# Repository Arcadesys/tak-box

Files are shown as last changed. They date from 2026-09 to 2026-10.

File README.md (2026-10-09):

# Tak box

A 3D-printed travel case for a 5 × 5 game of Tak, with interchangeable themed piece sets for custom gifts. The original pieces are Team Cat / Team Witch. Printed in PLA on an Elegoo Centauri Carbon 2.

## V26 — captive main hinges and tab-free boards

The corrected main hinges have a printed axle fixed between two supports on one half, trapping the other half’s central moving barrel. [Review the hinge section](v26/previews/17-main-hinge-section.png) and [print guide](v26/START-HERE.md).

[Review V26](v26/START-HERE.md) or inspect [the corrected kit](v26/V26-PRINT-KIT.zip). Three full plates contain the PIP case bodies with fixed guides and a captive hook, the full-size four-colour board pair, and optional matching flat capstones. Open the hook, then pull the boards freely; rigid seating shoulders replace the flexible release tabs. Modest 4 mm case and 2 mm board corner rounds retain the full field and original pieces. The user chose full plates before physical trials; strength, comfort and loaded transport still need observation. Earlier V25 kits and the V26 clip-trial archive are preserved.

## Preserved V25 PIP with fixed piece guides

The latest [fixed-guide prototype](v25/PIP-FIXED-GUIDES/START-HERE.md) has permanent positions for 21 flat stones and a capstone in each case half, joined to 3.4 mm integral floors. No removable trays. The two halves print together with captive 4 mm PIP pivots and full-height 8 mm roots. Original piece capacity, playing field, accent colours and outside size are retained. Digital checks do not establish physical fit, dumping or strength; cover-catch, lip and rounded-cover complete integration remain open. The earlier empty-well PIP plate, filament kits and V24 stay preserved.

## Preserved V25 square pockets and captive three-knuckle hinges

[The preserved prototype](v25/PIP-SQUARE-POCKETS/START-HERE.md) restores 21 square stone holders and a capstone holder per half, integrated into the 3.4 mm floor. Each hinge has two stationary outer knuckles joined by a 4 mm integral post, with the moving knuckle captured between them. Both halves print together as one assembly. The full field, pieces and outside size stay the same. Physical release, strength and transport remain unverified; cover-catch, broad lip and rounded-cover integration remain open. Earlier V25 kits and V24 are preserved.

## Current print kit: V24

[Download V24](v24/V24-PRINT-KIT.zip) and read [START-HERE](v24/START-HERE.md). Following the reported V23 hinge-support break, this revision uses broader full-height supports and two removable loaded player trays. The full 180 mm field remains; closed size is **102.5×200×35 mm**, adding 1.5 mm at the larger hinge barrels and 2.4 mm thickness for independent tray floors. Open **v24/FULL-PRINT** for the four sliced projects; **02-FULL-SIZE-FOUR-COLOUR-inlaid-boards-CC2-PLA.3mf** is the full board pair. Small tests are together in **v24/SMALL-TRIALS**. Four CC2 PLA plates include the **four-colour inlaid boards** (black, white and two silk accents), about **17 h 1 min / 327 g** with placeholder silk profiles; select actual silk profiles and reslice before printing. Separate hinge, tray-access and colour trials are included; physical durability and fit remain pending.

Replace both bases, both boards and the hook; add both trays. Existing original flats, supplied flat capstones and hook collar retain their geometry. The accepted celestial artwork is now adapted to V24 corner geometry and included in its default board project and assembled previews. See [the V24 checkpoint](docs/V24_CHECKPOINT.md).

V24 retains the previously delivered V23 R2 mechanics; this surface integration changes its board material geometry and slicing. The [V23 R2 kit](v23-r2/release/tak-v23-r2-print-kit.zip) remains preserved.

## Preserved V23 baseline

[Download the V23 print kit](v23/release/tak-v23-print-kit.zip), then open **v23/START-HERE.md**. Three CC2 PLA projects are together in **v23/PRINT**, with eight parts estimated at **11 h 38 min / 272 g**.

V23 is the accepted seamless-exterior design: centered recessed hook/catch/pivot, recessed board finger wells and rounded integrated hinge ends. It is a version-identity correction of the already checked design; geometry, printer settings and print behavior are unchanged. Closed envelope: **101×200×32.6 mm**, with the full 180 mm field, original 42 flats and solid 8 mm Cat/Witch capstones beneath sliding boards. Main hinges print captive; only the hook uses a filament pivot.

Replace both bases, both boards, hook and collar relative to original V22; flat capstones are unchanged. Prior CAD/motion/slice results are reused with equivalence evidence and a fresh package audit. Physical comfort, snag resistance, release, fit and loaded transport remain untested. The kit includes separate 26-minute hinge and 53-minute closure trials. See the [guide](v23/START-HERE.md) and [checkpoint](docs/V23_CHECKPOINT.md).

[Original V22](v22/START-HERE.md) is restored to the 111.8×220.2×32.6 mm corner-hook design; its [ZIP](v22/release/tak-v22-print-kit.zip) is unchanged. The previously V22-labelled seamless delivery is [archived](v22/release/archive/README.md). [V21](v21/START-HERE.md), [V20](v20/START-HERE.md), [V19](v19/START-HERE.md) and [V18](v18-case/README.md) remain historical and intact.

## Historical v17 architecture study: [four leaves on one common hinge](v17-four-leaf)

Two drawer housings and two board leaves share one hinge axis. Covered
sliding drawers keep flats enclosed while the leaves rotate. Board leaves
snap implementation was completed in v18; the [two-piece squeeze buckle](v17-squeeze-latch)
is historical. The 180 mm field and 36 mm pitch remain.

This is a CAD motion study, **not a full-print release**. Paired folding,
independent board rotation, original-flat envelopes, solids and exported
meshes pass the recorded sampled checks. Board snaps, drawer releases,
rear capstone hatch and case-closure integration remain unfinished. The
previous four-part draw-latch trial was rejected as confusing.
The main body is provisionally 101×236×32.6 mm, excluding closure hardware;
it is thinner but longer than v16. No final size saving is claimed yet.

The [screw-clamped draft](v17-compact-folio) was rejected and is history only.
The later pin/sleeve idea was also rejected; it is not the selected closure.

## Previous travel prototype: [v16 field book](v16-field-book)

The separate [full-size pagoda foundation](full-size-pagoda-v1/README.md) uses
25 × 25 × 10 mm weighted flats, scaled existing Fox/Cat capstones and a lift-out
5×5 board above two stacked trays. It is the new premium printed exploration;
v16 remains the travel prototype. Digital geometry and local slicing pass;
physical fit and transport retention remain untested.

The additive [compact home-board variant](home-board-compact-v1/README.md)
reduces both footprint and height to 240 × 232 × 43 mm by placing two narrower
cassettes side by side. The same 42 mm cells and full-size pieces are retained.
Digital geometry and local slicing pass; printed handling remains untested.

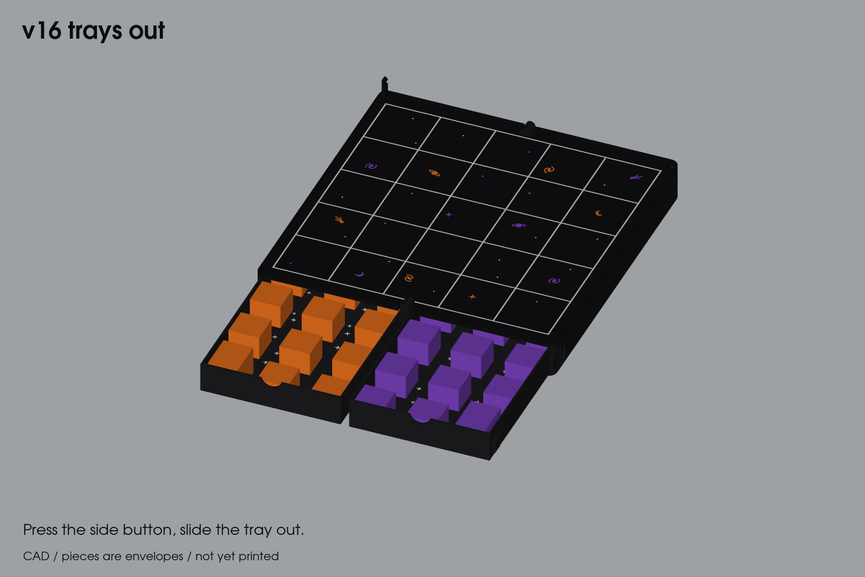
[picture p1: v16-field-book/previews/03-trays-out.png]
v16 open with trays out


The board folds in half with its face inside, and there's a snap-in piece tray under each half.
- **Closing:** a buckle at the far edge. Squeeze the side of the case to open it.
- **Board:** 5 × 5 at 36 mm cells, black with an inlaid white grid and subtle star, galaxy, planet, moon and comet inlays. A raised lip protects paint.
- **Assembly:** the board plates drop onto locating pegs and glue into shallow wells, so they line up without a jig.
- **Size:** 101 × 202 × 51 mm closed.

It has four multi-colour print plates. The user reports physical piece-retention
and closure failures; the exact printed component revisions are unknown.
See the [v16 README](v16-field-book/README.md) for retained plates and source;
its blanket unprinted statement is historical and superseded by those reports.

## Pieces: [pieces](pieces)

Piece designs live in separate packages so custom sets can share the box. Check each package's dimensions and tray compatibility before printing; the packages currently use different stone sizes.

The Cat and Witch flats and capstones, with CAD source, STLs and one CC2 print plate per team in [pieces/plates](pieces/plates).

The [weighted stone prototype](pieces/weighted-v1/README.md) adds 20 × 20 × 6 mm two-part stones for post-print ballast and epoxied floors, with a three-clearance fit coupon and one complete geometry plate per team. Physical fit and feel remain untested.

The [piece generator v1](pieces/piece-generator-v1/README.md) systematizes custom weighted teams from TOML presets: recessed engraving, side texture, solved ballast volume, a low-profile capstone, and a positive snap floor backed by adhesive. It generates a complete team plate plus a three-variant snap-fit coupon. CAD and mesh checks are automated; physical snap retention and tactile acceptance remain untested.

The [fox knurled flats](pieces/fox-knurled-v1/README.md) add 21 fox-themed 19.5 × 19.5 × 8 mm stones with recessed face emblems and diamond-textured sides. Sample and full-set CC2 plates are included. Geometry fits the current tray insert; physical fit and grip await a sample print.

The [reference-based Fox and Cat capstones](pieces/fox-cat-capstones-v4/README.md) follow a continuous carved nose-to-tail curl. This package contains the fuller Fox tail and the Cat's corrected neck/shoulder, printable STLs, a labeled two-object 3MF, retained reconstruction sources and large labeled previews. Digital v16 compatibility and dry slicing pass; physical fit and tactile acceptance remain untested.

## Archive

- [archive/v15-field-book](archive/v15-field-book): 28 mm cells. Too small to play on: you couldn't grab a stack once the board filled up.
- [archive/v14-field-book](archive/v14-field-book): the first field book, with 24 mm cells. A paper play test showed it was too cramped.
- [archive/v13-book](archive/v13-book): the first two-leaf book, with the M3 clasp.
- [archive/v5-v7](archive/v5-v7): the earlier open-wells, pin-board, hinge-coupon and center-closure designs, with their scripts, coupons and plates. Its [README](archive/v5-v7/README.md) describes v5.

Versions v11 (smooth case) and v12 (chest) live on their own branches: `feat/tak-v11-smooth-case` and `feat/tak-v12-chest`.

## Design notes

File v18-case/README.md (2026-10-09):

# V18 full build — side hook and filament hinges

**Print these five CC2-PLA projects for the complete case.** The user selected the simple side hook and pin on October 5. All four main leaves retain their common hinge axis and the full 180 mm playing field. [Download the complete kit](release/tak-v18-hook-and-pin-CC2-PLA.zip).

This is the first full print of this revision. The earlier clasp trial was printed; the new side hook and complete case have not been physically accepted. No printer job was started.

## Five print plates

| Plate | Contents | Orientation |
|---|---|---|
| [01 — Left housing](plates/01-left-housing-hook-pivot-and-cap-compartment-CC2-PLA.3mf) | Housing, hook pivot, capstone compartment and fixed hatch hinge | Rear end down |
| [02 — Right housing](plates/02-right-housing-and-hook-pin-CC2-PLA.3mf) | Housing and headed hook pin | Rear end down |
| [03 — Boards](plates/03-board-leaves-CC2-PLA.3mf) | Both board leaves and external release clips | Playing faces up |
| [04 — Drawers](plates/04-piece-drawers-CC2-PLA.3mf) | Both 21-flat drawers, catches, stops and grips | On their sides |
| [05 — Hatch and small parts](plates/05-hatch-hook-and-five-axle-caps-CC2-PLA.3mf) | Hatch, separate side hook and five axle collars | Hatch axis upright; hook flat; collar bores upright |

**13 printed parts, five plates.** Use this kit together: the previous clasp slider is not used. Existing v16 interfaces stay unchanged. The previous 3 mm axle kit remains archived.

## Printer settings

- **Elegoo Centauri Carbon 2, 0.4 mm nozzle**, 256 mm build volume.
- Retained starting material: **Generic PLA, 210 °C nozzle / 60 °C textured PEI**. Select the actual tested spool preset and reslice if it differs.
- **0.20 mm layers, four requested walls, 20% gyroid, 6 mm brim**, automatic normal supports, 30° support threshold, three upper interface layers and 0.20 mm contact gaps. Housing objects use 0.8 mm side clearance from supports; other parts use 0.35 mm. Preserve these object settings when reslicing. Thin spring sections resolve as solid narrow walls.
- Keep the supplied orientations. Housings print rear end down to keep supports out of the drawer tunnels. The hook prints flat. Do not scale the parts to adjust fit.
- The slicer retains a warning: Generic PLA has a 45 °C softening entry against a 60 °C bed. These are starting settings, not a qualified spool profile.

The retained profile estimates **32 h 18 min / 499 g** total, including support and brims. See [slicing.json](reports/slicing.json) for individual plates.

Fill the recessed grid with a high contrast finish, such as opaque white on a dark board. Keep paint within the 0.6 mm grooves so the playing surface stays flat.

## Cut four filament pins

Use straight, undamaged **1.75 mm PLA filament**. Cut square and remove burrs:

| Location | Length | Printed collars |
|---|---:|---:|
| Front main hinge | 24.9 mm | 1 |
| Rear main hinge | 24.9 mm | 1 |
| Capstone hatch | 92.0 mm | 2 |
| Side-hook pivot | 9.6 mm | 1 |

Main, hatch and hook bores are nominally **2.0 mm**; collar bores are **1.9 mm through holes**. These are design clearances, not measured printed fits. Check each bore with a short filament segment before assembly; it must pass without force.

## Assembly

1. Remove supports and brims. Check the drawer tunnels, board clips, pin bores, headed catch and hook throat. Deburr gently; do not round off retaining shoulders.
2. Arrange **left housing, left board, right board, right housing** flat, with their individual hinge knuckles interleaved along the common axis. Capstones go at the rear and drawer grips at the front.
3. Insert the two 24.9 mm main pins from the outside ends. Each outer collar receives approximately 2 mm of filament and sits about 0.5 mm clear of the barrel. The pins end short of the playing field. Dry-fit every leaf first. To stop withdrawal, bond each pin only at its exposed outer housing barrel: **left housing at the front, right housing at the rear**. Keep adhesive out of the other three moving leaves. Bond the collars to the pins. The passages have no hidden internal stops.
4. Fit the hatch between its rear ears, insert the 92 mm pin and bond that pin at one fixed housing ear only. Bond both collars to the pin with approximately 2 mm insertion and 0.5 mm clearance from the ears. The hatch must rotate freely.
5. Fit the side hook on the left housing pivot, with its mouth facing the rear when upright. Insert its 9.6 mm filament pin from outside and bond the inner end in the fixed mount. Fit the outer collar with approximately 2 mm insertion. Unlike the main hinges, this collar **lightly contacts the hook**: set it for smooth thumb movement with enough friction to hold its position, then bond it to the pin. Keep adhesive off the hook and bearing faces. There is no spring detent; check this friction after repeated use.
6. Insert each drawer from the front. Press its rear stop arm inward to pass the housing stop, then release it. Press the broad outer catch while seating the drawer fully; it must latch before folding.
7. Pull both external board clips outward while lowering each board onto its housing; release them into their pockets. Both playing faces must sit flat.
8. Test the empty case, then load the exact original Cat/Witch set. Use [ACCEPTANCE.md](ACCEPTANCE.md) to record fit, comfortable release and loaded retention. Do not force a sticking joint.

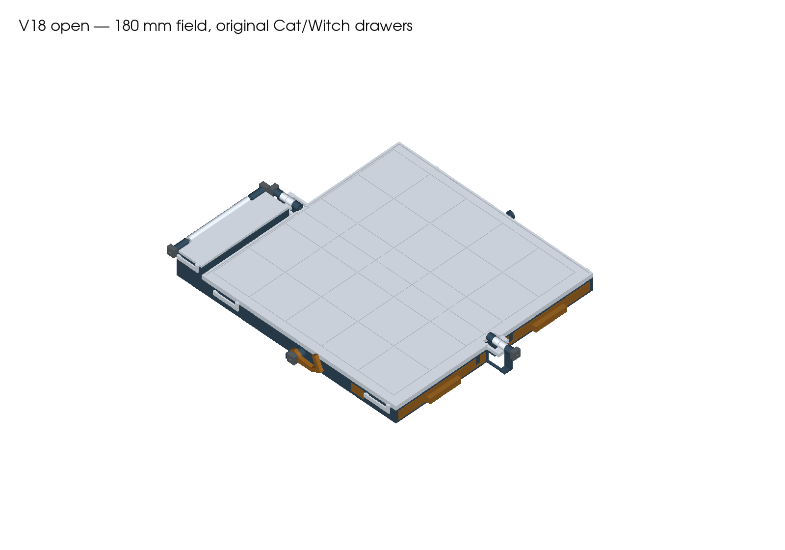
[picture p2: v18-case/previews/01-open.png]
Full case open, rendered from exported geometry


## Close and open

Seat both drawers, close the hatch and engage both boards. Swing the side hook toward the drawer end, fold the right housing and board closed together, then swing the hook upright over the headed pin. The pin's head keeps the hook from slipping off sideways; the hook shoulder blocks separation.

To open, gently squeeze the case halves together to unload the hook, then swing it **65° toward the drawer end** using the broad tab. Unfold the right pair. The hook has a reverse stop and an adjustable friction pivot. Physical testing must establish whether that friction reliably prevents accidental rotation during carrying; the digital opening check establishes geometric engagement only.

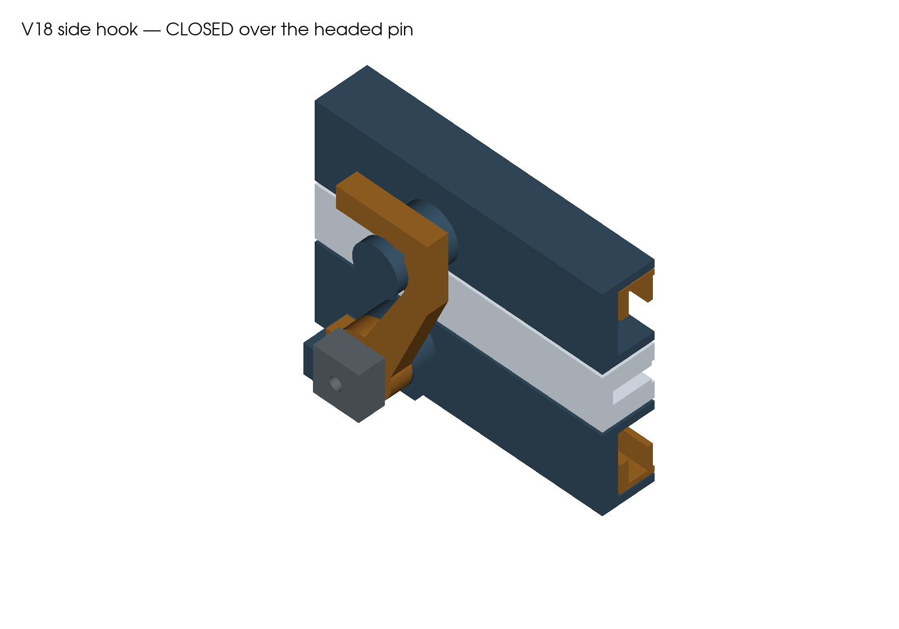
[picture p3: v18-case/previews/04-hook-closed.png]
Side hook closed

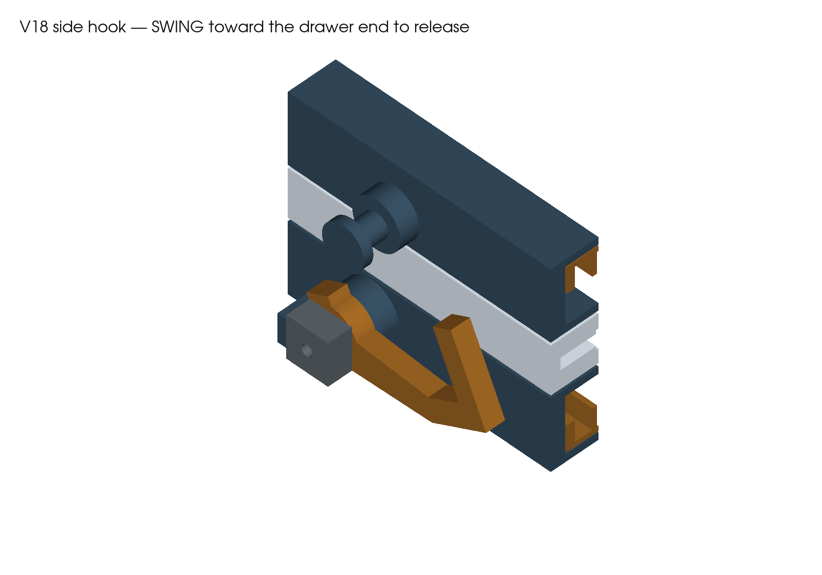
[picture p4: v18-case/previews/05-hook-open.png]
Side hook released


- **Drawers:** press the broad side button and pull the front grip. The stop at 168 mm exposes all 21 flats. Support the drawer on the table. To remove it deliberately, press the rear stop arm inward as it reaches the opening.
- **Board maintenance:** release both clips before rotating a board independently; leave them engaged during normal play and folding.
- **Capstones:** pull the external hatch clip outward and lift the hatch. Two 12 mm floor ports allow an upward finger push to aid retrieval.

## Pieces and compatibility

The field remains **5×5, 180 mm across, 36 mm pitch**. This build checks detailed original Cat/Witch CAD from `pieces/tak_pieces.py`: 42 flats at **20×20×8 mm**, 20.7 mm seats and 0.4 mm roof clearance. The original capstones lie in the rear compartment. The original Cat capstone STL has an open mesh, so its valid detailed CAD is used for fit checks. No piece exports changed.

Weighted flats and curled Fox/Cat capstones remain unverified here; the existing weighted-stone/current-insert mismatch stays explicit. V16 parts and the premium pagoda are separate. The earlier trial clasp is retained as history. New housings and filament-bore parts replace the previous integrated clasp/3 mm axle geometry; the drawers retain their dimensions.

Closed envelope including all hardware: approximately **112.3 × 245.8 × 32.6 mm**. The playing field has not been reduced.

## Evidence and reproduction

The reports check valid single solids, STEP/STL and named-object 3MF readback, original-piece fit, sampled loaded folding and releases, hook engagement, filament hardware clearances and actual sliced pin passages. Sampled motion is not a continuous sweep proof. Spring deflection poses do not establish force or fatigue. First-print fit, support removal, strength and transport retention remain physical tests.

Use Python 3.12 with [requirements.txt](requirements.txt), plus installed macOS ElegooSlicer:

```sh
python v18-case/source/build_case.py
python v18-case/source/verify_field.py
python v18-case/source/verify_hardware.py
python v18-case/source/package_case.py
python v18-case/source/slice_case.py
python v18-case/source/render_case.py
python v18-case/source/inspect_case_layers.py
python v18-case/source/verify_pin_toolpaths.py
python v18-case/source/record_provenance.py
python v18-case/source/package_release.py
python scripts/verify_v18_freeze.py
```

After rendering new toolpaths, review them and record observations in `reports/layer-inspection.json` before running the provenance check. Current commands, environment, limitations and repaired failures are in [BUILD-PROVENANCE.md](BUILD-PROVENANCE.md). Source and final payload hashes are pinned in the manifest. The original recessed-clasp package remains byte-for-byte frozen.

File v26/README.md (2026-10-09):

# V26 print plates — captive main hinges and tab-free boards

The main hinges now use the user-confirmed arrangement: each **4 mm printed axle permanently joins two supports on the fixed half**, trapping a **3.2 mm central moving barrel** on the opposite half. Each fixed support is **2.5 mm wide**, with **9 mm outer barrels**, full-height **8 mm roots** and nominal **0.4 mm radial and face gaps**. The case prints as one captive assembly.

[Start printing V26](START-HERE.md) or [download the complete kit](V26-PRINT-KIT.zip). **FULL-PRINT** contains the joined case/hook assembly, the full four-colour board pair and the matching flat capstones. Current total estimate: **17h 46m / 288.66 g PLA**, including the optional capstones.

V26 adds modest outside corner rounds: **4 mm on the case** and **2 mm on the sliding boards**. The inlays, full field and hinge supports stay intact. Review the [corner detail](previews/18-rounded-corner.png).

V26 removes the flexible sliding-board catches. Opening the captive case hook lets the boards slide outward without pressing a release tab. Each board has a rigid **4 × 6.1 × 4.7 mm seating shoulder** outside the playing field; it meets the front rail to stop inward travel and moves away from the rail during withdrawal. The original bevelled board margin replaces the old clip window.

The hook uses a **4 mm fixed axle**, two fixed cheeks, a **2 mm outer cheek** and a **3.4 mm frame bridge**, with nominal **0.4 mm radial and face gaps**. Its broader bearing and integral printing foot print parked at 90° with the case. PIP main hinges, **3.4 mm floors**, **21 flat guides plus one capstone guide per side**, the full **180 mm / 36 mm-cell field**, original four-colour inlays and **102.5 × 200 × 35 mm** closed size remain. No loose hook pin/collar or removable tray.

Clearance checks use **42 original Cat/Witch 20 × 20 × 8 mm flats and the two supplied 8 mm V23 flat capstones**. Weighted and sculpted pieces are not qualified. Replace the V24/V25 bodies and covers for this integrated kit; the original flats and supplied flat capstones retain their geometry. The new covers retain the V26 mechanism-review case/hook interface in CAD.

The user explicitly chose full plates before small physical trials. The revised main hinge passes **947 integrated solid, loaded slide/fold, capture, seating-stop and export checks**, **51 exported geometry audits**, **15 named mesh/3MF readbacks**, and **37 sliced main-hinge/hook gap and support checks**. Sliced support-face gaps are at least **0.32 mm** under a conservative 0.50 mm bead-width assumption. The rounded board and capstone plates are rebuilt from exported CAD with **62 plate checks**; all four inlay roles retain their original geometry. Reports identify current source, project and profile hashes. Physical strength, wear, comfort and loaded transport remain unobserved. No printer job is dispatched. The earlier rounded-cover underside request remains pending.

Build with the bundled dependency versions in `reports/full-provenance.json`: CadQuery 2.7 / Python 3.12 and ElegooSlicer 2.4.2 on the recorded host. Run `source/build.py`, `source/plates_full.py`, `source/verify_review.py`, `source/slice_full.py`, `source/verify_colour.py`, `source/render.py`, `source/package_full.py`. `source/slice_full.py --verify-only` reads back existing full projects without reslicing. Full source, reference STEP parts, profiles, named meshes, raw plates and checks are retained with the kit.

[Game](previews/01-game-open.png) · [Tab removed](previews/02-board-clip.png) · [Hook cutaway](previews/04-hook-section.png) · [Closed](previews/05-closed.png) · [Fixed guides](previews/06-fixed-guides.png).

The earlier [mechanism review archive](V26-MECHANISM-REVIEW.zip), individual trials and combined clip/hook trial are preserved unchanged as history. Their flexible clip is superseded by the current tab-free covers. Rebuild those historical trials from the source inside that archive, rather than the current `source/build.py`. All V25 packages and the user extraction remain intact.

The superseded opposed-pivot full kit and case project are preserved under `archive/previous-main-hinge`. Current geometry evidence is `reports/geometry.json` and `build-double-supported-rounded.log`; `build-double-supported.log` records the pre-rounding captive hinge and `build-full.log` records the earlier tab-free build. The isolated ZIP check audits all payloads and rebuilds board/capstone raw plates from bundled STEP references; it does not independently rerun the full case CAD or slicer.

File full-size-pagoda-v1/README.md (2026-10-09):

# Full-size Tak — pagoda foundation

An additive board-and-storage foundation for the exceptionally ornate printed
direction: **a clear 5×5 board above two removable, stacked piece cassettes**.
Existing v16 parts and all older piece packages are unchanged. This is the shape
to constrain future witch-and-cat, energy-vine and galactic ornament.

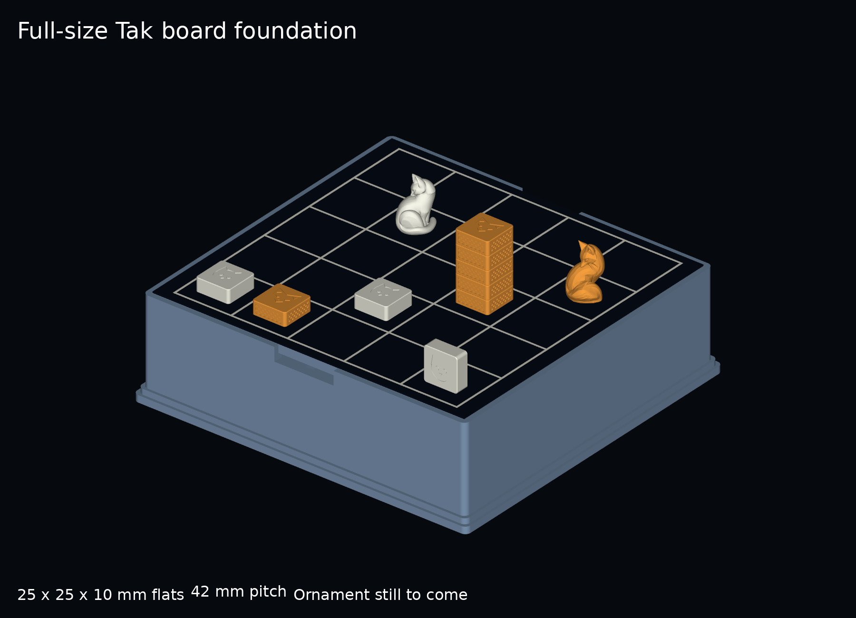
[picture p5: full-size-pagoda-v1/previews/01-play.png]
Actual geometry with full-size pieces


## Dimensions

| Component | Dimensions in mm | Status |
| --- | --- | --- |
| Cat, Fox and optional Witch flats | 25 × 25 × 10 finished envelope | Exact CAD envelope; body, closure and felt allowance included |
| Playing field | 210 × 210; 5×5 at 42 mm pitch | 17 mm between adjacent centered 25 mm flats |
| Lift-out board backing | 232 × 224 × 6 | 0.3 mm seat clearance per side; broad front/back grips |
| Each player cassette | 120 × 174 × 30 body; 31 including locating pins | 21 flats and one sideways capstone; print twice |
| Printed platform | 248 × 240 × 72 | Three low stepped terraces; removable board above storage |
| Felt playing surface | 1 mm allowance; top at 73 mm | Measure actual felt plus adhesive before assembly |
| Cat capstone | 21.785 × 25 × 33.809 | Uniformly scaled final Cat v4 sculpture |
| Fox capstone | 22.694 × 24.782 × 35 | Uniformly scaled final Fox v3 sculpture |

The capstones retain their carved looking-back curl and remain taller than
the square flat stones. Their proportions are preserved by uniform scaling;
their existing solid construction remains. Capstone ballast cavities are a
separate unresolved design step.

## Pieces and closure

The Cat/Witch emblems come from `pieces/tak_pieces.py`. The Fox emblem and side
knurl come from `pieces/fox-knurled-v1/source/flats.py`, scaled to the new size.
All three regular stones use the weighted package's two-part closure approach,
adapted to 25 mm width and 10 mm finished height. The Fox knurl remains recessed,
so it adds no width. The cavities accept post-print ballast. Select fill and
adhesive using handling samples; kinetic sand is the requested material.

The nominal stone has a 1 mm closure floor starting 0.7 mm above the base,
a 0.6 mm felt patch, and 0.1 mm adhesive allowance. The body rim and felt finish
at z=0; the top finishes at z=10. Minimum roof below the 0.5 mm emblem recess
is 1 mm. The floor locates with **0.2 mm clearance per side** and a 0.1 mm
shoulder adhesive gap. These are CAD allowances, not measured printed fits.

Print bodies broad top down and cavity up using `*-body-print.stl`; the
`*-body-assembly.stl` files are upright assembly references. Floors print flat,
locating tongue up. Do not print the felt or assembled STEP references as a
single fused object.

## Files and first sample

- [Closure coupon](plates/closure-coupon.3mf): three Cat bodies and three floors
  with 0.15, 0.20 and 0.25 mm side clearance, labeled in the 3MF object names.
  Keep each printed floor associated with its object label.
- [21 Cat bodies](plates/cat-flats-21.3mf) and [21 Fox bodies](plates/fox-flats-21.3mf).
- [21 floors](plates/floors-21.3mf): print two copies for the full Cat/Fox set.
- [Fox/Cat capstones](plates/fox-cat-capstones.3mf): two scaled existing sculptures.
- [Piece cassette](plates/tray.3mf): print two copies; the existing `tray` filename is retained.
- [Platform](plates/platform.3mf).
- [Felt backing](plates/board-felt-backing.3mf): flat support for the felt surface.
- [Grooved board option](plates/board-grooved-option.3mf): separate alternative,
  with 1.4 mm wide, 0.6 mm deep grid grooves; finish them in a contrasting colour.
- [Full-scale grid](models/felt-grid-100-percent.svg): 232 × 224 mm, for a
  print/stencil/transfer onto the felt. Print at 100% and measure the 42 mm pitch.

These tracked 3MFs contain **named millimetre geometry**, without embedded print
settings or G-code. Local sliced proof projects are in ignored `.slicer-work/`.
Individual STL and editable STEP files are in `models/`; sculptural capstones
remain mesh source, as in their original package.

Start with the closure coupon, two Fox bodies, one capstone pair and one tray.
Check the finished felt thickness, fill retention, grip, stacking, standing-wall
stability, capstone pocket fit and support cleanup. Check full five-stone carries
on the 42 mm printed paper grid before committing to the platform.

## Setup and reserved space

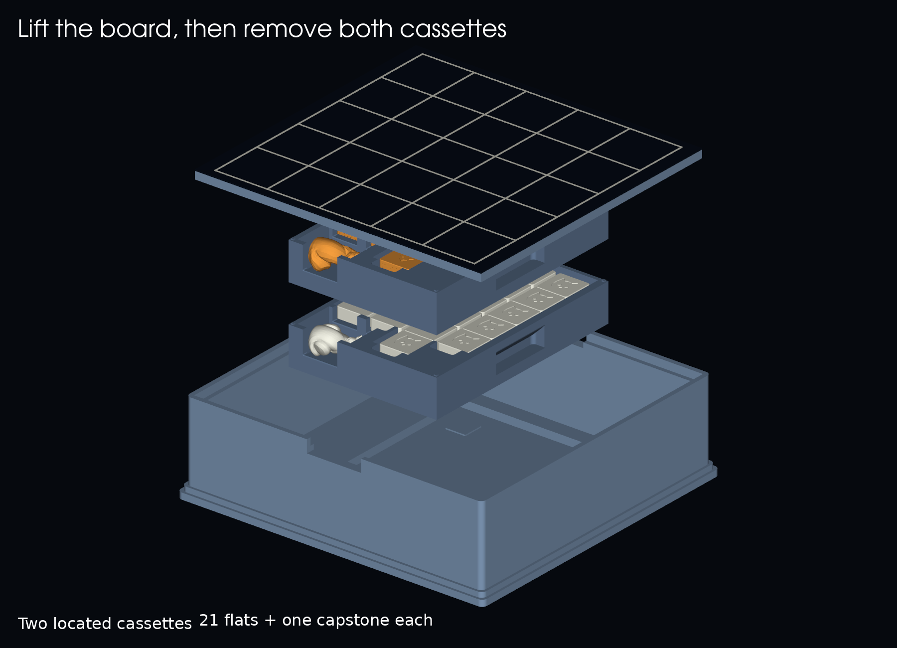
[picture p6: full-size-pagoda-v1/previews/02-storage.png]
Board and loaded trays separated vertically


Lift the board using the two 44 mm front/back grip openings, remove the upper
then lower cassette, set them beside the platform and reseat the board for play.
Each cassette carries one player's 21 flats and capstone. **These are open
carriers in this revision**, covered by the upper cassette and board when
packed; they do not have separate lids.

The flat rows hold **5 + 5 + 6 + 5 stones**. The third row extends forward
beside the capstone; there is no separate 21st-flat pocket. Its slot is 151 mm
long, while the five-flat slots are 126 mm long, each leaving 1 mm total end
clearance. The capstone compartment footprint and cassette outside dimensions stay the same.

**Raised flat seats:** the lane floors are at z=18 mm rather than z=2 mm.
Finished flats reach z=28 mm, just **2 mm below the 30 mm perimeter rim**.
They project 8 mm above the dividers. A 20 mm wide finger notch at the front
of each row exposes 8 mm of the first stone's edge, so it can be lifted without
digging into a deep well. Test actual
finger access, especially after some stones have been removed, before a batch.

**Capstone access:** the capstone floor is raised from z=2 to z=5 mm. A **28 mm
wide opening** through the cassette's front wall exposes the curled body from
the side. Its lower edge is at z=12 mm, leaving approximately 15 mm of the
capstone above that edge. The Cat and Fox tops are respectively 3.2 and 2.3 mm
below the rim. Grasp the body through this opening, rather than hooking an ear
or tail tip. Shape, plan position and the 43 × 32 mm pocket footprint are retained.

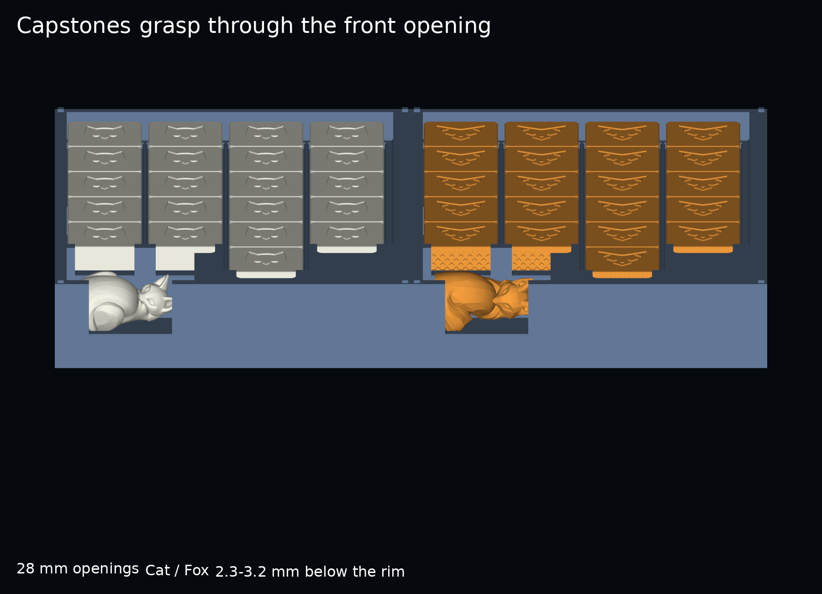
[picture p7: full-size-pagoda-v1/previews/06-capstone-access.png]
Cat on left and Fox on right, accessible through the front openings


The lower cassette rests on four 16 mm square supports within a low locating
frame. The frame leaves 0.4 mm clearance per side. The upper cassette rests
on the lower perimeter rim, with four 2 mm square, 1 mm high pins entering
2.8 mm square, 1.2 mm deep sockets in its underside. These locate the stack
without a latch; both cassettes lift straight up. There is no cushioning yet.

**Cassette comfort revision:** dividers finish at z=20 mm, leaving 8 mm of
flat edge exposed as rows empty. The divider tops, row-front openings and
capstone finger ledge have 0.5 mm chamfers. Two side recesses replace the
previous shallow dishes: each is nominally 50 mm wide and 10 mm deep, with its
mouth from z=8 to z=24 mm. The 45-degree roof slopes down inward, leaving a
4 mm seat thickness at its deepest point and a nominal 6 mm rim above the
mouth before the 0.5 mm edge chamfer.
The long upper mouth edges also have 0.5 mm chamfers. These are recessed grips
for a two-handed lift; they add no outside width.

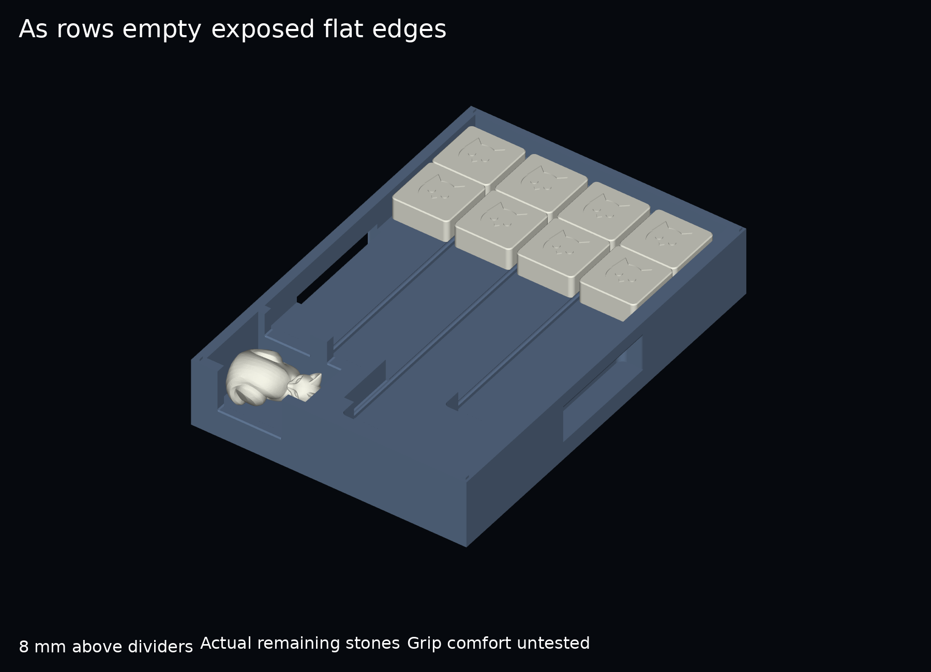
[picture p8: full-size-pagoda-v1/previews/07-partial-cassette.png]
Partly emptied cassette with exposed flat edges


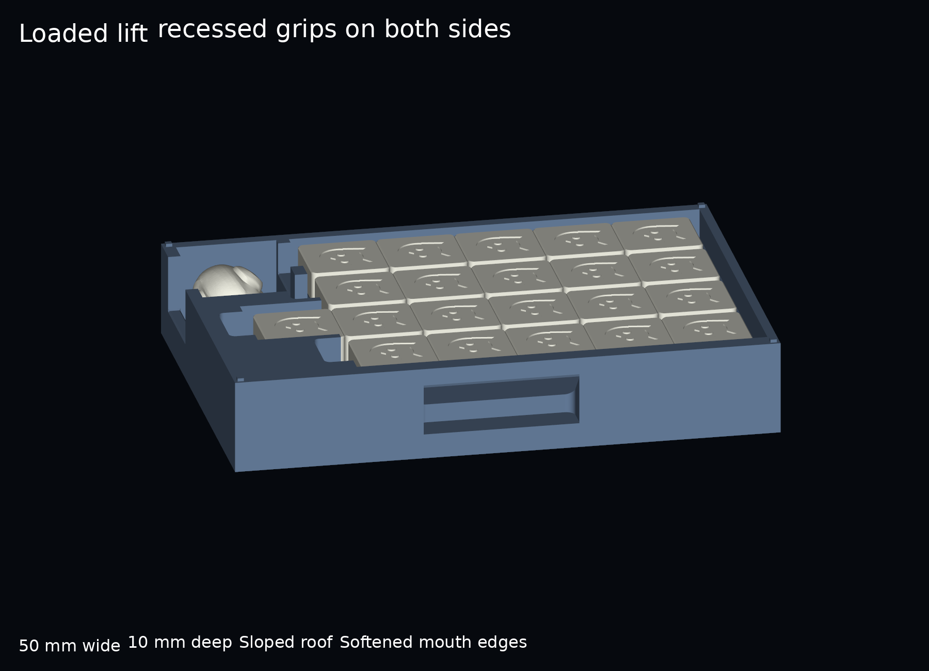
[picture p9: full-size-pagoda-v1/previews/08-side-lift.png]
Loaded cassette and broad side grip


The new cassette retains the previous outside size, capstone seats and stack
pins/sockets. It digitally registers with the previous cassette and platform;
printed compatibility remains untested. First print **one revised cassette**,
load all 21 finished flats and a capstone, then test a two-handed lift, removing
the first/middle/last stones, capstone body grasp and stacking/release against
an existing cassette if available. Check for flex at the grip rail before a
second print; stop if there is cracking, discomfort or unstable retention.

Both capstones lie below the next cassette floor, leaving at least 2.3 mm
modeled headroom. The upper rim is 2 mm below the board backing, and its
locating pins remain 1 mm below it. All flats remain 25 × 25 × 10 mm and have
2 mm modeled clearance beneath the next cassette's underside.

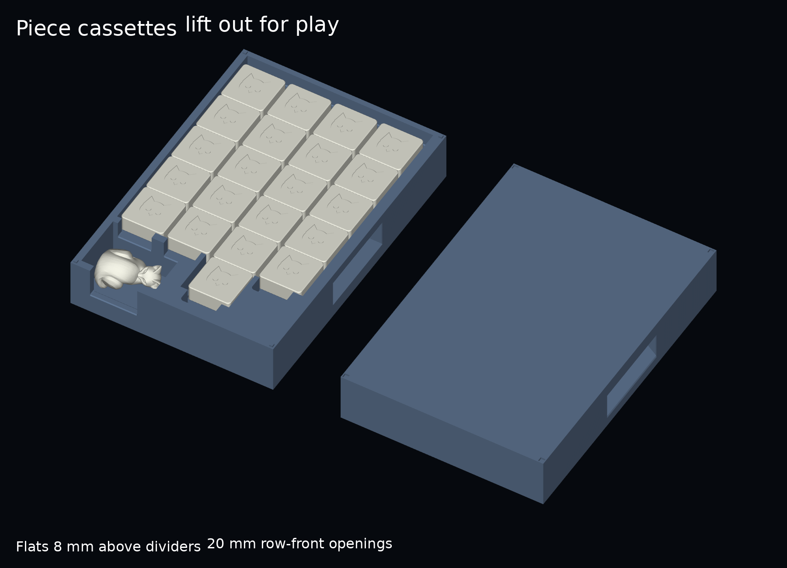
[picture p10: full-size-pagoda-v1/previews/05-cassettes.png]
Loaded cassette and its matching underside


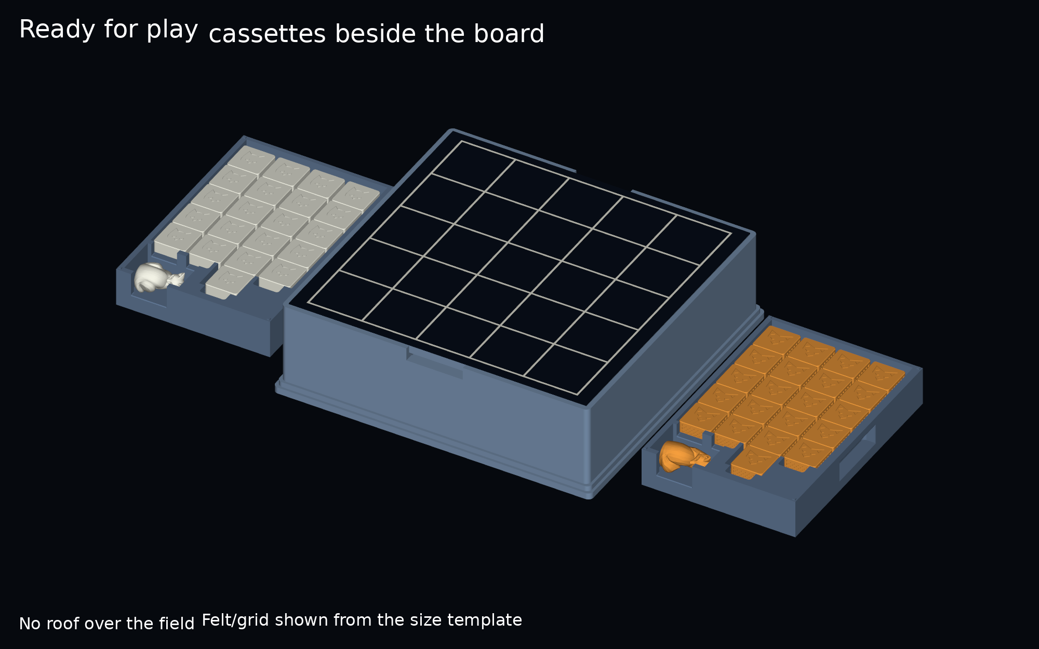
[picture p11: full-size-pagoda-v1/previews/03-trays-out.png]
Loaded trays beside the board


Future ornament must stay outside the board seat, lift openings, loaded-tray
volume and removal paths. Keep all artwork below the playing surface, with no
roof above the field. Prefer broad cat/witch reliefs, thick energy vines and
large galactic forms. The stepped shell is intentionally plain in this pass.

**Transport retention remains unresolved:** there is no latch, transport lid,
cassette lock or spill-free carrying claim. Treat this as a stationary prototype
until those details and physical handling are tested.

## Verification and cost

[Geometry/mesh/3MF report](reports/verification.json): 13 valid watertight,
consistently wound, single-component mesh parts; 9 named millimetre 3MFs with
matching dimensions, object names and volumes. All 21 exact Cat and Fox body,
floor and felt solids have zero tray overlap. Actual capstone mesh bounds are
fully contained by their carved pockets. Stacked trays and seated board have
zero CAD overlap. Nine vertical offsets check board-first, then tray removal.
Capstone source hashes and uniform scale factors are recorded. Additional
checks establish lower-support and stacked-rim contact, pin/socket clearance,
and zero collision at four sideways offsets of ±0.39 mm within the 0.4 mm
allowance. Physical registration and release still need a cassette pair test.
All 21 raised stone seats also pass a contact probe: each piece rests on its
seat rather than floating above it. No loaded flat extends into the next
cassette floor. Both new grip volumes are clear, solid seat-ledge witnesses
pass, and old/new cassette pairs pass support/contact, lateral and vertical
removal checks in both stacking orders.

[Slicer report](reports/slicing.json): the revised raised-seat cassette was
freshly sliced; eight unchanged plates reuse prior successful evidence with
matching committed input hashes. All 9 local checks pass using the
repository Centauri Carbon 2 / 0.4 mm nozzle profiles. Flat bodies/floors use
PETG, 0.2 mm layers and 100% infill; structural parts use PLA, 0.2 mm layers,
four walls and 20% infill; the scaled capstones use PLA, 0.12 mm layers and tree
supports. Every object is on the bed with no outside-bed condition. Only the
capstone plate uses supports. Do not reuse profiles blindly for another printer.

The unornamented platform alone is estimated at **491 g PLA and 9 h 30 min**.
Each revised cassette is estimated at **182 g and 3 h 25 min**; the felt
backing at 185 g and 3 h. Raising the seats adds about 36 g per cassette compared
with the previous deep-row design. No supports are used in the cassette slice.
These are slicer estimates, not measured prints. The shell is a stiffness-first
foundation; material reduction should be considered during ornament design.

All eight previews were rendered from the exported meshes. Felt and its grid
are dimensioned visual references to the SVG template. Rendered labels are
large and high contrast. Digital verification does not establish physical
fit, rigidity, tactile readability, release, retention, wear or comfort.

## Rebuild

From the repository root, with Python 3.12 and
`full-size-pagoda-v1/source/requirements.txt` installed:

```sh
python full-size-pagoda-v1/source/build.py
python full-size-pagoda-v1/source/render.py
python full-size-pagoda-v1/source/slice_check.py
```

The slice command requires installed macOS ElegooSlicer and never sends a job
to a printer. Build/render reuse tracked source files from `pieces/` and
`v16-field-book/source/mesh_export.py`; retain those paths when copying this
package. Source revision, dependency environment and commands are recorded in
[provenance](reports/provenance.json).

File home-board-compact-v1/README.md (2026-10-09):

# Compact Tak home board

A separate **240 × 232 × 43 mm** home-board variant, with two removable
cassettes side by side beneath the same lift-out playing board. Compared with
the stacked version, its packed footprint is 6.5% smaller and its height is
41.1% lower. The 210 × 210 mm playing field, 42 mm cells and existing full-size
25 × 25 × 10 mm pieces stay unchanged.

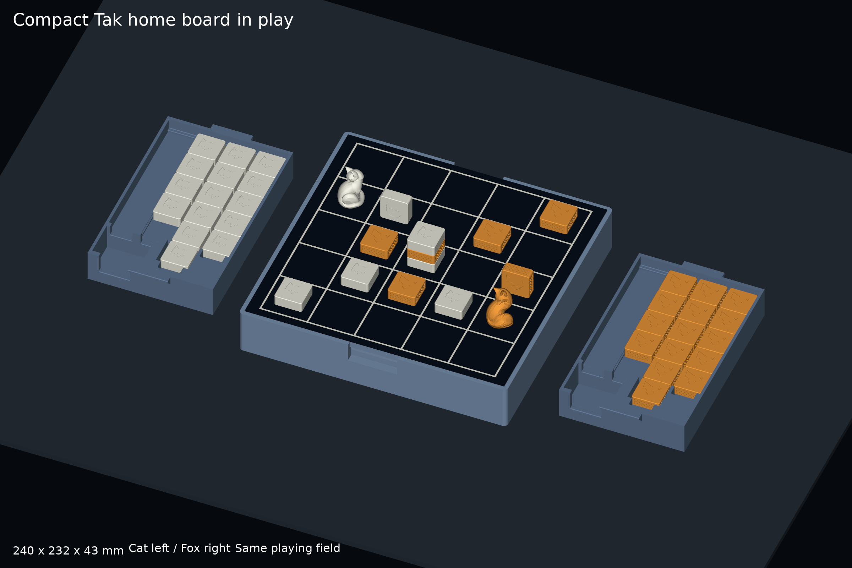
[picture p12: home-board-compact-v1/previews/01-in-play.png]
Compact box in play


## Dimensions and compatibility

| Component | Dimensions in mm | Evidence |
| --- | --- | --- |
| Platform | 240 × 232 × 42 | Valid CAD, watertight mesh and local slice |
| Packed height with felt allowance | 43 | Existing 1 mm surface allowance; measure actual felt/adhesive |
| Playing field | 210 × 210; 42 mm pitch | Exact existing backing and grid dimensions |
| Shared board backing | 232 × 224 × 6 | Byte-identical STEP/STL/3MF to the full-size package |
| Each cassette body | 112.2 × 174 × 30 | Two cassettes on one level; 0.8 mm middle gap |
| Cassette including lift tabs | 112.2 × 186 × 30 | Tabs add 6 mm at front and rear |
| Each lift tab | 36 wide, 6 projection | Sloped underside; 2 mm tip before 0.5 mm chamfer |
| Capstone pocket | 43 × 32; seat at z=5 | Existing chamber dimensions and sideways sculptures retained |
| Capstone front opening | 28 wide; bottom at z=12 | Existing body-grasp opening with 0.5 mm edge chamfer |

Use the [existing full-size piece package](../full-size-pagoda-v1/README.md),
including its weighted Cat/Fox flats, closure coupon and scaled capstones.
The shapes, ballast construction and proportions are unchanged. These pieces
do not fit v16's older travel-tray lanes.

The existing full-size board fits this new platform digitally. The new
platform and narrower cassettes are a separate geometry set; they do not
replace the stacked-cassette interfaces. Older packages remain intact.

## Packing and access

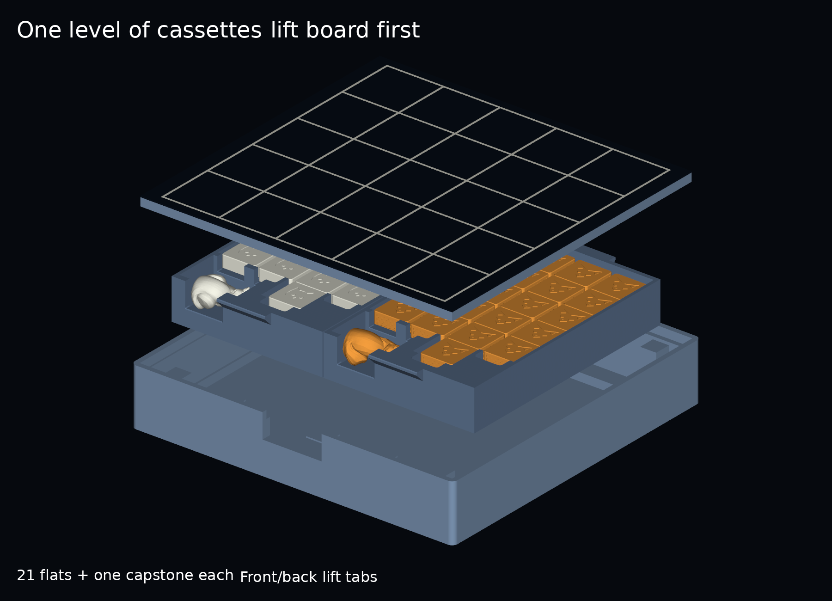
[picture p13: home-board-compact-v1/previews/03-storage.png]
One level of loaded cassettes


Lift the board using the 44 mm front/back openings, which now reach **12 mm
below its underside**. Grasp a cassette's front and rear tabs, lift it straight
out, then remove the other cassette. Set both beside the box and reseat the
board for play. Repack by lowering either cassette into the low locating frame,
then the other, then replacing the board. No component rotates while loaded.

Each cassette holds 21 flats in rows of **5 + 5 + 6 + 5**, plus one capstone.
Rows retain 0.3 mm side clearance per stone and 1 mm total end allowance.
Flat seats remain at z=18, with 8 mm of each flat above the lowered dividers.
Row-front openings remain 20 mm wide. Divider/front-notch edges use a 0.4 mm
chamfer; the narrower geometry failed the previous 0.5 mm chamfer, so the
smaller bevel was independently checked. The approved capstone opening and
its 0.5 mm bevel retain their dimensions.

The side grips are replaced by front/back tabs because side finger space is
unavailable in the compact packing arrangement. Each tab has a 45-degree
underside for printing without a horizontal bridge and a softened outer lip.
It leaves a nominal 16 mm end corridor inside the shell. There are no stack
pins in this single-level variant.

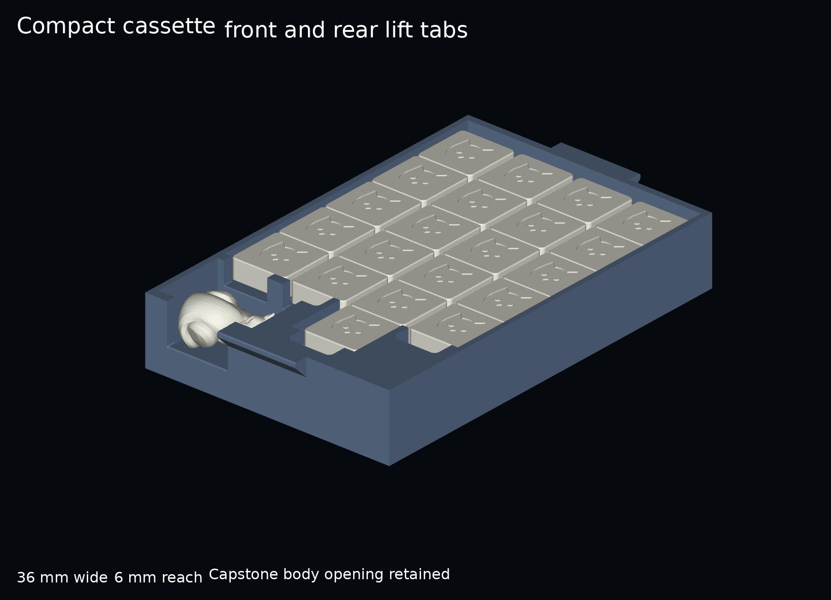
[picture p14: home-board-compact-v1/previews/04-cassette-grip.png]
Cassette front/rear tabs


Four **12 × 12 mm support pads**, together with the perimeter ledge, contact
the board. They stand outside the cassette footprints and finger corridors.
The board is 4 mm above the loaded flats; Cat/Fox capstones have respectively
5.2/4.3 mm modeled clearance below it. Nominal fit allowances are not measured
printed fits.

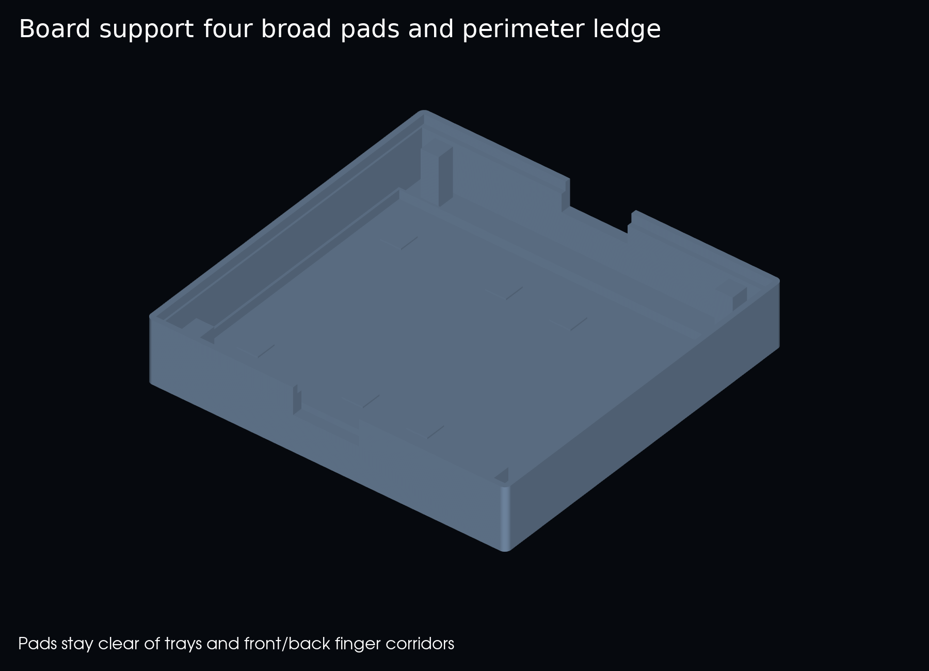
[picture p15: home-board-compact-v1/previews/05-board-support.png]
Empty platform with support pads


**Transport retention remains unresolved.** The board and cassettes are open,
lift-out parts with no latch, enclosing lid or cushioning. Vertical repacking
checks do not establish spill-free carrying.

## Files and small first trial

- [Grip coupons](plates/grip-coupons.3mf): actual sections of the new front and
  rear tab geometry, with distinct object names. Print these first to assess
  contact edges, under-lip access and print quality. Estimated together at
  **19 g PLA / 31 minutes**. Coupon success does not establish full loaded strength.
- [Cassette](plates/tray.3mf): print one for a loaded-lift trial before its mate.
- [Platform](plates/platform.3mf).
- [Shared felt backing](plates/board-felt-backing.3mf).
- [Shared grooved option](plates/board-grooved-option.3mf).
- [Existing full-size flat/capstone plates and closure trial](../full-size-pagoda-v1/README.md#files-and-first-sample).
- [Exact-size felt grid](../full-size-pagoda-v1/models/felt-grid-100-percent.svg).

These are named, millimetre geometry 3MFs, without embedded settings or G-code.
STL and editable STEP files are in `models/`. The sideways `*-storage-reference`
meshes illustrate packing; print the existing upright capstone files instead.
Sliced proof projects and logs stay in ignored `.slicer-work/`.

## Verification

[Verification report](reports/verification.json): 8 valid, watertight,
consistently wound, single-component meshes and 5 named geometry 3MF readbacks.
All 21 exact Cat and Fox body/floor/felt solids fit their new seats with zero
overlap; contact probes confirm support. Conservative actual-mesh capstone
bounds fit the chambers. All 21 flat envelopes clear three vertical positions.

The board and both cassettes have zero seated overlap with the shell or one
another. Support contact, four lateral samples and nine vertical positions
pass, including removal of either cassette while its neighbour remains packed.
Two simultaneous inward shifts leave the centre gap clear. Solid tab-join
witnesses pass; this is a CAD connectivity check, not a strength result.

The board openings and cassette end corridors clear **28 × 14 × 12 mm geometric
finger proxies**. Cassette proxies approach the tab lips, enter 2 mm underneath,
and move with the cassette through the sampled lift path. These proxies do not
establish actual hand fit, comfort or a secure grasp.

[Slicing report](reports/slicing.json): all three changed plates pass fresh
local ElegooSlicer checks with the repository CC2 0.4 mm PLA profile, 0.2 mm
layers, four walls and 20% infill. No supports were used; all objects are on the
bed. The two unchanged board plates reuse exact input-hash-matched evidence.
The shell estimate is **343 g / 6 h 47 min**, each cassette **168 g / 3 h 8 min**.
These are estimates, not print results.

Six actual-mesh previews were inspected for complete framing, readable labels
and visible geometry. Cat/Fox names identify the teams beyond colour. The play
view conserves 21 flats and one capstone per player: six flats and the capstone
on the field, fifteen flats in each cassette. It is an illustrative arrangement.

Physical fit, comfort, rail/tab strength, board deflection, quiet storage and
transport retention remain unchecked in [ACCEPTANCE.md](ACCEPTANCE.md).

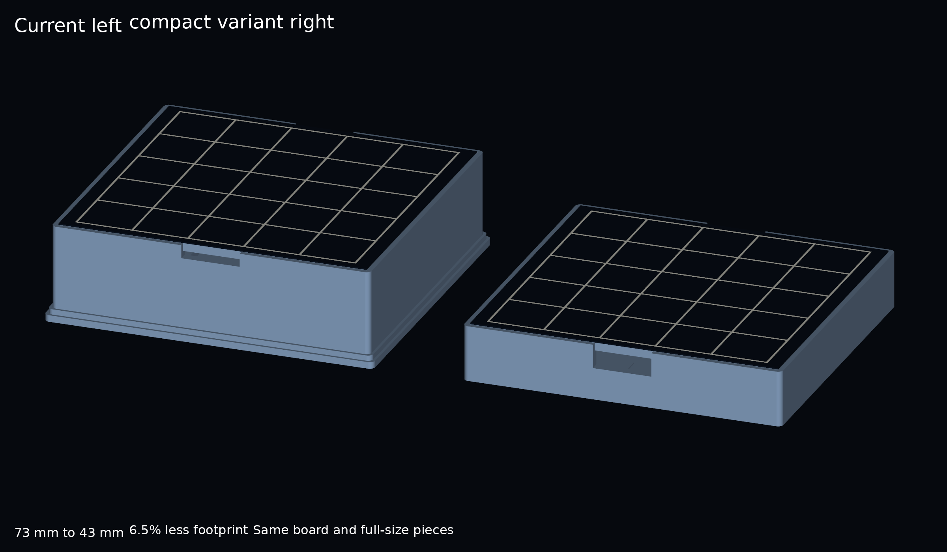
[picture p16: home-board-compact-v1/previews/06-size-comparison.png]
Current and compact size comparison


## Reproduction

Retain this package, `full-size-pagoda-v1`, its `pieces/` sources and the v16
mesh exporter. Use Python 3.12 and `source/requirements.txt` in the existing
project environment. No new runtime or local printer connection is needed.

```sh
python home-board-compact-v1/source/build.py
python home-board-compact-v1/source/render.py
python home-board-compact-v1/source/slice_check.py
```

The slice command requires installed macOS ElegooSlicer and never starts a
printer job. Source revision, dependencies, commands and source/input hashes
are retained in [provenance](reports/provenance.json). See the compact
[checkpoint](CHECKPOINT.md) for the next bounded trial.

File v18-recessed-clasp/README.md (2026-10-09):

# V18 — recessed press-and-slide clasp

**Unprinted mechanical test coupon. Not a finished case or proven purse-safe clasp. V17 is unchanged.**

The blue receiver stays on the case base. The teal keeper represents the lifting case half. The gold rigid bolt slides over the keeper's lower shelf. The thin gold spring only controls the bolt's motion; the keeper's opening load goes through rigid bolt/rail/receiver shoulders.

## Operation
1. To assemble the separate printed parts, leave the keeper out, depress the gold button, and insert the bolt from the open right-hand end of the receiver. The cage has an assembly tunnel between its end tabs. Move to the left/open position and release the button.
2. Lower the keeper into the right-hand registration cage. Press the button, slide right into the locked bay, and release. Gently pull the keeper upward to check engagement. **Closing also requires pressing**; this deliberately avoids an easy-camming front face that could let the bolt escape.
3. To open, first let the keeper rest down to unload the bolt; press the recessed button approximately 2 mm and maintain pressure while sliding left 10 mm. Release, then lift the keeper.
4. Pressing alone leaves the keeper blocked. Pulling/dragging the bolt alone encounters square shoulders. A narrow object that simultaneously presses and drags can still operate it; the guard reduces exposure but is not a lock.

The button is 1.7 mm below the guard in the nominal locked position. The retracted bolt is within the receiver outline, rather than sticking out during play. These statements describe this coupon; integrating the mechanism into a flat 5×5 case for the actual 44 pieces remains later work.

## What is included
- `plate/tak-v18-recessed-clasp.3mf`: three separate parts arranged on one plate, millimetres, no printer profile or G-code
- `parts/*.stl` and `*.step`: separate side-oriented parts; `*-assembled.*` preserve mating coordinates
- `parts/assembly.step`: complete locked nominal CAD assembly
- `states/`: four explicit assembled CAD states, including the assumed flexed leaf geometry
- `renders/`: full and sectioned views made directly from those CAD solids
- `build.py`, `package_plate.py`, `render.py`: reproducible sources
- `checks.json`, `review/`: calculated path checks and independent review

## Dimensions and assumptions
- Assembled coupon envelope: 78 × 40 × 10.1 mm
- Bolt-to-keeper overlap: 4 mm nominal; alignment play reduces this, so it is not a guaranteed minimum
- Intentional slide: 10 mm
- Leaf: 22 mm long × 12 mm wide × 1.6 mm thick
- Prescribed leaf-tip deflection: 1.8 mm; centre-button movement about 2.05 mm because of tip rotation
- Keeper-to-bolt gap: 0.4 mm; additional bolt-to-roof gap 0.4 mm gives approximately 0.8 mm vertical take-up before firm bearing
- Rail top and bottom gaps: 0.4 mm each
- The ideal small-deflection beam estimate at an assumed 2 GPa modulus is about 4.15 N and 0.89% root strain. These are **assumptions, not measured force, FEA, fatigue qualification, or a material allowables check**. Printed PLA is orientation-, brand-, temperature-, and process-dependent.

## Digital verification
- All three exported parts are single CAD solids; STL boundary/non-manifold edge check passes.
- PrusaSlicer 2.9.2 imports the three 3MF objects as manifold, one connected part each (`plate/slicer-import.txt`).
- Sampled press path (0–1.8 mm), held-down slide (0–10 mm), assembly insertion, and open keeper lift show zero unintended Boolean overlap.
- Locked bolt retraction and keeper lift encounter positive solid overlap after designed clearance is taken up. Press-only keeper lift remains blocked.
- The CAD deformation uses an assumed cubic cantilever curve. Boolean checks establish nominal geometric compatibility, not that real printed plastic follows that curve.
- Independent review tested additional bypasses and identified revisions, with residual issues in `review/`.
- The support-enabled dry slice completed without warnings. Selected actual toolpath layers were visually inspected (`slicing/layer-inspection.png`); model and support are distinct, and the deposition envelope fits a 200 × 200 mm bed. Support interfaces exist at the floating tabs/leaf. Removal access is available from the open receiver slot/ends and around the separate slider, but removal without surface damage is not physically verified. The complete assembly is not printed in place, so mating gaps are not deliberately filled with support. The final revision includes a floor beneath the keeper to stop downward escape before withdrawal.

## Printing: support-required trial, not a validated print profile
The 3MF uses a side orientation (90° about X) to keep the cantilever length in the layer plane. **Supports are required.** Receiver tabs begin as islands; the slider tooth wing and long leaf also need support in this orientation. Support-removal scars on bearing/leaf surfaces can ruin the intended clearance or initiate cracks. Do not assume this plate is support-free or ready to start printing.

Choose your actual printer and PLA profile, inspect every layer around the tooth and tabs, and arrange removable supports before printing. A 0.4 mm nozzle and 0.2 mm layers with at least four walls are a starting assumption, not calibration. Confirm the leaf is resolved as a continuous wall section, the support interface is accessible, and no island is unsupported. Do not scale the model to tune fit. A local analysis-only dry slice was performed, and its temporary machine code is excluded from the deliverables. No printer was started; no strength or physical fit test was performed. The generic estimate is 23.92 g total PLA (18.04 g model, 5.45 g supports, 0.44 g brim) and 2h 21m 17s. Actual printer results will differ.

## Small first-print experiment
Print only this coupon first. Remove supports carefully; inspect the leaf root and square shoulder corners for cracks/whitening. Do not force a jammed part. Verify assembly with the button pressed, then ten gentle close/open cycles. Check that a straight upward keeper pull stays held with the button untouched and with the button pressed but not slid. Verify a plain drag cannot slide the bolt past its detent. Check that a broad flat object over the guard does not press the button. Measure actual press effort, drag force, vertical play, and any support scars. Stop if it takes a tool, leaves whitening, cracks, sticks down, sheds the bolt, or releases without the two-part motion. A later cycle/loaded-bag test is still needed before relying on it for travel.

## Why this is different from the failed A buckle
A required two side beams to remain squeezed while travelling roughly 31 mm through tight guides, with only about 0.3 mm nominal vertical and final axial clearances and no generous entry funnel. Independent CAD probes found an ideal insertion path, so the actual print's failure cause is not proved. V18 instead separates rigid load-bearing rails from one visible, recessed press leaf and checks the complete commanded assembly/release path. That removes the specific long dual-side squeeze action; it does not guarantee the new print will fit.

No screws, purchases, or printer commands. No changes to earlier versions.

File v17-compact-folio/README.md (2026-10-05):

# Tak v17 — compact retained folio

**REJECTED DRAFT.** The user rejected having to unscrew storage to play.
Use [v17 tool-free](../v17-tool-free/README.md). This package is retained only
as design history; its print plates are not the current recommendation.

**Digital prototype. Not physically printed or accepted. Generic 3MFs are unsliced.**

The printed v16 did not retain its pieces, did not stay closed, and was too
large. v17 puts both teams in one shallow storage shell, closes that shell
with an independent roof, and clamps the roof and folded board with four M3
screws. There are no flexible transport latches. The 5×5 playing field stays
180 mm square at 36 mm pitch; the board is 3 mm thick instead of 2 mm.

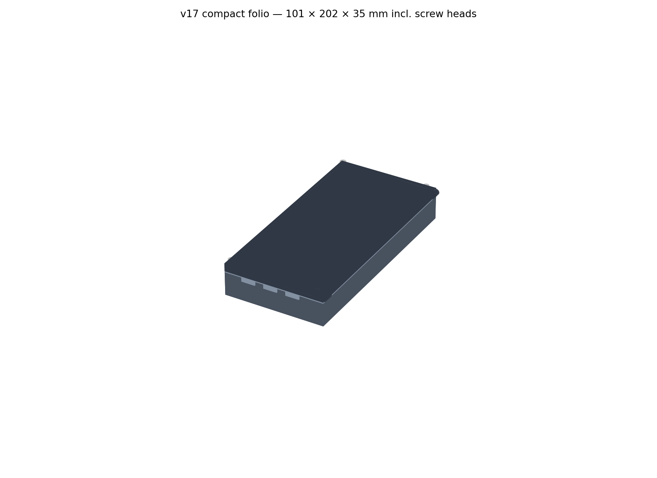
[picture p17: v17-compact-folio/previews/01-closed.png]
Closed exported geometry

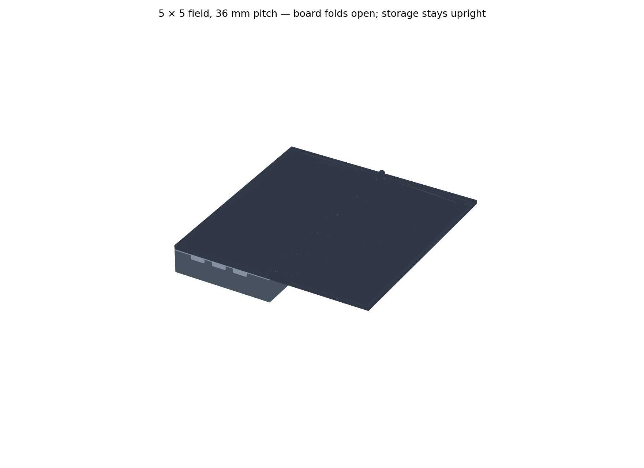
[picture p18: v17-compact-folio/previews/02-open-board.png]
Open exported geometry

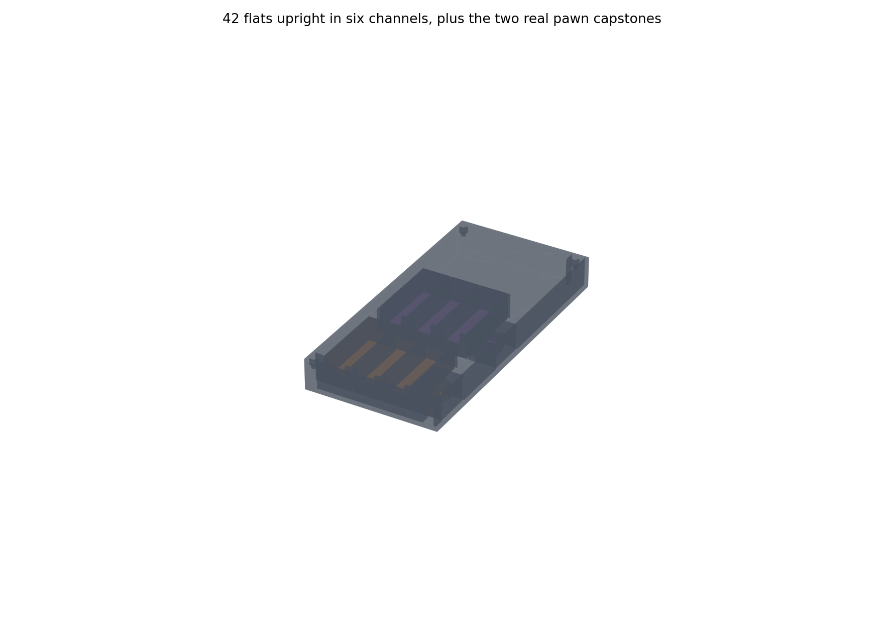
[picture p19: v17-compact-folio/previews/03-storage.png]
Loaded shell

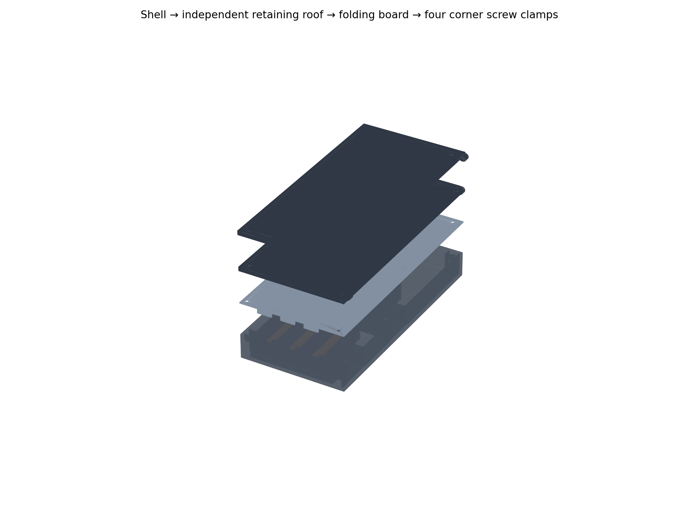
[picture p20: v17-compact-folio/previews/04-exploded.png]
Assembly


| Envelope | v16 | v17 |
|---|---|---|
| Closed, including screw heads | 101 × 202 × 51 mm | 101 × 202 × 35 mm |
| Closed volume | 1.041 litres | 0.714 litres (31.4% less) |
| Open playing field | 180 × 180 mm | 180 × 180 mm |
| Board plate thickness | 2 mm | 3 mm |

The footprint follows the usable board. Most of the size reduction comes
from replacing two tall storage cavities with one storage layer. This is a
new assembly; **v16 bases, trays, inserts and board plates are incompatible**.
They remain untouched in the original package. This revision uses the plain
black/white flush grid; the astronomical inlays remain in v16.

## Pieces and retention

- Two banks of three channels; seven upright flats per channel, 21 per team.
- Primary fit: the existing **19.5 × 19.5 × 8 mm printed flats**. Each channel
  is 20.2 mm wide and 56.7 mm long: 0.35 mm each side, 0.7 mm total along
  seven pieces. Conservative **20 × 20 × 8 mm** flat envelopes also pass;
  their 0.1 mm side clearance needs a physical trial.
- Two separate 20.2 × 26.2 mm capstone cells fit the real original
  `pieces/cat-capstone.step` and `pieces/witch-capstone.step`, on their sides.
  This revision does not establish fit for the curled Fox/Cat or pagoda set.
- The roof sits 1.5 mm above the existing flats and 1.6 mm above the pawns.
  Dividers leave only 2.5 mm beneath the roof, below a flat's 8 mm minimum
  dimension. Flats cannot pass over the dividers while the roof stays seated.
- A 14.2 mm finger scallop exposes the leading flat in each channel. Roof
  tongues fill those scallops during transport, with 0.4 mm side/end clearance.
  Remove the roof to expose them; slide the remaining flats forward as used.
- Four corner screws clamp all three layers (folded board, roof, shell).
  Opening requires deliberate screw removal. Unlike the failed buckle,
  release does not depend on printed spring force or a small catch overlap.

The new arrangement constrains loose movement but does not promise silence.
Rattle, grip, roof stiffness and closure durability remain physical tests.
The 20 × 20 × 6 mm weighted prototype **is not the accepted piece package**:
its shorter channel loading leaves 14.7 mm slack and needs matching spacers.
The existing v16 insert's 98 mm lanes still do not fit five weighted flats.
The 25 mm pagoda pieces do not fit v17.

## Hardware and opening

Buy **four M3×16 socket-head screws and four M3 DIN934 hex nuts**; use a
2.5 mm hex key. The envelope assumes screw heads no larger than Ø6 × 3 mm.
The top-loaded nut traps are 5.7 mm across flats, with a ledge at z=18 mm.
Nuts have axial room to rise against the retaining roof during tightening.
Thread engagement, nut rotation resistance and safe tightening force need
the coupon. Screws are loose parts: they are not captive or printed thumbscrews.

1. Keep the case flat, shell underneath. Remove all four screws and place
   them somewhere safe. Do not tilt the unlocked case.
2. Lift the still-folded board off and unfold it on the table. The independent
   roof remains on the shell, so unfolding never rotates a loaded piece bank.
3. Lift the retaining roof straight up. Take stones from the scalloped ends.
4. Repack seven flats upright per channel and one original pawn in each cell.
5. Seat the roof without pressure, then stack the folded board, align the four
   holes and install the screws. Tighten only until seated; do not bow the lid.

## Small prints first

`plates/00-fit-trials.3mf` holds a nut block and two 3 mm plates. Stack both
plates on the 8 mm block and use an M3×10 screw: the block's roof-to-nut-seat
distance matches the full shell. Test free screw passage and a nut that
cannot spin. This coupon does not reproduce the full shell's bending loads.

`plates/00b-lane-retention.3mf` contains a two-stone section and its roof
tongue. Load two existing flats, seat the roof and temporarily clamp it.
Check pinching the front stone, sliding the second, roof fit and whether
stones can escape through the scallop when inverted. This partial lane has
an open cut end; block it during the inversion check.

The reused print-in-place hinge dimensions are still an untested physical
interface in this thinner board. The original v16 hinge coupon is a useful
starting point, but the new board root and underside need a slicer preview.
Print a board end section if that preview suggests a bridge/support problem.
Complete [ACCEPTANCE.md](ACCEPTANCE.md) before a loaded transport test.

## Deliverables and reproduction

- `models/`: assembled-coordinate STEP, including the two storage coupons.
- `stl/`: single-part print poses. Roof prints flat top down, tongues upward.
- `plates/01-shell-and-roof.3mf`: separate shell and roof on one 256 mm bed.
- `plates/02-folding-board.3mf`: hinged pair and both white grids in their
  shared frame. Import as one multicolour assembly; assign board objects
  black and grids white. The body/grid STLs are normalized separately:
  **do not assemble their individual STL origins without re-registering**.
- `previews/`: generated from the exported STEP readback.
- `reports/verification.json`: checks, environment, source and output hashes.
- `logs/build.log`: successful final build output.

```sh
python -m venv .venv-v17
. .venv-v17/bin/activate
pip install -r v17-compact-folio/requirements.txt
python -u v17-compact-folio/source/build.py
```

Run from a complete repository checkout: both original capstone STEP files
are required. The isolated work environment already had these dependency
versions installed; no dependency downloads were needed for this build.

Suggested initial slicing: CC2, 0.4 mm nozzle, PLA, 0.2 mm layers, four walls,
20% infill. Shell and upside-down roof have flat print surfaces; inspect the
hinge/pin overhangs on the board plate and add local supports only if needed,
avoiding the print-in-place clearances. **No ElegooSlicer is installed here;
these are generic, unsliced 3MFs, with no machine profile or G-code.** No print
time, mass, support-free claim or printer job is supplied.

Digital checks cover solid validity, sampled 0–180° folding, assembled part
clearance, 42 flat envelopes and both real pawns, representative escape
translations, screw envelopes, manifold/oriented STL readback, bed fit and
3MF geometry/name/unit readback. The geometric barriers do not establish
roof strength, clamping force, drop survival or physical spill resistance.

## Build notes

Baseline: `88bc668a1752b2dbc1a2edfc967dcbb525b6f4d0` (main, October 3).
Issue #18's thin board/rattle observations and this session's spill, closure
and excessive-size observations supersede v16's blanket “not printed” text.
Exact printed revisions, individual component history and material are still
unknown. No physical acceptance box has been marked complete.

The initial rim intersected a hinge barrel; adding the missing hinge-end
relief corrected the fold sweep. An initial coupon plate used indices from
the full part list and put a coupon off-bed; filtered enumeration corrected
the plate. The final build regenerates all affected outputs and passes.

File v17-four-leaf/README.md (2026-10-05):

# Closure trial superseded

The four-part draw latch below was rejected as confusing. Use the new
[two-piece squeeze-latch trial](../v17-squeeze-latch), with one labeled plate
and an assembly diagram. It is not yet integrated into this case study.
The combined plate builder now uses the new two-part trial.

# v17 four-leaf common-hinge study

Selected architecture: two drawer housings and two board leaves rotate independently about one common hinge axis. Four interleaved knuckle families share the same steel axle at each end of the spine. The axle does not fasten the case closed. The board leaves snap onto their respective housings for play; covered sliding drawers allow access without disturbing the assembled board.

The 180 mm, 5×5 field and 36 mm pitch remain. Each drawer holds 21 original 19.5×19.5×8 mm flats in one layer. The taller original Cat/Witch capstones occupy a separate rear compartment, outside the field. This is a mechanism study, not a full-print release. The compartment hatch, drawer stops/releases, board snap fatigue and direct over-center closure still require fit-trial development.

Opening sequence: release the case draw latch; rotate the right housing and its snapped board leaf together until the board is flat; slide the team drawers forward while the case rests flat; the housing roofs uncover them as they emerge. For repacking, fully insert and latch both drawers before folding. A roof fixed to each housing encloses the stored flats throughout rotation. The independent board hinges allow maintenance and assembly without screws through the storage cavities.

The nominal main body is 101×236×32.6 mm closed, before closure hardware, with two short coaxial end axles. Keeping axle material out of the 180 mm field avoids a ridge through the middle playing column. Dimensions are preliminary; compare the final hardware envelope, not this body-only volume, with v16's 101×202×51 mm.

Original flat envelopes are the compatibility target. The rear compartment uses the original Cat/Witch pawn envelopes; curled Fox/Cat and weighted flats are not verified. This redesign does not reuse v16 printed interfaces. The rejected screw-clamped draft and pin/sleeve draft are not selected.

Run `python v17-four-leaf/source/build_study.py` from the repository root. STEP, STL, exported-geometry previews and a sampled paired-leaf fold check are generated. Read reports for actual results and limitations. No slicing, successful physical retention, snap force or latch durability is claimed.

## Direct mechanical closure trial

`python v17-four-leaf/source/build_closure_trial.py` builds a separate,
real hook/lever/keeper coupon. The hook captures a rectangular keeper;
a folding lever draws it down beyond dead center against a stop. There is
no removable closure pin. The 0.25 mm keeper-lift blocking check, released
hook clearance, solids, STL and named-object generic 3MF readback pass.
This proves nominal geometry only. The coupon is not yet integrated into
the case, and preload, actuation force and strength are untested.

Permanent pivots use M2.5 hardware through nominal Ø2.89 mm bores; confirm
printed clearance with a coupon. Nominal fasteners are M2.5×20 and M2.5×16
with washers/nyloc nuts, subject to measured stack-up. Once assembled,
normal opening requires only fingers. The steel hinge axles likewise remain
installed. The trial exports use generic geometry placements, not qualified
print orientations or sliced printer profiles. Do not print the full case.

## Combined plate files

Run `python v17-four-leaf/source/build_combined_plates.py`. The full study
parts need three 256×256 mm beds in flat layouts: plate 01 contains both
board leaves, the rear compartment and the two current squeeze-latch parts; plate 02
contains both drawer housings; plate 03 contains both drawers. Plate 04 is
an optional single-plate latch trial and duplicates plate 01's latch parts.
Steel axle reference solids are excluded because the hinges require steel
hardware. All objects are named; bed bounds, ≥4 mm separation and 3MF
geometry readback are checked. These are generic unsliced files, with no
supports/profile assigned. Packaging does not make the incomplete case a
print release. The six large part rectangles occupy 120,450 mm² compared
with a 65,536 mm² bed, before gaps; they cannot share one flat plate.

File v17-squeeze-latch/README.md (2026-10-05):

# Simple v17 squeeze latch — two-part hand trial

The prior four-part draw latch was rejected as confusing. This replacement
works like a backpack buckle: **push A into B until both side buttons click;
squeeze both buttons and pull apart to open.** There are two printed parts,
no separate hook, no pivot screws and no removable closure pin.

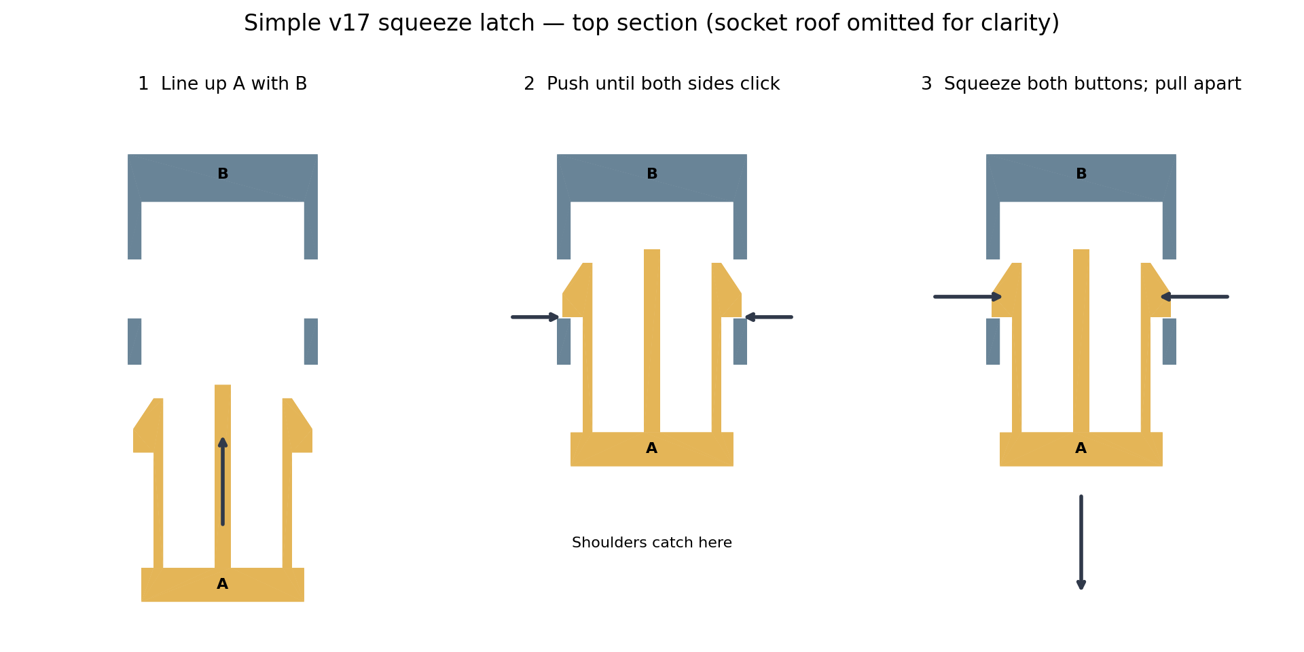
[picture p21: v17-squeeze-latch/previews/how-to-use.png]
Assembly and operation


Print `plates/v17-simple-squeeze-latch.3mf`, which contains both labeled parts
on one small plate. A is the flexible clip; B is its socket. The proposed
trial material is PETG, especially for A; PLA spring life is not established.
The file is generic and unsliced. Check the socket's 24 mm roof bridge in
your slicer before printing; supports inside the socket must be removable.
Do not change XY scale independently because it changes the fit.

Hold the small root labeled A and the larger closed end labeled B. Insert
the two tapered arms and middle guide into B's open mouth. Push until both
buttons appear in its side windows. Pull gently without squeezing to check
that the shoulders lock. Squeeze both window buttons toward the middle,
then withdraw A. Stop if insertion requires force; record which surfaces bind.

The broad square shoulders carry withdrawal load; the spring arms position
the shoulders. This is a small hand-held fit trial, **not an integrated case
closure**. The four-leaf common-hinge case architecture remains selected.
Case attachments and loaded-case tests follow only after the clip works
comfortably. This does not fit existing v16 latch interfaces.

Checks pass for single valid solids, STEP readback, closed/oriented STL,
locked clearance, blocking 0.5 mm withdrawal, compressed-arm clearance in
1 mm steps, central-guide clearance, plate spacing and named-object 3MF
readback. Moving arm envelopes inward does not simulate elastic bending:
insertion force, strain, fatigue and retention remain physical tests.
No slicing or successful print is claimed.

Reproduce from repository root:

```
python v17-squeeze-latch/source/build.py
python v17-squeeze-latch/source/diagram.py
```

Dependencies are pinned in `requirements.txt`. Run provenance and source
hashes are in `reports/checks.json`; physical acceptance is unchecked.

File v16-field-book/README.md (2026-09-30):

# Tak v16 — field book

**Prototype. Verified in CAD and sliced; nothing has been printed or physically tested.**

A tough little brick for a bag. The board folds in half with its face inside, and there's a snap-in piece tray under each half. It uses no screws, magnets or other hardware. Closed, it's two dark slabs meeting at a seam.

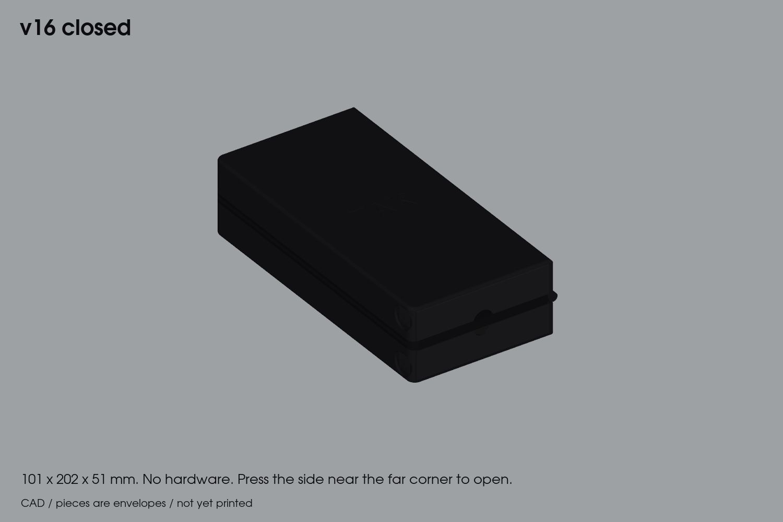
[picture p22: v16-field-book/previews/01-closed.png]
Closed

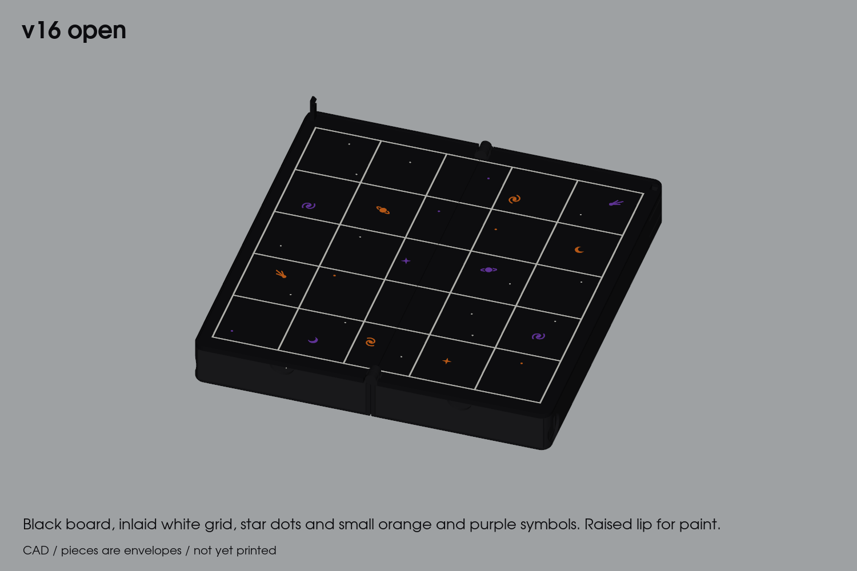
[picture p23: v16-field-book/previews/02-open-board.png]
Open

Trays out
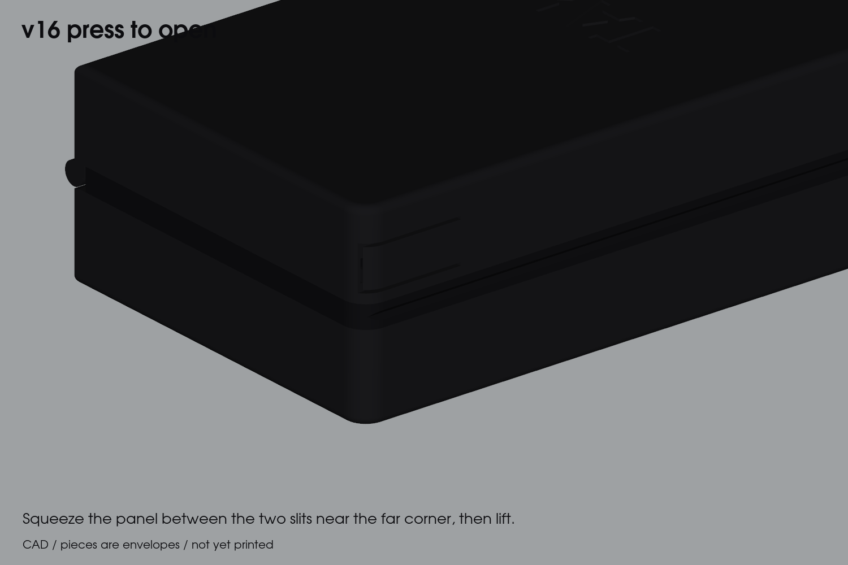
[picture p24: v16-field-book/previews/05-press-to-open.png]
Press to open


## Size

| | mm |
|---|---|
| Closed | 101 × 202 × 51 |
| Open | 196 × 202 × 38 (includes the closure tab) |
| Board | 5 × 5 at 36 mm pitch (180 mm field), for 20 mm flats: 16.0 mm between neighbouring stones |

## What changed from v15

v15 was too small to play on: with 8.5 mm between stones you couldn't get fingers around a stack once the board filled up.
- **Flush white grid.** The grid is now inlaid flush with the face, not raised 0.4 mm.
- **Bigger board.** The cells grew from 28 mm to **36 mm**, so neighbouring stones are **16.0 mm** apart (was 8.5 mm), enough for a fingertip on each side of a stack. `verify_book.py` now fails if that gap drops below 15 mm.
  - The book is 20 mm wider and 40 mm longer. The board art keeps its place in each cell; the symbols are the same size, so they look smaller on the bigger cells.
- **Capstone cradle.** The real pawn capstones (Ø19.4 mm, which can't get lower than 19.4 mm in any pose) did not fit v15's trays; the model used a stale envelope. Each tray floor now has a 0.4 mm cradle groove that holds the pawn on its side, and the trays are 1.4 mm taller. The closed book is 51 mm thick. `verify_book.py` now fits the real STEP pieces, not envelopes: the pawn sits 0.4 mm under the plate. The flats are the real 20 mm, not 19.5 mm.
- **Roomier trays.** The stacks stand at least 12 mm apart, so you can pinch one out. The trays are 132 mm long instead of full length, which leaves the back of each cavity empty and saves plastic.
- **Cross ribs:** two 1.2 mm ribs (y = 152 and 170 mm) span each chamber behind the tray, from the floor up to the plate seat. The plate rests on them, and they break the 92 mm floor and plate spans into bays about 20 mm long. They stay clear of the tray and of leaf B's buckle panel. The board plates did not change, so plates already printed still fit; only plate 01 (the bases) needs reprinting.
- **Glue wells:** one more along each wall to cover the longer walls. The pegs are unchanged.
- **Plates:** re-positioned for the bigger parts and the prime tower; all four still fit the 256 mm bed. Plate 01 is now about 4 h 58 min and 171 g, with the ribs.

## Carried over from v15

- **Closure:** a **buckle at the far edge**, opposite the hinge. No hardware.
  - **Closing:** a tab on leaf A's back corner pushes into a slot in leaf B and clicks under a catch.
  - **Opening:** the catch hangs on a spring panel cut into B's outer side wall, near the far corner. Squeeze that panel (about 4.5 N, 1.4 mm of travel) and lift.
  - **On the case:** the panel shows only as two fine slits on the side.
  - **Purse-proof:** pressing alone doesn't open it; the halves also have to be pulled apart.
  - **Print strength:** every flexing part bends within the print layers, not across them.
- **Shell:** a 2 mm floor skin, two cross ribs behind each tray, 6 mm plan corners, 2 mm bottom fillets, and a 10 mm back wall that houses the buckle.
- **Cover:** plain. The debossed TAK was cut: its 0.7 mm text caused print problems.
- **Board:** the grid is a 0.6 mm inlay flush with the face, in a second colour.
- **Fold:** the lips meet exactly at the hinge axis when closed.
- **Trays:** a push-button latch in each tray's outer wall. Push the tray in to snap it. To release, press the button 1.45 mm into a 16 mm finger dish in the book's side. The button sits 1.6 mm below the surface.
- **Pieces:** each tray holds 21 flats as 11 two-high stacks plus the pawn capstone.
- **Hinge:** print-in-place knuckles at both ends of the spine.

## Colours and art

Orange and purple are used sparingly, about 1 g of each per print plus purge.

- **Board:** black, with a **white grid inlaid flush** (0.6 mm deep).
- **Cells:** kept subtle. A sparse field of star dots (a few in orange and purple) and one small symbol per cell at most: two-arm galaxies, ringed planets, crescent moons, four-point sparkles and comets, split evenly between orange and purple.

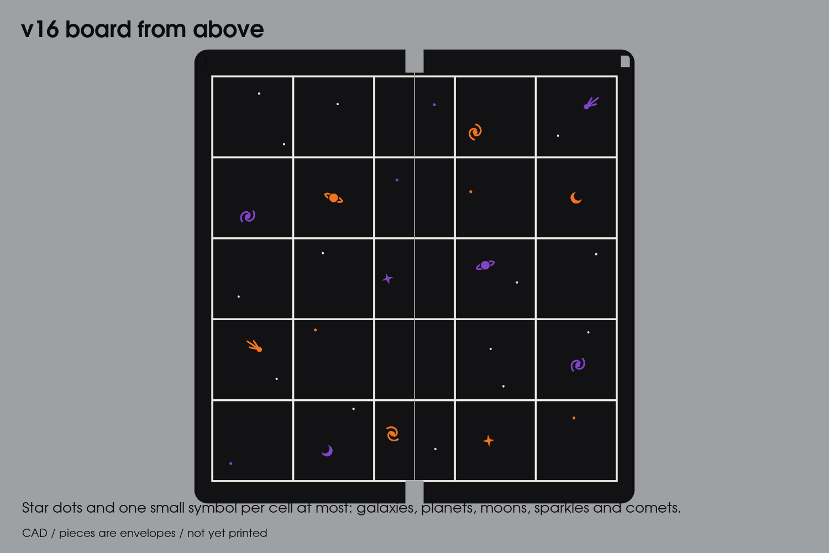
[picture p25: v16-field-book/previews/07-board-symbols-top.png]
Board symbols

- **Tray floors:** a crescent moon in the player colour (orange for the cat tray A, purple for the witch tray B) and a scatter of white four-point sparkles.
- **Tray fronts and case:** plain black.

All art is flush 0.6 mm inlay with strokes of at least 0.8 mm, so stones slide over it. It stays clear of the grid, fold seam, hinge notches, buckle, lip, thumb groove and tray latch. `verify_book.py` checks this.

Tray floors

## Protective lip (for paint)

Each board half has a **1.0 mm raised lip** on its three outer edges, 1.6 mm wide and not across the fold. The hinge axis sits at the top of the lip, so when the book closes the lips meet and nothing else does:
- **Painted faces:** 2.0 mm apart.
- **Grids:** 2.0 mm apart, flush with the faces.

Keep acrylic paint (and any varnish) below the lip top. The thumb groove is cut into the lip edge.

## Tray insert (add-on, printed after the trays)

The trays are already printed, so the insert is a separate part: a **pan** that drops onto each tray floor and lifts out with its flats. Nothing about the tray, bases or plates changed. It is built for how the flats are actually loaded: **lying flat in one layer, 4 across and 5 deep**, with the pawn and the 21st flat in the front strip.

- **One floor:** a 0.8 mm floor runs under the four lanes and the whole front strip beside the pawn, and every wall is fused to it or to a thick neighbour, so no feature hangs off by a thin wall.
- **Four lanes:** each is 20.0 mm wide and 98 mm long (5 flats plus 0.5 mm). The printed flats are 19.5 mm (0.5 mm under the real 20 mm for fit), so a flat has 0.25 mm each side. Drop a flat in anywhere along its lane and slide it up to the last one. The walls are 3.5 mm tall (under half a flat, so you can pinch one out) with a lead-in chamfer: 1.2 mm outside, 1.6 mm dividers, and the right wall runs the full length of the pan.
- **Pawn saddle:** the capstone stays in the tray's own cradle groove. A 1.6 mm, 9 mm tall stop wall sits behind it, with a 1.6 mm wall on the right and a 1.2 mm wall on the left, both 6 mm tall and 0.35 mm clear of its widest point. The left wall starts 17 mm back: the pressed latch arm swings out to 6.5 mm from the wall at the front and would hit it.
- **21st flat:** its own pocket beside the pawn, on the same floor, sharing the saddle's right wall.
- **Lifts out for play:** the back wall is 16 mm tall and full width, with a 28 mm finger slot (45 degree sides, so it prints without support). Slide the tray out, hook two fingers in the slot and lift: the insert comes out with all 21 flats and can sit beside the board as a play tray. The pawn stays in the tray's own groove (it has only about 0.1 mm of headroom under the plate, so it can't ride on a floor); take it out separately. To put away, drop the pan back in and the flats are already loaded.
- **Fit:** 0.15 mm off each tray wall, drops in with no force. The back wall tops out 3.4 mm under the board plate.
- **Two inserts:** A and B are mirror images (the pawn cradle is off-centre), so print one of each.
- **Print:** [plate 04](plates/plate04-tray-inserts-black.3mf), one slot-1 filament (any colour works; a light one shows the flats well), about 17 g each, no supports.

`verify_book.py` checks 21 flats of 19.5 x 19.5 x 8 mm (packed to the front and to the back of every lane) and the real pawn against the insert (`tray-insert-fits`). `FLAT` in `tak_book.py` stays 20.0 on purpose: the printed tray's cradle position is derived from it. The earlier tray notes above describe 11 two-high standing stacks; that is a capacity figure, not how it is loaded.

The [weighted stone prototype](../pieces/weighted-v1/README.md) uses 20 mm flats. Five need 100 mm before clearance, so they do not fit this insert's 98 mm lanes. This pan remains for the existing 19.5 mm printed flats; the weighted set needs a matching insert revision.

## Stiffer base (for the case print; trays and plates unchanged)

The board plates that were printed came out warped. Only the bases had not been printed yet, so the stiffening is all in the base and nothing about the trays, plates, pegs, glue wells or plate seat height changed. `stl/full` for every printed part is byte-identical to before.

- **Tray end bulkhead:** a 1.2 mm wall 1.6 mm behind the tray's end, from the fore wall to the seam wall and from the floor up to the plate seat. With the walls and floor it closes the box section behind the tray, so the two long walls can't spread or twist.
- **Spine rib:** a 1.2 mm rib down the middle of the chamber behind the tray, tying the bulkhead to the two cross ribs. The plate's bays behind the tray drop from about 92 mm wide to about 46 mm.
- **Clear of everything:** the tray still slides fully home with 1.6 mm to spare, leaf B's buckle panel keeps its 3.6 mm, and the new ribs sit clear of the plate's glue wells and peg sockets, so no glue can get under a rib. All are checked in `cross-ribs`.
- **Cost:** plate 01 grows from about 4 h 58 min and 171 g to 5 h 18 min and 178 g.
- **Not possible:** the tray channel itself (the first 132 mm). The tray sits 0.2 mm off the floor and 0.3 mm off each wall, so nothing can be added there, and the printed plates have no other seats to glue to.

## Print plates ([plates](plates))

Four ready-to-open 3MFs for the Elegoo Centauri Carbon 2 with its **4-colour filament system**, with G-code in [gcode](gcode). Every project uses the same filament slots:

| Slot | Colour |
|---|---|
| 1 | black |
| 2 | white |
| 3 | orange |
| 4 | purple |

Settings: PLA, 0.4 mm nozzle, 0.2 mm layers, 4 walls, 20% infill, **no supports**, textured PEI, 210 °C / 60 °C. The prime tower sits in the back-right corner.

| Plate | Contents | Colours | Time | PLA | Colour changes |
|---|---|---|---|---|---|
| [00](plates/plate00-fit-trials-black.3mf) | Fit trials: hinge pair, buckle (with a plate peg and socket), tray latch | black | 58 min | 21 g | 0 |
| [01](plates/plate01-hinged-bases-black.3mf) | Both bases, open flat, hinge printed in place | black | 5 h 18 min | 178 g | 0 |
| [02](plates/plate02-trays-4colour.3mf) | Trays A and B with moon and sparkle floors | black, white, orange, purple | 2 h 14 min | 62 g | 9 |
| [03](plates/plate03-board-plates-4colour.3mf) | Board plates A and B, face up, with lip, grid, stars and symbols | all four | 2 h 42 min | 97 g | 9 |

The full set (01–03) takes about 9 h 54 min and 330 g, including purge: 1.9 g orange and 1.8 g purple. Print **plate 00 first**. The times are slicer estimates.

**Assembly**
1. Free the print-in-place hinge on the bases.
2. Glue the board plates on (see **Gluing the board**

The lips meet exactly at the hinge axis, so any glue *under* a plate would hold the book open. Each plate therefore sits plastic-on-plastic on the wall tops, located by two pegs, and the glue goes in eight shallow wells in its underside.

Use **CA gel or 5-minute epoxy**. Don't use the original polyurethane Gorilla Glue: it foams and will lift the plate and glue the tray shut.

1. Lie the book open flat and take the trays out.
2. **Dry fit first.** Drop both plates onto their pegs. They should sit flat without forcing and not slide or rock. Close the book: the lips should meet flush and the tab should click.
3. Lift plate A off and put a thin bead of gel into each well, about half full. Keep glue off the pegs and out of the knuckle notches and the buckle slot.
4. Drop plate A back onto its pegs and weight it flat with a book or board across the whole plate.
5. Do plate B the same way.

Multi-colour parts are exported as one STL per colour ([stl/full](stl/full), `<part>.<colour>.stl`), all in the same frame, and `package_plates.py` reassembles them.

## Trial prints first ([stl/trials](stl/trials))

1. `trial-hinge-pair`: a spine end, printed in place.
2. `trial-buckle-tab-plate` with `trial-buckle-socket-base` + `trial-buckle-socket-plate`: check that the tab clicks in, can't be pulled out, and releases when you squeeze the panel. The socket pair also carries plate B's back peg and socket: the plate piece should drop on without forcing and not rock.
3. `trial-latch-base` + `trial-latch-tray`: the tray latch.

Then complete [ACCEPTANCE.md](ACCEPTANCE.md).

## Digital checks ([reports](reports))

`source/verify_book.py` passes all of these:
- **Fold sweep:** 0–180° is clear. Only the catch touches the tab, in the last 1° of closing.
- **Buckle:** it holds with 0.8 mm engagement when the halves are pulled apart. Squeezing the side panel frees the tab through a 12 mm lift.
- **Strain:** panel strain is 0.6%, and tray-arm strain is 0.75%.
- **Trays:** a locked tray can't be pulled out, and a released tray slides fully out.
- **Pieces:** they fit each tray and clear the pressed arm.
- **Cross ribs:** they clear the tray and the buckle panel, and they reach the plate seat.
- **Glue-up:** each plate sits clear on its pegs, and a 0.3 mm shift or a 0.3° twist is blocked. Every glue well sits over solid wall.
- **Bed:** every part fits a 256 mm bed.

`source/verify_meshes.py` confirms all 21 STLs are closed and correctly oriented.

## Known limits

- **Hinge barrels:** they still sit about 3 mm proud at the spine ends. Hiding them inside the outline would need a ridge across the middle of the board.
- **Buckle tab:** when open, the tab (2.4 × 4.4 × 10.8 mm) stands up at leaf A's far back corner.
- **Centre column:** the fold seam runs through its cells.
- **Squeeze force:** about 4.5 N, from beam theory. It's a guess until the trial is printed.

Rebuild with `python source/build_all.py` (needs ElegooSlicer for the last step). It runs `build_models.py`, `verify_book.py`, `verify_meshes.py`, `render_book.py` and `package_plates.py` in order, timestamps every line, writes a copy to `logs/build-<time>.log`, and stops at the first failure. Use `--from <step>` to resume or `--only <step>` for one step. The source is [tak_book.py](source/tak_book.py).

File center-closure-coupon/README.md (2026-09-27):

# Historical v5-only center correction

**Not compatible with the printed v7 wings. Use [the v7 replacement](../center-closure-v7/README.md), which has circular feet and the active PLA settings.**

The revised center fills the closed case above the existing wing bodies. Only the center's outer shell changes. This package targets the filament-pin board on `main` at `7bc9059`; it does not include the wing narrowing proposed in the separate PR #5.

## What changed

- The underside skin extends 3.6 mm below the original slab. The 4 mm gap above the folded wing bodies becomes 0.4 mm.
- Each end skirt grows from 2.0 to 2.1 mm thick and from 37.0 to 40.2 mm across. Its gap to the wing body becomes 0.4 mm.
- Circular relief follows the existing hinge axes at radius 2.9 mm: a 2.5 mm barrel plus 0.4 mm clearance. This is the circular interface in the repository model; the photo is not a calibrated dimension source.
- The bottom of the feet stays at Z = −20.1 mm, level with both wing floors.
- Wings, lids, playing face, hinge centers, knuckles, and 1.90 / 2.20 / 1.70 mm holes are unchanged.

## Coupon files and assembly

Print all five `coupon-*.stl` files separately, at 100% scale. They are already oriented on the bed: center and lid strips face down, wings bottom down. Use the established PETG board settings; supports should come from the build plate only and must not fill the pin bores.

The coupon is a 30 mm slice along the hinge axis at one end of the board, including both main hinges and 30 mm of each wing. Its five parts contain 36.7 cm³ of solid CAD volume in total. Actual material and time depend on slicing, infill and supports; this package is not pre-sliced.

1. Arrange the center between wing 0 (A) and wing 2 (B), with the playing faces in the same plane. Match the alternating knuckles rather than guessing from the print-bed layout.
2. Thread two pieces of 1.75 mm filament through the main hinges. Start with approximately 26 mm per pin and trim as needed; each pin must span both knuckles. No plugs are needed for this temporary fit check.
3. Seat each loose lid strip on its matching wing. The coupon ends before the outer lid hinges, so these strips are held by hand or removable tape during the check.
4. Fold both wings through 0–90°. Check for free movement and an even narrow gap above each folded wing and beside the end skirt. Use a 0.3–0.5 mm feeler gauge if available. Do not force a bind.
5. Check that the center foot and wing floors sit on the same flat surface when open. `coupon-closed.step` shows the intended folded arrangement.

The full center is `center-row-revised.stl` (or editable-solid `center-row-revised.step`). Print it only after the coupon fits. Reuse the existing full wings and lids. The old repository center STL and old plate 80 do not contain this correction.

## Verification

Verified with CadQuery 2.5.2 / OCP 7.7.2:

- Eight regression tests pass, covering the roof gap, both end skirts, circular relief, alternating knuckles, real bore sizes, filament paths, valid solids, resting plane and coupon construction.
- Both wings and lids clear the center through 0–90° in 5° samples; the added skirt stays at least 0.3 mm away. Both closed skirt-to-wing distances measure 0.4 mm.
- Existing full-board checks pass: main folds, opposing wings, lid motion and overlays, and all four filament paths.
- Before/after solid comparisons find zero changed volume in both wings, both lids, the playing slab and main hinge regions. The old center fails the new roof-fill and end-skirt tests.
- All six printable STLs have positive volume and two faces per mesh edge; each rests at Z = 0 in its print orientation.

See the measurement JSON files and test logs for receipts. The before/after image is a measured section through the CAD, not a photograph or a physical-fit claim. **The revised parts have not been printed or physically fitted.**

## Reproduce from the repository

Use a Python environment with CadQuery. The export has no slicer dependency.

```sh
python -m unittest -v test_center_leaf_fit
python export_pin_board.py --check-only
python export_center_closure_coupon.py --output-dir center-closure-coupon
```

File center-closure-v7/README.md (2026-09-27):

# Center for the printed v7 wings — PLA

Use **tak-center-v7-rounded-PLA.3mf**. It matches the v7 wing projects inspected in ElegooSlicer, including the extended end walls and their circular cutouts. The earlier v5 rectangular-skirt file catches in those wings and is superseded for this assembly.

The center has four R20.1 circular feet, 2.2 mm thick, seated in the unchanged wings' R20.5 notches. A 0.4 mm linear margin protects the inner end of each sector. The 3.6 mm underside skin is inset 2.9 mm at the ends so it clears the v7 wing walls. Hinge axes, knuckles and 1.90 / 2.20 / 1.70 mm holes remain unchanged. No replacement wings are needed.

The project copies the active ElegooSlicer configuration: Centauri Carbon 2, 0.4 mm nozzle, Elegoo PLA in slot 1, 210°C nozzle, 60°C textured PEI, 0.20 mm layers, 2 walls, 15% infill and build-plate-only tree supports enabled. The file was opened and sliced in ElegooSlicer; its estimate showed 35.87 g. No printer upload or physical fit was performed.

Four regression tests pass. They reproduce over 319 mm³ of interference per wing with the earlier rectangular skirts, then check the corrected center at every degree from 0–90° against both v7 wings and lids: zero overlap and at least 0.4 mm skirt clearance. Tests also check material near the outer circular edge, retained roof fill, unchanged hinge solids and clear filament paths. The actual wing 3MF vertex sets match the original v7 STLs; the corrected project mesh matches the checked center and is closed.

The five coupon STLs form a 30 mm end slice of this version. Their loose lid strips need holding or removable tape during the fold check. The STL center is face down, wings bottom down and lids face down. The 3MF contains only the complete replacement center.

Reproduce the CAD and coupon with CadQuery:

```sh
python -m unittest -v test_center_v7_fit
python export_center_closure_coupon.py --v7 --output-dir center-closure-v7
```

`tak_case_v7.py` brings in the current local v7 wing model that was absent from repository main, with the corrected center implementation. Wing geometry is unchanged. Regenerating STLs does not refresh the separately saved 3MF or copy current user filament settings; open the regenerated center STL in ElegooSlicer using the PLA profile above and save a new project.

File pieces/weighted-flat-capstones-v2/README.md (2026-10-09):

# Four-piece print block: midpoint capstones and Cat recess texture

The latest black-filament request has a [separate black regular PLA slice](BLACK/README.md), **36m 32s / 9.57 g**. Native UI control timed out; black regular PLA in slot 1 is user-confirmed, but live device verification and printer dispatch remain pending. The original silk delivery below is preserved.

Open [the ready-to-print 3MF plate](PRINT/Tak-FOUR-PIECE-SAMPLE-MIDPOINT-SLOT-3.3mf). It contains **one Cat capstone, one Witch capstone, one Cat regular flat and one Witch regular flat**, as **eight separate printable components**. Every component and support uses **Elegoo silk PLA in slot 3**. This is one sample plate, not complete teams and not a fused block. Unused slots 1/2 remain in the project only to preserve physical slot numbering.

The verified saved slice estimates **40m 26s / 9.57 g**, with Centauri Carbon 2, 0.4 mm nozzle, 0.2 mm layers, 220 °C nozzle, 55 °C Textured PEI bed, 40 mm/s outer walls and 6 mm³/s maximum flow. Build-plate-only support remains enabled under the upper capstones' face-down raised details. There is no prime tower or filament switching. No printer job was dispatched. The inherited bed/vitrification metadata warning remains; the confirmed material/process basis was preserved.

Four assembled sample pieces, rendered from actual exported geometry

[See the eight separate components on the print plate](previews/print-block.png).

## What changed

Both capstones now have **two nominally 4 mm deep external halves meeting at Z4 mm**. A symmetric **0.05 mm epoxy bond gap** keeps the finished height at 8 mm. The lower half's hidden aligning lip extends 1.375 mm above its external seam into the upper half's recess. Two upright flex tabs have **2.8 mm wide retaining shoulders**, **0.35 mm radial capture** and a **0.4 mm thick plateau**. Guard walls separate loose fill from the fingers' deflection spaces. The internal lip is an overlap feature, so the lower printable component is taller than its 4 mm external share.

V2 capstones require both new matching cups. Existing V1 regular floors remain geometrically reusable. External silhouettes are unchanged from the V1 sample. Capstones remain within **26 × 20 × 8 mm** and regular flats remain **20 × 20 × 8 mm** for the user's printed V26 case. Both capstones have **1.165934 mL closed void before adhesive** and **0.860346 mL usable fill**. Usable capacity reserves the internal overlap, protected snap spaces, at least 0.25 mm headroom and another 0.03 mL glue allowance. It is lower than V1's 0.988819 mL usable capacity; the two teams still match. Equal volume does not establish equal finished weight.

The regular-flat body/flat-floor snap and epoxy architecture is retained. Both regular floors are geometrically identical to V1. The Witch regular finish is unchanged. Cat regular sides have **0.3 mm deep recessed diamond pockets**, 1.4 mm wide/high, spaced 2.4 mm apart in three staggered rows on all four sides. No material is added beyond the original envelope; the closure region and broad stacking faces retain their original surfaces.

Separate capstone cups showing hidden joint geometry

Sections through the actual exported retaining tabs

## Assembly and physical evidence

The user reports that regular snaps work in their test. They printed only the **V1 Cat capstone**, which either seats without a click or clicks then separates. **Witch capstone retention is untested.** That component-specific report supersedes any implication that V1's straight-pull CAD checks established retention. This V2 joint is a replacement architecture, not another thin-floor tuning. Its physical retention remains unverified.

Before filling, check the empty parts in the actual V26 guides and check lip alignment without fully engaging the barbs. The snap is intended for one-time assembly; a fully snapped empty pair may become a consumed fit trial. Fill the lower cup, keeping grains out of the guarded mechanism. Leave the surface **at least 0.41 mm below the Cat lip rim** or **0.69 mm below the Witch lip rim**. Regular-flat fill remains 0.90 mL with a surface 1.90 mm below the open rim.

Apply epoxy to the continuous mating perimeter/lip, keep the flex slots free, and seat both hooks. Hold the halves at their intended seam while the epoxy cures. Epoxy provides bonding and sealing; the hooks back it up. Sand and varnish the outside after assembly, then check finished case fit and tactile contrast. Dry retention, steel-shot fit, leakage, stacking, handling and the finished texture remain physical gates. Shot diameter and its packing density are unknown; the user's planned arrival on October 9 does not qualify those properties.

## Evidence and reproduction

- [Geometry](reports/geometry.json): valid single solids; zero assembled overlap; all hidden joint features contained inside the unchanged silhouette; deflected-hook and guard clearance; positive straight-pull interference; equal closed/usable capstone volumes; STEP round trips; eight watertight single-body STL meshes; unchanged regular floors and stacking/closure regions.
- [V26 fit](reports/v26-fit.json): **115 checks** against unchanged exported V26 housings and covers, every storage position and sampled slide/fold motion. Exact revision/tolerances of the physical case are unknown.
- [Saved plate readback](reports/slicing.json): eight independent named components, source-surface agreement within 0.002 mm, all assigned slot 3, correct profiles/supports, bed containment and G-code **T2 only**. T2 is the zero-based feed-slot command.
- [Sliced snap checks](reports/snap-slice.json): **32 probes** of actual G-code bead paths/widths. All sampled rear/side/guard spaces remain free and both retaining plateaux carry plastic at Z4.4 and Z4.6. Minimum sampled probe-to-bead-edge distance is 0.1745 mm. The verifier includes the retained CC2 physical-nozzle XY offset of 0 × 1.5 mm. These are predicted bead envelopes, not measured physical beads or retention force.

Use Python 3.12 with [the pinned requirements](requirements.txt), from the repository root:

```sh
python pieces/weighted-flat-capstones-v2/source/build.py
python pieces/weighted-flat-capstones-v2/source/verify_case.py
python pieces/weighted-flat-capstones-v2/source/plate.py
python pieces/weighted-flat-capstones-v2/source/verify_plate.py
python pieces/weighted-flat-capstones-v2/source/verify_snap_slice.py
python pieces/weighted-flat-capstones-v2/source/render.py
python pieces/weighted-flat-capstones-v2/source/render_plate.py
```

The package depends on the preserved V1 source/vendor generator and silhouettes, V26 STEP references, `pieces/tak_pieces.py` and the V16 mesh exporter. Profiles travel with V2. The plate builder uses the installed macOS ElegooSlicer path and an isolated data directory. [Verification provenance](reports/verification.json) records source/profile/output hashes, commands, dependency versions, failures and remaining physical gates. V1 source, sample plate and printed parts remain unchanged.

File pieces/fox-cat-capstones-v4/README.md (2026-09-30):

# Cat neck correction v4, with unchanged Fox v3

The Cat's broad outlined neck/shoulder strip has been reshaped into continuous shoulder volume on both sides. This goes beyond the rejected v3 ridge smoothing. The facial jaw remains readable; a final bounded cleanup treats the small facets under the chin. The turned pose, eyes, muzzle, ears, torso curl, slender tail and planar base are retained. This is a local mesh correction, not a new generation.

Review `previews/cat-three-quarter-before-after.png` and `cat-front-before-after.png`, plus individual front/left/right/back/three-quarter renders. The original sculpture crop is `references/cat-hero.png`. All model images depict actual exported geometry with identical before/after cameras.

Fox is byte-identical to the delivered v3 Fox. Previous packages remain intact. No new Meshy credits, public release or printer job were used. Prior approved Meshy generation spend is 80 credits across v1/v2.

## Delivery

- `models/cat-capstone.stl`: revised upright Cat in millimeters.
- `models/fox-capstone.stl`: unchanged v3 Fox.
- `models/fox-cat-capstones.3mf`: two separately labeled millimeter objects.
- `models/cat-cc2-proof.3mf`: Cat slicer proof with CC2/0.4 mm PLA, 0.12 mm layers, four walls, 25% infill and tree supports. The Fox proof is copied unchanged.
- Storage-pose diagnostic STLs are generated locally by the fit verifier; they are not tracked print deliverables.

## Current evidence

| Cat check | Result |
| --- | --- |
| Dimensions X × Y × Z | 15.518934 × 17.809479 × 24.084475 mm |
| Exported surface | One watertight, consistently wound positive volume; 119,544 triangles |
| Planar base | 152.084158 mm² |
| COM inside base hull | 5.181051 mm margin |
| Current v16 tray, insert, latch, plate and base | No digital overlaps |
| Mirrored slots, closed box, sampled withdrawal and lift | Pass |
| Enclosing cylinder for all axial rolls | No overlaps; 0.800001 mm headroom |
| Local dry slicing | Pass: 200 layers, 39m 5s, estimated 2.71 g |
| Combined 3MF readback | Labels, units, dimensions and volumes match final STLs |
| Protected exported Cat regions | Within 0.000002 mm serialization tolerance |
| Fox | Byte-identical to v3; its existing verification/slicing evidence reused |

`reports/neck-revision.json` records the deformation and final under-jaw cleanup. `reports/protected-geometry.json` checks retained upper head/ears, far cheek, muzzle, base and tail against the retained original Cat. The subdivision preserves original surface planes exactly before deformation. Maximum local movement is 1.887106 mm; the final jaw-junction cleanup is bounded at 0.35 mm. Overall dimensions remain unchanged.

`reports/verification.json` contains refreshed Cat geometry, fit and motion results plus explicitly reused Fox results. V16 source hashes match. `reports/slicing.json` contains final Cat results and marked Fox reuse. Original v3 reports are retained for that provenance. `reports/package-readback.json` verifies the final combined 3MF.

Visual assessment is based on current actual renders compared with the supplied sculpture, including both sides and the underside transition. Creator acceptance remains pending. Physical fit, tactile identification, grasp, removal, support cleanup, retention and durability remain untested; digital checks do not establish those outcomes.

## Reproduction

Use Python with `source/requirements.txt`, from this repository. Run `python pieces/fox-cat-capstones-v4/source/rebuild.py` to recreate the complete final pair from retained Meshy OBJs. It writes ignored `.build-work/models`, compares both regenerated STLs to the delivery and records `reports/rebuild.json`. The recorded run reproduced both final STLs byte-for-byte with zero paid calls. No earlier untracked revision package is required.

The pipeline finishes the two Meshy v2 sources, applies Fox's v3 tail revision, reconstructs the historical Cat v3 intermediate and applies the final Cat v4 correction. `raw/cat-v3.stl` is retained only for before/after and protected-feature checks; it is not a printable final Cat. `reports/meshy-v2-*` and `v3-*` are labeled historical provenance. The original source sheets, exact image crops and generation task/settings records are retained. Rejected v1 generations and the Fox ribbon patch are excluded.

For rebuilt export readback, run `python pieces/fox-cat-capstones-v4/source/check_package.py --root pieces/fox-cat-capstones-v4/.build-work`. Generate its actual views with `python pieces/fox-cat-capstones-v4/source/render.py --root pieces/fox-cat-capstones-v4/.build-work`. Both are verified in this package's rebuild record and PR checkpoint.

For new geometry changes, run `source/verify.py --species cat`, `source/slice.py --species cat`, `source/check_protected.py` and `source/check_package.py` for affected checks. The verification/slicing CLI outputs contain only newly checked Cat evidence; the delivered reports additionally include explicitly marked Fox v3 evidence reuse. The full verifier defaults to both species when both change.

Use `source/render.py --species cat`, `source/render_revision.py` and `source/render_sheet.py` for delivery previews. Fit scripts import repository `v16-field-book/source/tak_book.py`; its exact checked source is retained in `references/v16-source`. Slicing uses repository `pieces/profiles` and installed ElegooSlicer on macOS. Preview rendering uses VTK and macOS Arial. `source/build.py` supplies source finishing and the 3MF helper; run `rebuild.py` for the complete final pipeline.

## Physical pair test, still pending

Print one upright Fox and Cat pair with the proof settings before a batch. Remove supports and inspect the ears, jaw and tail tip for damage. Check that each flat base rests without rocking and that the piece stays upright during normal board handling.

Test each capstone in both actual v16 trays with the insert installed. Close and release the latch, fold the case, then slide each tray fully out. Grasp the body/tail to remove the capstone and check for rubbing or catches. Confirm tactile distinction between the Cat's rounded tail and Fox's carved fur, and comfortable grasp/release.

Repeat insertion and removal ten times, inspect for scuffs or chips, then check retention during ordinary closed-case carrying. Record the exact print/profile and observed fit, release, retention and wear before calling the physical pair accepted.

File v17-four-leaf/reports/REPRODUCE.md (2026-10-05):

# Evidence scope

Command: `python v17-four-leaf/source/build_study.py` from repository root.
Dependencies are pinned in `requirements.txt`; Python/CadQuery versions and
source SHA256 hashes are recorded in `study.json`. See `build.log` for the
actual run, including harmless read-only home/cache warnings.

The first support layout failed independent board rotation. The revised
support columns and separate end straps pass the recorded sampled checks.
Motion samples are every 10 degrees, not a continuous swept-volume proof.
Original flats are 19.5×19.5×8 mm envelopes; capstones are conservative
25.4×19.4×19.4 mm envelopes. No curled or weighted set compatibility claim.

Previews use read-back STEP geometry. Triangle subdivision improves depth
sorting of the large board faces; these are technical geometry views.
STLs are study exports, not print-ready parts. The separate draw-latch coupon includes generic 3MF objects and readback
checks; these are not a complete case release or qualified print orientations.
No ElegooSlicer is installed. Physical acceptance remains unchecked.

Closure command: `python v17-four-leaf/source/build_closure_trial.py`.
See `closure-trial.json` and `closure-build.log`. Its static checks do not
validate the full actuation path, preload, friction or integration with leaves.

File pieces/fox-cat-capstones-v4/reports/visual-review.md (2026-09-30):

# Visual claim ledger

| Claim | Evidence | Verdict | Remaining gap |
| --- | --- | --- | --- |
| Broad collar-like shoulder strip replaced | Current front, three-quarter, left and right actual STL renders, compared with retained Cat reference and v3 before/after | Local visual review passes | Creator acceptance pending |
| Jaw junction cleaner after final refinement | Final front and three-quarter renders after bounded 0.35 mm cleanup | Small jagged transition reduced to a smoother neck plane; jaw outline retained | Creator's interpretation may differ |
| Facial detail/base/tail preserved | Render review and protected-region exported geometry distance checks | Pass within STL serialization tolerance | Tactile identity untested |
| Printable geometry and digital compatibility | Final Cat verification and dry slicing reports | Pass | Physical fit and support removal untested |
| Fox unchanged | SHA-256 equality to v3, 3MF readback matching current STL | Pass; prior Fox checks reused | Prior physical acceptance still untested |

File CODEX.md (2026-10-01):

# Working on Tak with Codex

Repository: https://github.com/Arcadesys/tak-box
Research: https://chatgpt.com/space/page_1a04af571ecc8191817d9c547cde56ff
Space hub: https://chatgpt.com/space/page_6abdc060969481918381b94ad91155e8

## Session entry

Select Arcadesys/tak-box in a Codex checkout/environment. Read AGENTS.md and docs/TAK_PROJECT_BRIEF.md. Start from the current main branch and create a focused working branch before geometry edits.

The connected GitHub app can read and write this private repo. A repository link in a Page does not mount a checkout or configure a Codex cloud environment. This setup adds durable instructions and source links; it does not attest to a configured cloud runtime.

## Runtime

This is a Python/CadQuery CAD project. Use package-specific dependency files:
- Weighted stones: pieces/weighted-v1/requirements.txt
- Fox/Cat: pieces/fox-cat-capstones-v4/source/requirements.txt

Follow their README environment commands. For v16, inspect imports in v16-field-book/source and install its requirements in an isolated environment; no v16-field-book/requirements.txt was present during this setup. Do not assume OpenSCAD is the build system. ElegooSlicer is needed for slicing/packaging; some render scripts depend on VTK and macOS fonts/paths.

Existing v16 commands:
```sh
python v16-field-book/source/build_all.py --only verify_book
python v16-field-book/source/build_all.py --only verify_meshes
python v16-field-book/source/build_all.py
```

These are existing source entry points, not newly validated execution results. Run build_models first when generated geometry is missing or changed. Read reports and distinguish source checks from stale retained artifacts.

## First useful task

Read issue #18, reconcile which v16 parts have actually been printed, and propose the smallest stiffness/retention trial that preserves the current assembly. For the luxury direction, first produce a separate spill-free motion study; confirm hinge axes, lid order and how the pieces stay supported before detailed geometry.

## Suggested Page prompt

Work in Arcadesys/tak-box. Read AGENTS.md, CODEX.md, docs/TAK_PROJECT_BRIEF.md, the v16 README and issue #18. Summarize the current printed-part status and propose the next small verification or fit trial. Keep the luxury hinged-well design separate from the v16 baseline. For any requested implementation, use a focused branch and PR and report checks actually run.

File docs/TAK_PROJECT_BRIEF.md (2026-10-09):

# Tak project brief

Updated October 8, 2026. This brief combines the current repository with Austen's recent Tak design conversations. Source files and measured print reports take precedence over concept imagery or older conversation summaries.

### Weighted sample for the printed V26 case — October 8

The user now requests the same four-piece sample in black and explicitly authorizes its printer dispatch. A [separate black regular PLA slice](../pieces/weighted-flat-capstones-v2/BLACK/README.md) passes eight-object readback and 32 snap-path probes, estimating **36m 32s / 9.57 g**. Stored generic PLA settings are 210/60 °C, slot 1. The user confirms black regular PLA in physical slot 1. Native ElegooSlicer and Finder control timed out; printer-ready state and UI load are unverified. No printer job was submitted. Silk delivery and geometry remain preserved.

**Current physical feedback and selected replacement:** the user printed only the V1 Cat capstone. Regular-flat snaps work in their test; the Cat capstone either seats without clicking or clicks then separates. Witch capstone retention remains untested. V1 digital straight-pull checks did not establish physical retention. Both capstones now use equal-depth external halves meeting at the midpoint, with a hidden aligning lip/recess, positive retaining snaps and an epoxy bond/seal. Outer silhouettes, 8 mm finished height and V26 case geometry are preserved. Cat regular sides get recessed reverse-diamond pockets; their broad stacking faces and the working regular closure stay unchanged. Witch regular finish is retained. Sanding/varnishing happens after assembly and finished tactile contrast/case fit remain physical checks.

The requested delivery is **four assembled sample pieces only**, as one print block containing **eight separate printable components**, all assigned Elegoo silk PLA **slot 3**. No team batches, fused block or printer dispatch. The [V2 midpoint sample](../pieces/weighted-flat-capstones-v2/README.md) has matched 0.860346 mL usable capstone fill after overlap/headroom/glue allowances and 1.165934 mL closed void before adhesive. Saved estimate: 40m 26s / 9.57 g. CAD/mesh/STEP checks, 115 affected V26 fit/slide/fold checks, named 3MF readback and 32 actual sliced-tab path probes pass. New dry retention, shot fit, leakage, stacking and finished texture remain unverified. The user expects steel shot on October 9. The prior sample below is retained as history.

The user reports V26 already printed. Fit in that existing case takes priority over increasing piece height, and they permit redesigning the Witch hat. The new [weighted flat/capstone sample](../pieces/weighted-flat-capstones-v1/README.md) keeps regulars at 20 × 20 × 8 mm and capstones within 26 × 20 × 8 mm. A broader Witch hat matches the Cat's 0.988819 mL usable ballast space and 1.094064 mL complete closed void, with a thicker 1.538 mm roof. Two opposing snap hooks capture each floor behind retaining lips as a mechanical backup to the epoxy seal. The eight-part plate uses the user's Elegoo silk PLA on slots 3/4 and estimates 2h 7m 34s / 26.87 g.

This exact piece package passes solid/mesh/STEP checks, 115 checks against V26's unchanged housings, cover travel and sampled folding, and named saved-3MF readback. The project was visibly loaded in ElegooSlicer; a subsequent native slice request timed out, so the saved CLI slice is the confirmed slice. The inherited vitrification metadata warning remains documented. No printer job was dispatched. The exact physical case revision, new-piece fit, snap strength and sand seal still require the sample trial. Existing V26 plates and older weighted packages are preserved.

### Current V26 captive main hinge — October 7

The user confirms a printed axle permanently fixed between two supports on one half, trapping the opposite half’s moving barrel. V26 now uses this arrangement at both main-hinge stations: 4 mm axles, 2.5 mm fixed supports, 3.2 mm moving barrels, 9 mm outer barrels, full-height 8 mm roots and nominal 0.4 mm radial/face gaps. The rounded revision passes 947 integrated CAD checks, 51 exported audits and 37 sliced hinge/hook checks; sliced main support-face gaps are at least 0.32 mm under the conservative bead-width check. The prior opposing peg/socket full kit is preserved under v26/archive/previous-main-hinge. The modest outside rounding changes the boards’ body margins; inlay geometry remains intact. The current board plates are rebuilt and sliced again. Current complete estimate is 17h 46m / 288.66 g including optional capstones; physical strength remains untested.

The user also requests modest corner rounding while this revision is underway. Use 4 mm outside case corners and 2 mm outside sliding-board corners, preserving the complete field, inlays, guides and hinge supports.

The user reports that pressing a sliding-board tab while pulling was awkward. They approve using the case hook to secure both covers during closed transport and explicitly choose to build full plates before small physical trials. [V26](../v26/START-HERE.md) now removes the flexible catches and restores solid bevelled board margins. A rigid 4 × 6.1 × 4.7 mm seating shoulder outside each playing field meets the front rail to stop inward travel; it moves away freely on outward withdrawal. Open the case hook, then pull either board without pressing a tab.

The kit retains the PIP main hinges, permanent piece guides, 3.4 mm floors, 180 mm / 36 mm-cell field, original independent accent inlays and 102.5 × 200 × 35 mm closed envelope. The captive hook has a 4 mm fixed axle, 2 mm outer cheek, 3.4 mm frame bridge, 0.4 mm radial/face gaps and parked printing foot. No filament hook pivot, loose collar or removable tray. Three full sliced projects are under V26/FULL-PRINT: joined bodies/hook, full-size four-colour boards and optional original flat capstones. Actual silk spool profiles still require matching and reslicing.
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

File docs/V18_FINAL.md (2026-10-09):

# V18 historical version

The user advanced the current build to [v19](../v19/START-HERE.md) on October 5. This page records the retained v18 history.

The user selected **v18 as FINAL** on October 4. On October 5 they explicitly chose a **simple side hook and pin** in place of the recessed press-and-slide latch, and **1.75 mm PLA filament pins**. This is the authorized v18 direction. Preserve the four-leaf common axis, full field
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

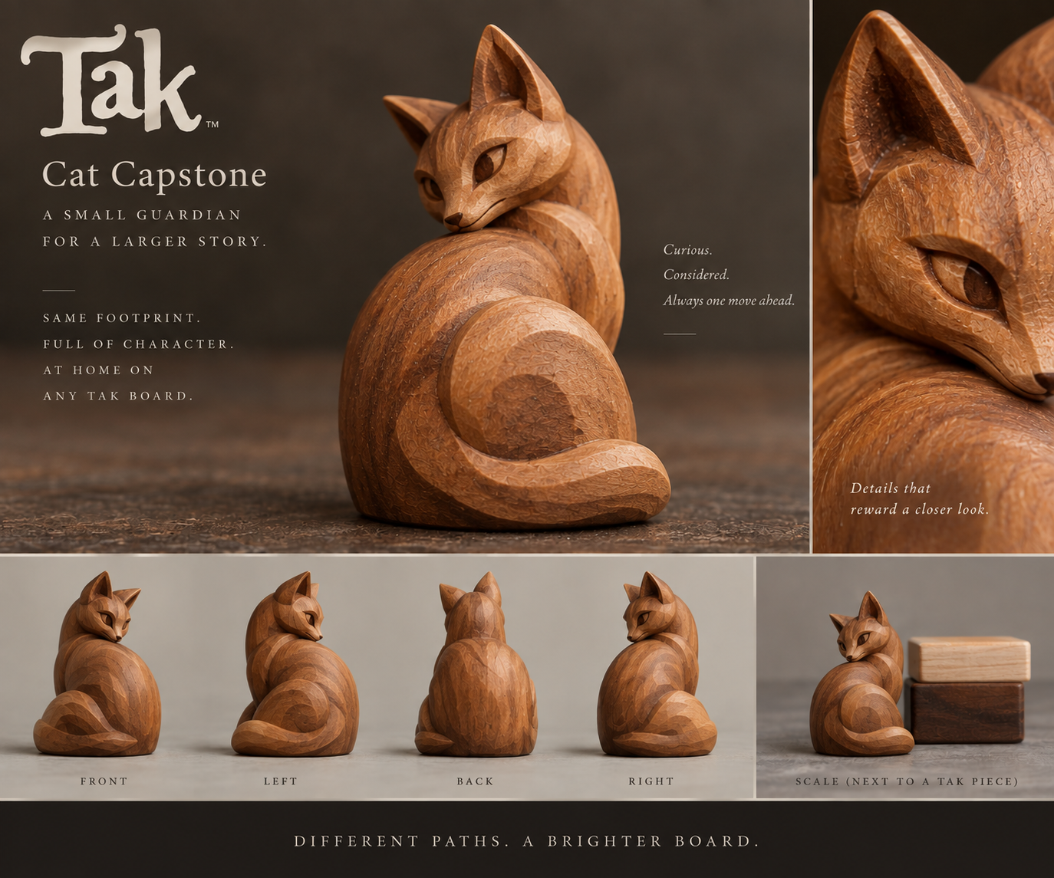
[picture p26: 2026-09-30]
pieces/fox-cat-capstones-v4/references/cat-design-sheet.png

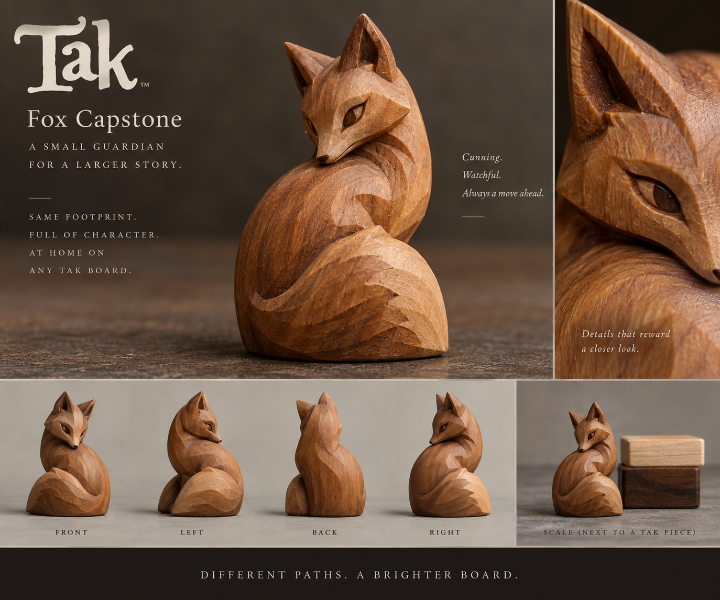
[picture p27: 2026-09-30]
pieces/fox-cat-capstones-v4/references/fox-design-sheet.png

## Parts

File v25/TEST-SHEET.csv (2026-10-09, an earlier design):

trial | filament | layer_mm | measured_pin_d_mm | cycles | binding_or_release | rock_or_permanent_set | pull_force_N | sideways_escape | filament_migration_or_bond_failure | whitening_or_cracks | notes
H1 |  | 0.20 |  | 0
H1 |  | 0.20 |  | 20
H1 |  | 0.20 |  | 100
H2 |  | 0.20 |  | 0
H2 |  | 0.20 |  | 20
H2 |  | 0.20 |  | 100
H3 |  | 0.20 |  | 0
H3 |  | 0.20 |  | 20
H3 |  | 0.20 |  | 100
L1 |  | 0.20 |  | 0
L1 |  | 0.20 |  | 20
L1 |  | 0.20 |  | 100
L2 |  | 0.20 |  | 0
L2 |  | 0.20 |  | 20
L2 |  | 0.20 |  | 100
L3 |  | 0.20 |  | 0
L3 |  | 0.20 |  | 20
L3 |  | 0.20 |  | 100

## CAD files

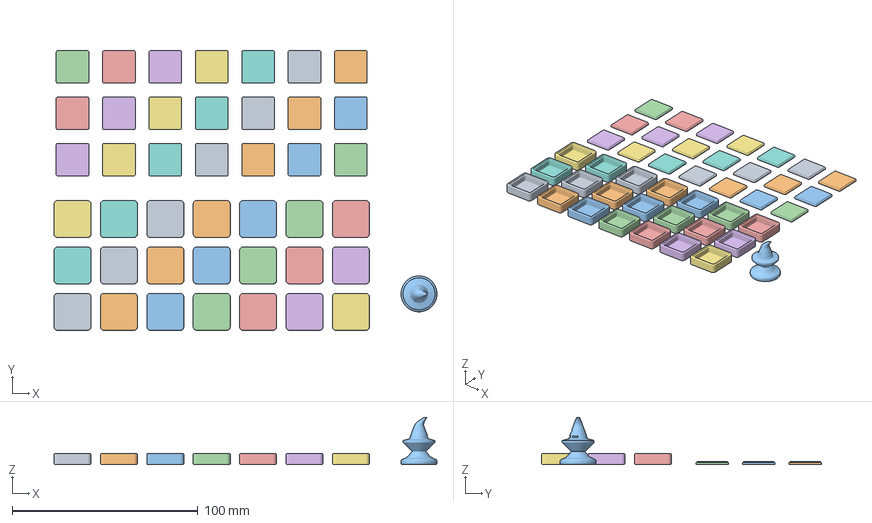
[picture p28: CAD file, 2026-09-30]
pieces/weighted-v1/plates/witch-complete-set.3mf
206.4 x 150.8 x 25.4 mm
01-witch-body
02-witch-body
03-witch-body
04-witch-body
05-witch-body
06-witch-body
07-witch-body
08-witch-body
09-witch-body
10-witch-body
11-witch-body
12-witch-body
13-witch-body
14-witch-body
15-witch-body
16-witch-body
17-witch-body
18-witch-body
19-witch-body
20-witch-body
21-witch-body
22-floor
23-floor
24-floor
25-floor
26-floor
27-floor
28-floor
29-floor
30-floor
31-floor
32-floor
33-floor
34-floor
35-floor
36-floor
37-floor
38-floor
39-floor
40-floor
41-floor
42-floor
43-witch-existing-capstone

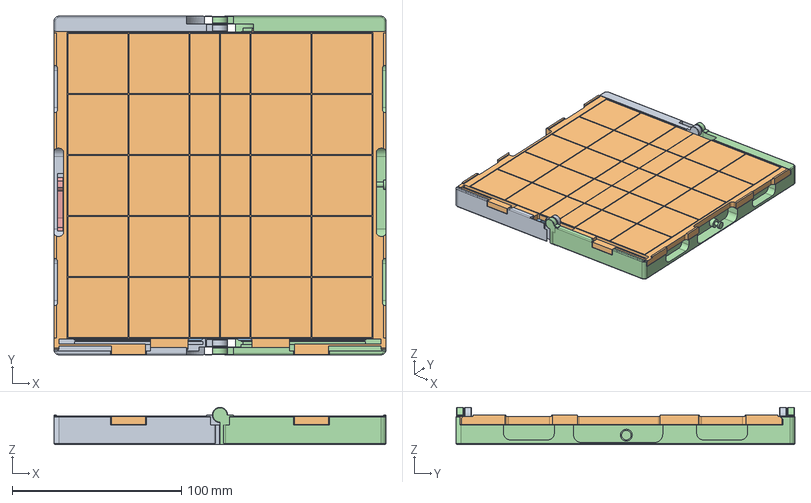
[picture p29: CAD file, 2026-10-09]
v23-r2/models/assembly-open.step
196.0 x 200.0 x 22.0 mm

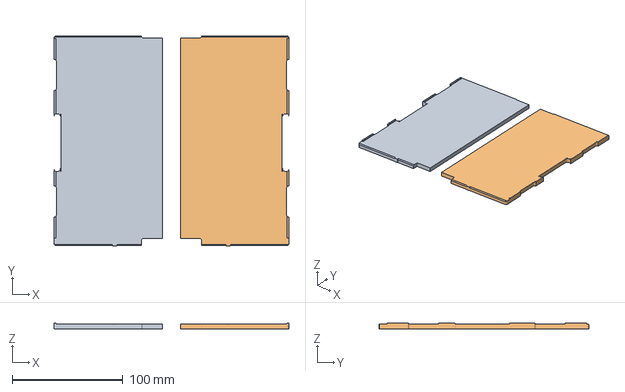
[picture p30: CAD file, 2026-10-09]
v26/FULL-PRINT/02-V26-FULL-SIZE-FOUR-COLOUR-tab-free-boards-CC2-PLA.3mf
211.8 x 189.6 x 5.70 mm
board-left
board-right

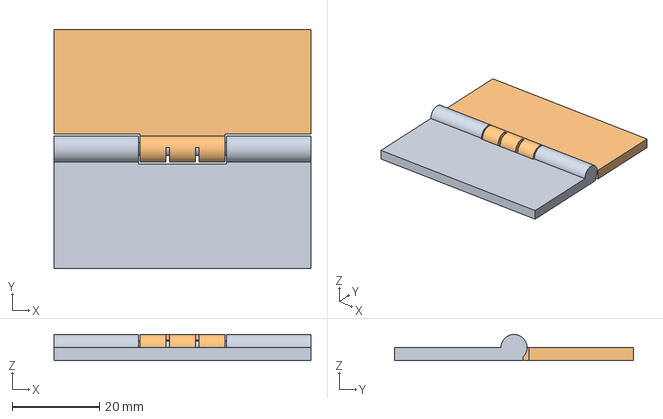
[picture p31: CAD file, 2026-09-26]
hinge-coupons/snap-hinge-assembled.step
59.0 x 54.8 x 6.00 mm

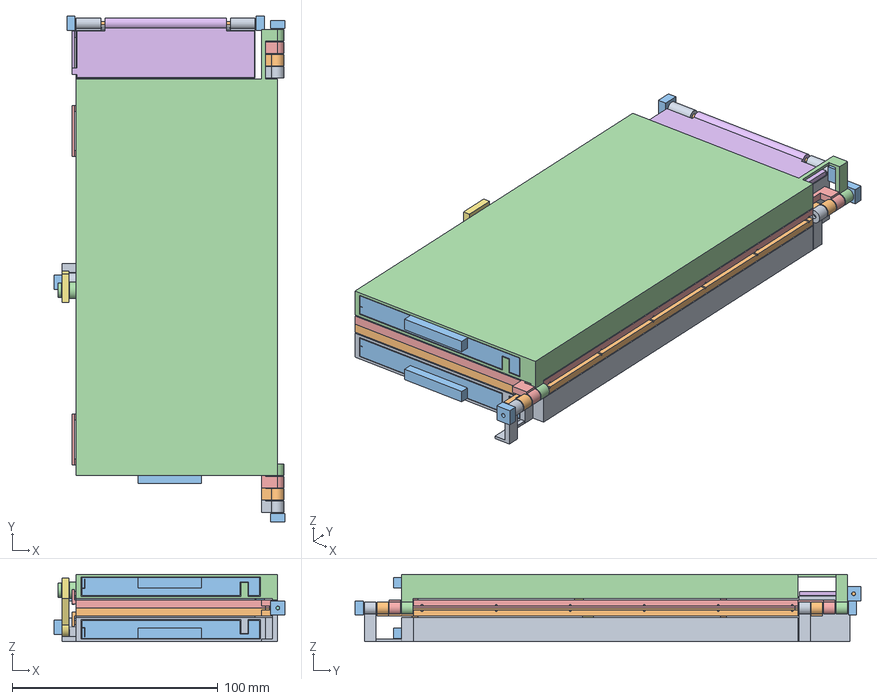
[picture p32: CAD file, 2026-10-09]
v18-case/models/assembly-closed-with-hardware.step
112.3 x 245.8 x 32.6 mm

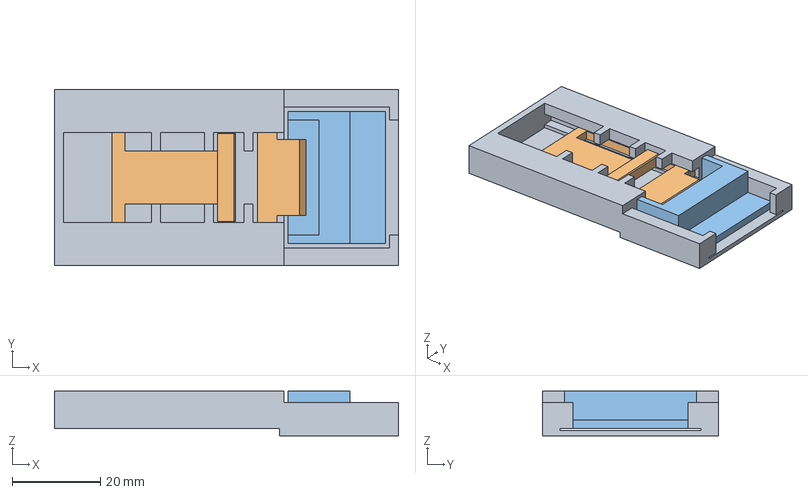
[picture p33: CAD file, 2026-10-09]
v18-recessed-clasp/states/01-locked/assembly.step
78.0 x 40.0 x 10.1 mm

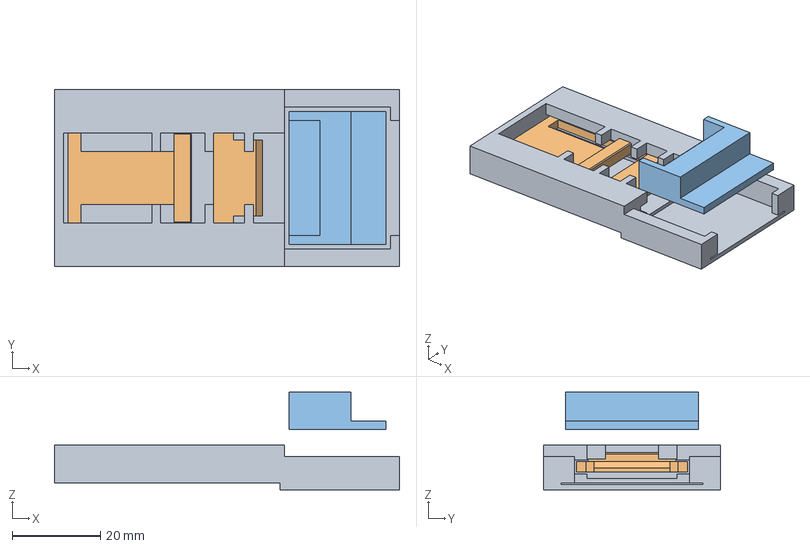
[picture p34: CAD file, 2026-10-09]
v18-recessed-clasp/states/04-open/assembly.step
78.0 x 40.0 x 22.1 mm

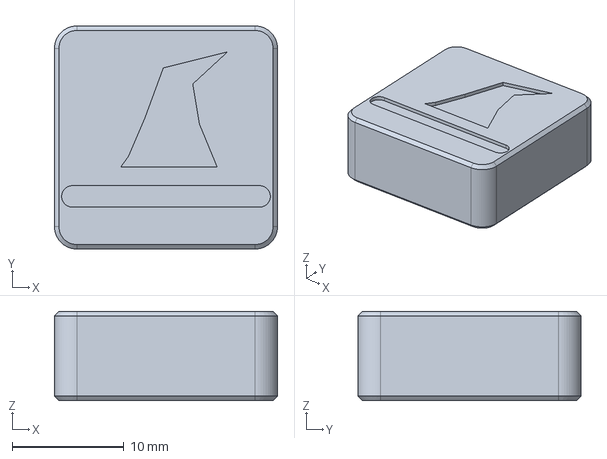
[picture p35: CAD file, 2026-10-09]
pieces/weighted-flat-capstones-v2/models/witch-regular-assembled.step
20.0 x 20.0 x 8.00 mm

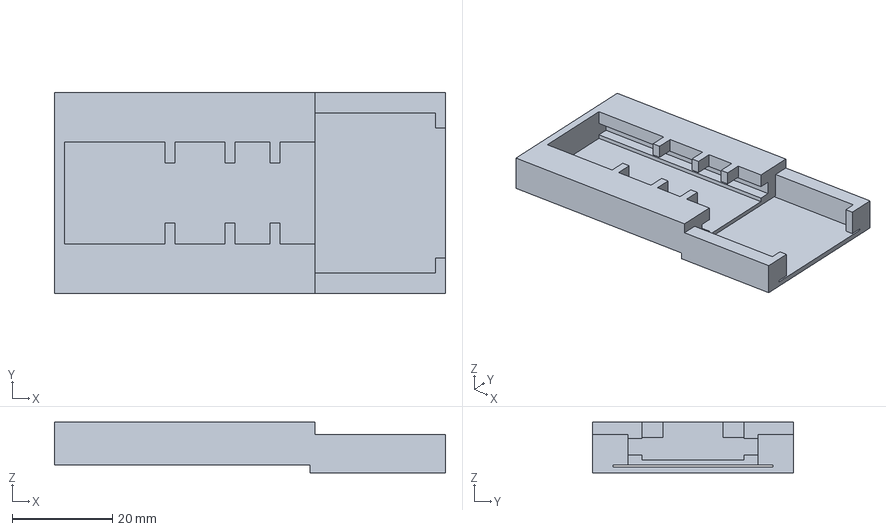
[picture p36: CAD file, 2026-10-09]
v18-recessed-clasp/parts/V18-receiver-assembled.step
78.0 x 40.0 x 10.1 mm

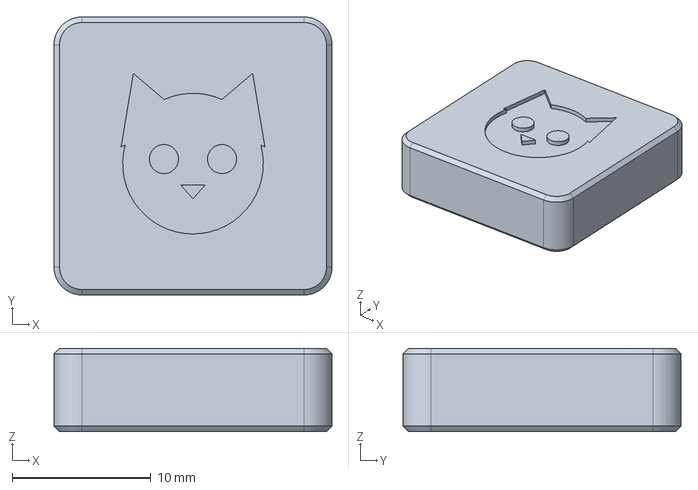
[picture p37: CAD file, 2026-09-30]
pieces/weighted-v1/models/cat-assembled-reference.step
20.0 x 20.0 x 6.00 mm

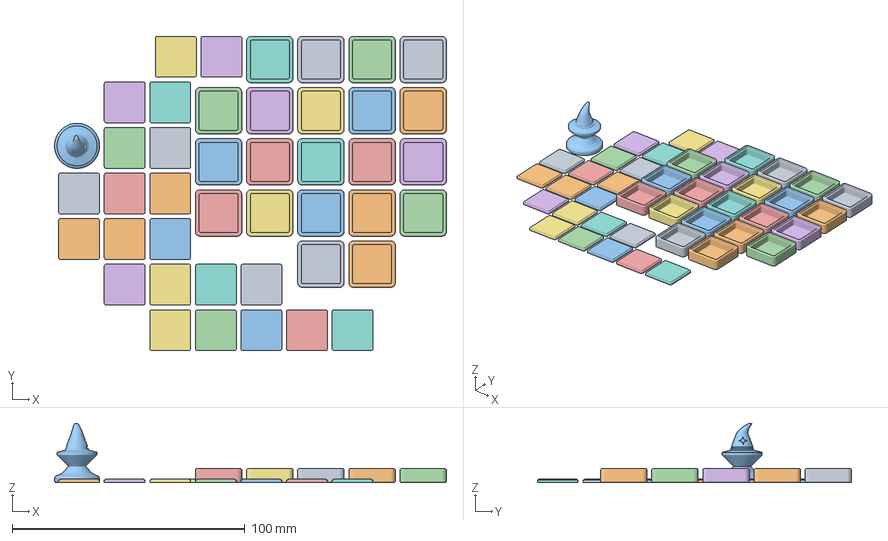
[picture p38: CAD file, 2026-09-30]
pieces/weighted-v1/plates/witch-complete-set-cc2.3mf
168.6 x 135.2 x 25.4 mm
13-witch-body
14-witch-body
06-witch-body
07-witch-body
09-witch-body
02-witch-body
08-witch-body
20-witch-body
21-witch-body
01-witch-body
10-witch-body
16-witch-body
03-witch-body
15-witch-body
11-witch-body
12-witch-body
17-witch-body
04-witch-body
05-witch-body
18-witch-body
19-witch-body
41-floor
42-floor
35-floor
34-floor
39-floor
27-floor
28-floor
40-floor
32-floor
33-floor
26-floor
25-floor
38-floor
31-floor
24-floor
36-floor
29-floor
22-floor
37-floor
30-floor
23-floor
43-witch-existing-capstone

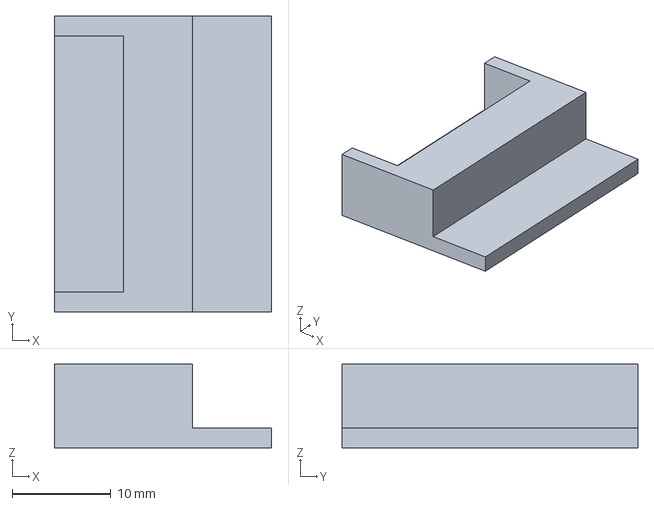
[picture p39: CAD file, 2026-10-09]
v18-recessed-clasp/parts/V18-keeper-assembled.step
22.0 x 30.0 x 8.50 mm

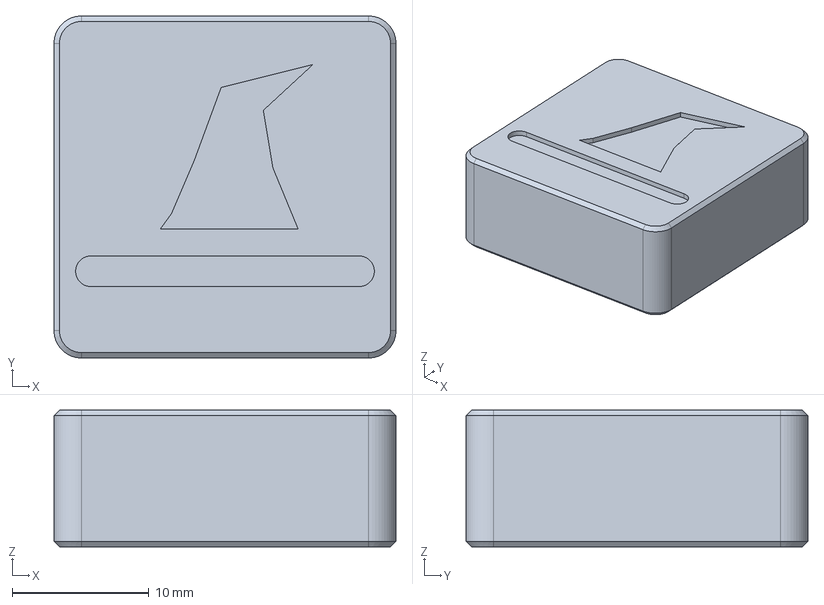
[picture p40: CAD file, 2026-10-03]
full-size-pagoda-v1/models/witch-assembled-reference.step
25.0 x 25.0 x 10.0 mm

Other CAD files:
v18-recessed-clasp/states/03-slid-clear/assembly.step
pieces/weighted-v1/plates/cat-complete-set.3mf
v18-recessed-clasp/parts/assembly.step
v18-recessed-clasp/states/02-pressed/assembly.step
pieces/weighted-v1/models/witch-assembled-reference.step
archive/v13-book/models/assembly-closed.step
archive/v13-book/models/assembly-open.step
archive/v13-book/models/assembly-trays-out.step
archive/v13-book/models/base-a.step
archive/v13-book/models/base-b.step
archive/v13-book/models/bases-hinged.step
archive/v13-book/models/clasp.step
archive/v13-book/models/grid-inlay-a.step
archive/v13-book/models/grid-inlay-b.step
archive/v13-book/models/plate-a.step
archive/v13-book/models/plate-b.step
archive/v13-book/models/tray.step
archive/v13-book/stl/full/bases-hinged-print-in-place.stl
archive/v13-book/stl/full/clasp.stl
archive/v13-book/stl/full/grid-inlay-a.stl
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

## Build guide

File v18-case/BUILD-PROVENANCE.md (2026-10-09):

# V18 side-hook full-build evidence

Prepared October 5, 2026, from the first integrated case at `08c663b199a36c8e32b333b9aae3f9fc3d63503e` on `codex/v18-complete-build`. The user explicitly selected the side hook and 1.75 mm PLA filament pins. `PACKAGE-MANIFEST.json` pins the resulting package; `reports/provenance.json` records exact defining-source and dependency hashes. Recovery base: `2589129`; original body architecture: `bad9d0f1e4b0ed55a9e6f35ae5434a32523039d1`.

## Current evidence

| Check | Result |
|---|---|
| Geometry, solids, STEP/STL, original pieces and sampled motion | 51 checks pass |
| Exported playing field and grooves | 37 material probes pass; 180 mm field / 36 mm pitch |
| Exported filament hardware and bore material | 31 checks pass |
| Five named-object geometry plates | Bed, height, separation and readback checks pass |
| Five CC2 slices | All printable objects retained, manifold, inside bed; input/profile/project hashes verified |
| Actual filament-passage toolpaths | 18 checked cores clear of model and support extrusion centerlines |
| Visual review | Five critical-layer sheets, three detailed pin sheets and actual-STEP assembly/hook previews inspected |
| Frozen original recessed-clasp package | Original 70 files and 67 manifest entries retained; verified separately |

The retained settings estimate **116312 seconds (32 h 18 min 32 s), 499.38 g**, including supports and brims. There are **13 printed parts**, four filament pins (24.9 / 24.9 / 92 / 9.6 mm), and no printed filament-reference objects. The closed hardware envelope is **112.3 × 245.8 × 32.6 mm**.

The filament-passage test checks centerlines against a nominal 1.75 mm cylindrical core, cropped at passage ends. It does not model bead swell, elephant foot, roughness, dimensional accuracy, force or physical fit. Sampled CAD motion is not a continuous sweep proof. The hook has a friction bearing and reverse stop; there is no spring detent or measured retention force. Actual accidental-opening resistance and wear remain unchecked.

## Environment and commands

Actual environment: `.slicer-work/cad-venv/bin/python`, isolated Python 3.12.13; CadQuery 2.7.0, OCP 7.8.1.1.post1, trimesh 5.1.1, NumPy 2.5.3, SciPy 1.18.1, VTK 9.3.1, Matplotlib 3.11.2. Exact installed dependencies are in `requirements.txt`.

Installed CLI: `/Applications/ElegooSlicer.app/Contents/MacOS/ElegooSlicer`, reporting ElegooSlicer-2.4.2; app client 1.5.3.5. CC2 0.4 mm machine, PLA and process profiles are retained in `profiles`. Full commands and profile/input/project/Gcode hashes are in `reports/slicing.json`; raw CLI output is in each `*-slice.log`.

Run these scripts from the repository or extracted kit root using that environment (or a Python 3.12 environment with the pinned requirements):

```sh
python v18-case/source/build_case.py
python v18-case/source/verify_field.py
python v18-case/source/verify_hardware.py
python v18-case/source/package_case.py
python v18-case/source/slice_case.py
python v18-case/source/render_case.py
python v18-case/source/inspect_case_layers.py
python v18-case/source/verify_pin_toolpaths.py
# Review rendered layers and record observations in reports/layer-inspection.json.
python v18-case/source/record_provenance.py
python v18-case/source/package_release.py
python scripts/verify_v18_freeze.py
```

After each relevant geometry change, affected exports and motion checks were regenerated. The final support correction regenerated/resliced plates 01 and 02 with `--only 01-left-housing-hook-pivot-and-cap-compartment 02-right-housing-and-hook-pin`. Other slice receipts were reused only when exact input/project/profile hashes still matched. Final passage and layer analysis read the retained Gcode from all five current projects. No printer was contacted or started.

Housing objects have a **0.8 mm support side-clearance override** stored in their 3MF metadata. Other objects retain 0.35 mm. The process uses a 30° support threshold, automatic normal supports, 0.20 mm contact gaps and three upper interface layers. Preserve the housing object settings if reslicing. The metadata follows the [upstream OrcaSlicer 3MF implementation](https://github.com/OrcaSlicer/OrcaSlicer/blob/main/src/libslic3r/Format/bbs_3mf.cpp); local exported-project readback confirms the override survives the installed slicer.

The slicer's Generic PLA warning remains recorded: 45 °C softening entry versus 60 °C bed. Match the user's tested spool settings before printing; the defaults do not qualify a material.

## Corrections and failed attempts

- The retained v17 study assumed 19.5 mm flats. The integrated drawer geometry uses the actual original 20×20×8 mm CAD with 20.7 mm seats and 0.4 mm roof clearance. The field stayed unchanged.
- The recessed mechanism was replaced by a separate rigid hook, fixed pivot pad/reverse stop and headed catch. The locked hook blocks opening at a 1° sample; release clears through 0–65° at 1° samples. The released full case clears its sampled fold path.
- Main/hatch bores changed from 3.4 mm to 2.0 mm; collars use 1.9 mm through bores. Earlier small-part slices failed the nominal pin-core test. Current parts were re-exported with welded indexed 3MF connectivity, the hatch axis upright and collars bore-up; the final toolpaths pass. The earlier 3 mm kit is preserved in `release/archive`.
- Bore subtraction before mount union left material in the fixed hook passage. The final circular/45° roof passage is cut after union; exported hardware and actual deposition checks pass.
- The first filament slices placed support in board, fixed-hatch and hook bores. Teardrop roofs and the 30° support threshold cleared those passages.
- Removing internal main-pin stops simplified retention and made the bores through passages. It did not by itself eliminate support routed through the rear knuckles. Narrow support blockers also failed to prevent those support stems, so the final kit contains no blocker volumes. A 0.8 mm housing-only support side clearance solved this: all 18 tested passages now contain no model/support centerline intrusion. Support beneath external roots and the headed catch remains visible in the final layer sheets.
- Collars alone do not stop a whole pin being withdrawn. The guide specifies bonding only the designated fixed housing barrel/ear/mount to the pin, leaving moving joints free. The hook collar lightly contacts its bearing to set friction; main/hatch collars retain 0.5 mm running gaps.

## Physical boundary

The user reports the earlier recessed-clasp trial printed and an earlier 1.75 mm PLA hinge held in place. Exact revisions, loads and cycle counts were not supplied. Those observations do not qualify the new hook or whole case. Keep [ACCEPTANCE.md](ACCEPTANCE.md) unchecked until observed. The next action is the requested full print, then a short filament pass-through check during assembly, empty operation and loaded original-piece testing. No additional coupon is required to receive this full kit.

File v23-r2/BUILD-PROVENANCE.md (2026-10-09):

# V23 R2 build evidence

This is a fresh geometry/slicing revision, not the earlier V23 identity-only migration. The retained baseline is V23 geometry from 071469c; its ZIP SHA-256 is 33510a63581b1a8b5f3c5afde34ed99acf6ecd5ccfb6bc49956e6d6e2b9e1221. The original V23 package remains unchanged. The concurrent board-inlay additions through 82aff2d are preserved in the branch; no artwork adaptation is included here.

The user reported a broken thin bar carrying the main hinge and requested stronger hinges and two removable loaded player trays for purse use. Exact fracture location, joint fusion and breaking action are unknown. Broadening the support is a design response, not an independently confirmed fracture diagnosis or a strength simulation. The selected 35 mm thickness retains the 2.2 mm case floor and 4.7 mm board body while adding a separate 1.2 mm tray floor. Larger barrels increase closed width by 1.5 mm; total envelope is 102.5 × 200 × 35 mm. No playing-field shrink occurs.

Environment: `.slicer-work/cad-venv/bin/python` in the implementation checkout; Python 3.12.13, CadQuery 2.7.0, OCP 7.8.1.1.post1. Requirements are pinned in `requirements.txt`. ElegooSlicer 2.4.2 and the included CC2 0.4 mm/PLA profiles perform offline slicing. No new dependency, printer job, merge or paid generation was used. Generic PLA softening/bed metadata warnings remain, and headless OpenGL thumbnail generation is unavailable. Separate actual-CAD previews and deposition-layer sheets are supplied.

Run with that CAD Python (or an environment matching the pinned requirements):

```text
python v23-r2/source/build_case.py
python v23-r2/source/verify_field.py
python v23-r2/source/verify_supports.py
python v23-r2/source/verify_hardware.py
python v23-r2/source/verify_trays.py
python v23-r2/source/package_case.py
python v23-r2/source/slice_case.py
python v23-r2/source/inspect_case_layers.py
python v23-r2/source/verify_pin_toolpaths.py
python v23-r2/source/build_fitcheck.py
python v23-r2/source/build_tray_trial.py
python v23-r2/source/verify_pip_hinges.py
python v23-r2/source/render_revision.py
```

Review regenerated previews/layer sheets and record that review, then run `source/record_provenance.py` and `source/package_release.py`. Source scripts resolve paths within this package and include their required vendor CAD code. `reports/provenance.json` pins source revision, dependencies, source/profile/output hashes and check totals. Per-slice reports retain commands, geometry/project/Gcode hashes, warnings and estimates. `PACKAGE-MANIFEST.json` covers every shipped payload; release audit extracts the archive and verifies hashes, JSON/Python syntax, local links and project count.

Evidence includes valid single solids and STEP/STL readback for all ten parts; disjoint assembled parts; sampled 0–180° folding, initial opening, 90° hook release, stops and complete board travel; the full exported 5×5 field; actual original Cat/Witch pieces in both trays; loaded removal/repacking at 1 mm increments; planar seat and pocket containment at nominal cover slack; broad floor and fingertip probes; continuous full-height support material probes; exact named meshes and placement in all four sliced projects and both trials. Nominal captive radial/face gap remains 0.4 mm. Sliced bead-edge gaps are sampled with a conservative 0.50 mm bead model, separately from CAD distance. These do not establish printed joint release or strength.

Resolved findings during this work:

- The first raised hook touched a rounded recess corner by 0.02284 mm³ at 90°. Expanding that recess locally by 0.8 mm in Y resolved the sampled release collision without changing the exterior envelope.
- A coarse tray lift study missed rear-rail contact. Checking every 1 mm identified it. The tray rear edge shortened 0.7 mm and the capstone bay moved forward 0.5 mm; all loaded removal/repacking samples now clear, with 0.5 mm minimum nominal plan gap at the rear rail. Low stops locate the shortened tray.
- OCCT's conservative cached bounding box put a coupon mesh about 0.000635 mm above Z0, so the slicer dropped it and exact-placement readback correctly failed. Placement now seats the actual tessellated minimum on Z0; named mesh/placement checks pass without widening the readback tolerance.

The whole-case estimate is 48,922 s / 321.56 g. The hinge trial is 2,448 s / 9.41 g and the tray trial 3,404 s / 21.52 g. Physical acceptance is false throughout. Motion checks sample rigid poses and assumed catch flex; they are not continuous sweeps, FEA, fatigue/drop tests or measured actuation. Upright open trays do not retain pieces under inversion. Full loaded transport, snag resistance, release, grasp, rattle and floor/hinge durability remain listed in ACCEPTANCE.md.

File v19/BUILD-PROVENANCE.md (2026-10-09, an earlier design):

# V19 package provenance

V19 is the user's October 5 version/package cleanup of the checked hook-and-pin case at commit `1e8944b646a6bf7190b0d1752ce53c1ed5ae7132`. It changes the distribution layout and version labels, with no geometry or print-setting changes.

The ZIP has one root folder, `v19`. `START-HERE.md` is the assembly guide; `PRINT` contains exactly five current CC2 projects. Necessary CAD dependencies are bundled under `source/vendor/body` and `source/vendor/pieces`. Historical clasp packages, old ZIPs and older version folders are excluded.

## Evidence carried forward

The five print projects, their embedded Gcode, geometry-only plates, STEP/STL exports and profiles are byte-identical to the checked source build. `reports/version-migration.json` records original paths, exact hashes and the unchanged CAD-function AST check. The inherited reports retain their original source hashes, version names and commands as historical evidence; they are not misrepresented as a fresh V19 CAD or slicer run. The retained slicer preset may still identify the validated build as V18.

That validation recorded 51 geometry/mesh/piece/motion checks, 37 field probes, 31 hardware/bore checks, five successful CC2 slices and 18 clear filament-core centerline checks. The estimate remains 32 h 18 min 32 s / 499.38 g. Whole-case physical acceptance is still pending.

Current V19 checks verify a single ZIP root, exactly five PRINT projects, CRC and payload hashes, local links, standalone source imports and unchanged CAD functions/parameters. Version-labelled assembly previews are rendered again from the same exported STEP geometry. `PACKAGE-MANIFEST.json` pins the delivered V19 files.

## Reproduction

Use Python 3.12 with `requirements.txt` and the installed macOS ElegooSlicer. The validated dependency environment was Python 3.12.13, CadQuery 2.7.0, OCP 7.8.1.1.post1, trimesh 5.1.1, NumPy 2.5.3, SciPy 1.18.1, VTK 9.3.1 and Matplotlib 3.11.2. Exact settings remain in `profiles` and the housing object overrides in the 3MFs.

From the directory containing the extracted `v19` folder:

```sh
python v19/source/verify_package.py
# A full rebuild, if needed:
python v19/source/build_case.py
python v19/source/verify_field.py
python v19/source/verify_hardware.py
python v19/source/package_case.py
python v19/source/slice_case.py
python v19/source/render_case.py
python v19/source/inspect_case_layers.py
python v19/source/verify_pin_toolpaths.py
# Review new layers and record observations in reports/layer-inspection.json.
python v19/source/record_provenance.py
python v19/source/package_release.py
python v19/source/verify_package.py
```

The fresh-build scripts resolve their dependencies within this package. Slicing writes Gcode scratch files under `v19/.slicer-work`, which is excluded from the ZIP. Rebuilding replaces inherited reports with current evidence. No re-slice is needed solely to use this repackaged kit.

No printer job was started. Physical fit, hook friction after wear, accidental opening, filament-pin strength and loaded transport remain untested; use `ACCEPTANCE.md` after the full print.

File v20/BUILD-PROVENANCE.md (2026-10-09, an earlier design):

# V20 build provenance

V20 is a new geometry revision based on V19 commit `1091f7348f525d2b72f17cad1f5f8c680509fae0`. Defining V20 source revision: `be279db7a3d2209e1bebe1ba15c63ca12d8036ef`. Current source/dependency SHA-256 values are recorded in reports/provenance.json and the package manifest. Units are millimetres.

## What changed

Fixed original-piece pockets and removable sliding lids replace both drawers and the integral housing roofs. Sloped rails retain the lids vertically; 20×5.6 mm square-shouldered thumb catches require a nominal 4.5 mm inward release. Pockets shift 4 mm inward to clear that motion. The hatch top grows 1.4 mm so its broad face can contact the bed. Bore roof reliefs follow the new print directions.

The full 180 mm field, 36 mm pitch, four-leaf hinge axis, 1.75 mm filament pin dimensions and external swivel hook remain. STEP symmetric-difference checks in reports/compatibility.json verify that the two boards, hook and collars have unchanged CAD shapes from V19. Bases, sliding lids and hatch are new. Printed interchangeability has not been observed. V18/V19 archives and printed V16 parts remain unchanged.

## Current evidence

- 56 CAD/mesh/detailed-original-piece/motion checks pass, including lid lift retention, rear stop, catch engagement, release, removal and individual flat retrieval.
- 37 exported field probes, 31 hardware checks and 43 plate/readback checks pass.
- All five CC2 slices pass with exact named mesh readback, connected watertight meshes and checked source/project/profile/Gcode hashes.
- 18 nominal filament-core checks pass against actual extrusion centerlines. They exclude extrusion width, bore-end lips, roughness and physical force.
- All five selected layer sheets and the STEP access preview were inspected. Bases and lids print flat; no trapped storage-roof supports were seen. Boards retain broad removable underside support. Some local hinge/clip support remains.
- Maximum part height: 25.8 mm. Full-kit slicer estimate: 66,374 seconds (18 h 26 min 14 s), 402.19 g including supports/brims, versus V19's 116,312 seconds / 499.38 g.
- Optional front-section rail/catch trial: 5,306 seconds / 33.18 g; its geometry, sliced mesh readback and selected layers were checked separately. It does not test full-length warping or rear stops.
- The slicer still reports the Generic PLA softening-entry/bed-temperature warning. No spool qualification or printer job was performed.

Resolved intermediate rail and entry-relief collisions are documented in reports/development-notes.json. Final geometry checks pass. Flex poses are geometric assumptions, not force or fatigue calculations; motion is sampled rather than a continuous sweep proof. The target is the original Cat/Witch CAD, with 20×20×8 mm flats. The old reference Cat capstone STL has an open mesh; valid source CAD was used for fit. Weighted flats and curled capstones remain unverified.

## Environment and reproduction

Used `.slicer-work/cad-venv/bin/python`, Python 3.12.13, with the exact dependencies in requirements.txt. Installed versions are recorded in reports/provenance.json. Slicer: `/Applications/ElegooSlicer.app/Contents/MacOS/ElegooSlicer`, reporting 2.4.2. CC2 0.4 mm machine, Generic PLA and process profiles are included. Full CLI arguments, warnings and hashes are in reports/slicing.json and reports/fit-check.json; raw slicer logs are retained.

From the directory containing v20, with its requirements installed:

```sh
python v20/source/build_case.py
python v20/source/verify_field.py
python v20/source/verify_hardware.py
python v20/source/package_case.py
python v20/source/slice_case.py
python v20/source/render_case.py
python v20/source/inspect_case_layers.py
python v20/source/verify_pin_toolpaths.py
python v20/source/build_fitcheck.py
# Inspect newly generated layer sheets and record actual observations in
# reports/layer-inspection.json and reports/fit-check-layers.json.
python v20/source/record_provenance.py
python v20/source/package_release.py
python v20/source/verify_package.py
```

The layer review step is deliberately not auto-accepted. Slicer scratch/config/Gcode files under .slicer-work are excluded from the kit; sliced projects retain their embedded Gcode. The self-contained ZIP has one v20 root, exactly five full-build projects in PRINT and a clearly separate optional FIT-CHECK folder. Source dependencies are bundled under source/vendor. No earlier-version folders or nested ZIPs are included.

Physical fit, comfortable access/release, pin retention, lid flex/warping, hook friction and loaded transport remain unchecked in ACCEPTANCE.md.

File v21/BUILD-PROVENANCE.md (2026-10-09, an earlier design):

# V21 build provenance

V21 derives from V20 commit `1d03201fd003e3aff38fde6c7f1d94d1befbab54`. Defining source revision: `d928d5116226ef307aee9c3486a08b7268a15716`. Exact source/dependency hashes are recorded in reports/provenance.json and PACKAGE-MANIFEST.json. Units are millimetres.

## What changed

The two playing boards now double as storage lids, sliding outward above fixed original-piece pockets. Separate lids and board hinges are removed. Only the bases hinge. Rails prevent lifting; front catches block withdrawal until pressed rearward 2.8 mm; inner stops locate the seated boards. Boards are fully removable with 106 mm outward travel. Catch poses are geometric assumptions, not force or fatigue calculations.

The full 180 mm field and 36 mm pitch remain. Main filament pins shorten to 14.9 mm. The side hook moves to the front corner to clear board travel, and the rear compartment shifts 2 mm for rail clearance. New bases and boards are required. Exported STEP symmetric-difference checks in reports/compatibility.json confirm unchanged hatch, hook and collar shapes after assembly translation. Printed interchangeability is unobserved. Earlier packages and printed parts remain intact.

## Evidence

- 52 solid, mesh, original-piece clearance and sampled motion checks pass.
- 37 exported field probes, 29 hardware and 39 plate/readback checks pass.
- Four CC2 slices pass, with named object/mesh readback and verified input, profile, project and Gcode hashes.
- 16 filament-core checks pass against extrusion centerlines. They exclude extrusion width, bore-end lips, roughness and physical insertion force.
- All four selected layer sheets and actual STEP previews were reviewed. Broad base floors and board undersides contact the bed. No broad board support blanket appears in selected layers; local hinge/hatch/hook support remains. Slicer support metadata is not a claim of support-free printing.
- Maximum part height: 25.8 mm. Full-kit estimate: 45,289 seconds (12 h 34 min 49 s), 287.29 g including supports/brims.
- Optional shortened front/rear rail and catch fixture: 10 checks pass; sliced mesh readback and selected layers reviewed. Estimate: 3,587 seconds / 19.26 g. It does not test full-board warping, inner stops, hinges or loaded transport.
- Generic PLA softening-entry/bed-temperature warning remains in slicer logs. No spool qualification or printer job was performed.

The target is the original Cat/Witch CAD: 42 flats at 20×20×8 mm plus the original capstones. The old reference Cat capstone STL has an open mesh; valid source CAD supplies fit geometry. Weighted flats and curled Fox/Cat capstones remain unverified. Sampled collision checks are not continuous motion proofs or physical acceptance.

## Environment and reproduction

Used `.slicer-work/cad-venv/bin/python`, Python 3.12.13, with requirements.txt dependencies. Installed versions appear in reports/provenance.json. Slicer: `/Applications/ElegooSlicer.app/Contents/MacOS/ElegooSlicer`, version 2.4.2. CC2 0.4 mm machine, Generic PLA and process profiles are included. CLI arguments, warnings and hashes appear in reports/slicing.json and reports/fit-check.json; raw slicer logs are retained.

From the directory containing v21, with its requirements installed:

```sh
python v21/source/build_case.py
python v21/source/verify_field.py
python v21/source/verify_hardware.py
python v21/source/package_case.py
python v21/source/slice_case.py
python v21/source/render_case.py
python v21/source/inspect_case_layers.py
python v21/source/verify_pin_toolpaths.py
python v21/source/build_fitcheck.py
# Inspect newly generated layer sheets, then record actual observations in
# reports/layer-inspection.json and reports/fit-check-layers.json.
python v21/source/record_provenance.py
python v21/source/package_release.py
python v21/source/verify_package.py
```

Visual review is not auto-accepted. Slicer scratch/config/Gcode under .slicer-work is excluded; sliced projects retain embedded Gcode. The ZIP has one v21 root, four full-build projects in PRINT and a separate optional FIT-CHECK folder. Required source dependencies are bundled in source/vendor. No older version folders or nested ZIPs are included.

Physical fit, comfortable release/retrieval, pin retention, board flex/warping, hook friction and loaded transport remain unchecked in ACCEPTANCE.md.

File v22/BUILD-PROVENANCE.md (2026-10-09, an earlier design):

# V22 first-print kit evidence

V22 keeps the 32.6 mm thin case and replaces the rear compartment/hatch with one-piece flat Cat/Witch capstones beneath the sliding boards. Closed size including hardware is 111.8 × 220.2 × 32.6 mm, 23.6 mm shorter than V21. The 180 × 180 mm, 5×5 playing field remains unchanged. Units: mm. Defining source revision and dependency hashes are in [reports/provenance.json](reports/provenance.json).

Based on V21 commit `0fd6806`, with opposed captive main pivots adapted from V16 source geometry (3 mm diameter, 0.4 mm radial and face clearance). Both bases print together flat in one assembly. Boards, side hook and the remaining hook collar have zero CAD symmetric difference from V21. The only filament pivot is the 9.6 mm side-hook pin. Physical interchangeability has not been observed.

59 geometry/mesh/piece/motion checks, 37 field probes, six hardware checks, 20 plate/readback checks, three filament-core checks and 20 flat-capstone checks pass. Three slices pass with exact named meshes and preserved assembly positions. Full kit estimate: 40,629 seconds (11 h 17 min) / 267.67 g. Eight printed parts; maximum part height 19.3 mm. The optional shortened hinge pair passes eight checks and slices to 1,290 seconds / 3.80 g.

32 captive-hinge checks pass: CAD clearance and opposed axial capture, no support centerlines within the cylindrical bearings, and sampled radial toolpath gaps in both full and trial prints. With a conservative 0.50 mm bead-width assumption, sampled side gaps measure 0.385–0.422 mm. This is not a continuous swept-volume or physical force/strength proof. Selected layers, gap plots and actual STEP previews were visually reviewed.

The exact piece package is 42 original Cat/Witch 20 × 20 × 8 mm flat stones plus two new V22 8 mm flat capstones. Vendored original flat STLs and defining source hashes are retained. Capstones have nominal 0.4 mm roof clearance and 4.5 mm exposed height above the bay rim; loaded folding, sliding, discrete retention poses and vertical retrieval checks pass. Older sculpted capstones do not fit these bays. Weighted flats remain unqualified. The capstone preview shows optional contrast paint; each capstone prints as one solid part.

Environment: repository `.slicer-work/cad-venv/bin/python`, Python 3.12.13; [requirements.txt](requirements.txt) pins the dependencies. ElegooSlicer 2.4.2, CC2 0.4 mm nozzle and included PLA/process profiles. Commands and profile hashes are recorded in slicing and fit-check reports. No printer job started. Generic PLA temperature-metadata warnings remain (45°C softening metadata versus 60°C bed). Missing CLI OpenGL thumbnails are replaced by separate actual-geometry previews.

Run from the repository root using the CAD environment, in order:

```text
python v22/source/build_case.py
python v22/source/verify_field.py
python v22/source/verify_hardware.py
python v22/source/verify_flat_capstones.py
python v22/source/package_case.py
python v22/source/slice_case.py
python v22/source/render_case.py
python v22/source/inspect_case_layers.py
python v22/source/verify_pin_toolpaths.py
python v22/source/build_fitcheck.py
python v22/source/verify_pip_hinges.py
```

Review regenerated layer sheets before marking their reports reviewed, then run `record_provenance.py`, `package_release.py` and `verify_package.py` from the same source directory. The packaged source resolves its own paths and can also run from an extracted kit. Fresh extraction and standalone reconstruction evidence is recorded outside the archive in `docs/V22_PACKAGE_CHECK.json`.

Resolved implementation issues: separate-object slicing reported conflicting paths; grouping the disjoint base meshes into one assembly fixed it without merging them. Named-mesh readback verifies each component and world placement. The gap checker initially mistook internal infill voids for a missing pin; it now uses outer pin contours and segment-capsule intersections. An optional capstone edge chamfer caused a small Witch STEP volume readback discrepancy; removing it restored matching readback while retaining rounded outline corners. A tessellated bounding-box offset was removed from stored-piece placement; exact CAD bottom planes now set the storage height. No new dependencies were added.

Physical acceptance remains unchecked in [ACCEPTANCE.md](ACCEPTANCE.md): hinge release, warping, slider effort, capstone recognition/grip, hook retention and loaded transport require the printed build.

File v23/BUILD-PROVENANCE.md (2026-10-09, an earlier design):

# V23 — identity correction and accepted print evidence

This revision replaces the corner hook and projecting hinge roots with a centered recessed hook assembly, offset recessed board grips and rounded hinge-end shoulders within the case length. The complete closed outline, including hook, catch and pivot/collar, is **101 × 200 × 32.6 mm**. The earlier V22 kit measured 111.8 × 220.2 × 32.6 mm. Thickness and the full 180 mm, 5×5 / 36 mm-pitch field are preserved. Units: mm.

The user named this accepted seamless design **V23**. This release changes identity only: CAD/STEP/STL geometry, object placement, executable Gcode, material and process values remain equivalent to geometry source `4859c9c` and packaged artifact `19b8773`. Prior geometry/motion/slicing reports are retained unchanged, including their historical V22 paths and labels. They are evidence from the accepted run, not new V23 runs.

[reports/identity.json](reports/identity.json) bridges those receipts to the current files. [reports/provenance.json](reports/provenance.json) records the current source identity; [reports/validation-origin.json](reports/validation-origin.json) preserves the original validation provenance. Only the process preset's name/setting ID and its embedded Gcode comment change; the Gcode checksum is updated. Actual-geometry preview titles are regenerated as V23.

The original corner-hook V22 source/package is restored from `02f8a09`, with its 111.8×220.2×32.6 mm envelope and original ZIP unchanged. The previous seamless delivery is archived at `v22/release/archive/tak-v22-seamless-before-v23.zip` in the repository. Current delivery is `v23/release/tak-v23-print-kit.zip`. V18–V21 remain preserved.

Both bases print together flat with 3 mm opposed captive pivots and 0.4 mm nominal radial/face clearance. Rounded shoulders now lie in the front and rear end margins, clear of the playing field. The hook releases through 90° and parks at Z1.5–9.9, below the board underside at Z10.6. Its headed 3 mm catch, 3.2 mm hook and round 2 mm collar are fully recessed. One 8.6 mm length of 1.75 mm PLA provides the hook pivot. The 52×30.2 mm side recess admits a 12 mm thumb-pad clearance probe beside the hook; 30 mm-wide finger wells admit a 7 mm probe beneath the board edge. These are geometric access checks, not measured human comfort.

Accepted validation checks reused without rerunning geometry or slicing: 59 solid/mesh/STEP/fit/motion checks; 37 exported field probes; eight hardware checks including the whole folding path; 29 exterior/access/wall probes; 254 preliminary exterior mechanism trial checks; 20 plate/readback checks; three filament-core toolpath checks; 32 captive-hinge checks; 20 capstone checks; eight hinge trial checks; 129 recessed-closure trial checks. Motion is sampled, not a continuous swept-volume proof. Flexing release poses are assumed rather than FEA or measured force.

Three CC2 PLA slices pass with exact named meshes and preserved placement. Full-build estimate is **41,899 s (11 h 38 min 19 s) / 272.16 g**, eight printed parts, 19.3 mm maximum part height. The optional hinge trial is **1,556 s / 5.31 g**; the optional recessed closure trial is **3,175 s / 13.39 g**. Selected actual deposition layers, captive gaps and exported-geometry previews were reviewed. With a conservative 0.50 mm bead-width assumption, sampled captive running gaps are **0.384–0.422 mm**. No support centerlines enter the checked cylindrical bearings; this does not prove all extrusion clearances or physical joint release.

The exact piece package remains 42 original Cat/Witch 20×20×8 mm flats and two supplied one-piece 8 mm Cat/Witch capstones. Capstone geometry is identical to the earlier V22 kit; nominal storage roof gap remains 0.4 mm. Both bases, both boards, hook and collar have changed and must be replaced together. No printed interchangeability is claimed. Older sculpted capstones do not fit; weighted flats remain unqualified. The 1.8 mm closure backing wall, 1.2 mm local recess floor and 2.2 mm floor beneath pieces pass material probes. Rounded captive journal rims still need careful physical release/strength evaluation.

Environment: repository `.slicer-work/cad-venv/bin/python`, Python 3.12.13, CadQuery 2.7.0; [requirements.txt](requirements.txt) pins dependencies. ElegooSlicer 2.4.2 with included CC2 0.4 mm, PLA and process profiles. No new dependencies were installed. Slice reports retain commands/profile/input/project/Gcode hashes. Generic PLA temperature-metadata warnings remain (45°C softening entry versus 60°C bed). CLI OpenGL thumbnail generation is unavailable; separate actual-CAD previews are provided.

Reproduce using the CAD Python environment:

```text
python v23/source/build_exterior_trial.py
python v23/source/build_case.py
python v23/source/verify_hardware.py
python v23/source/verify_exterior.py
python v23/source/verify_field.py
python v23/source/verify_flat_capstones.py
python v23/source/render_case.py
python v23/source/package_case.py
python v23/source/slice_case.py
python v23/source/inspect_case_layers.py
python v23/source/verify_pin_toolpaths.py
python v23/source/build_fitcheck.py
python v23/source/build_closure_fitcheck.py
python v23/source/verify_pip_hinges.py
```

Review regenerated layer sheets and record their observations, then run `record_provenance.py`, `package_release.py` and `verify_package.py` under `v23/source`. For this identity-only release, run `python scripts/verify_v23_identity.py --write-report`, then `python v23/source/record_provenance.py --reuse-accepted-validation` and the V23 package/verify scripts. Run `scripts/audit_v23_release.py` for fresh extraction, all payload hashes/syntax/local links and equivalence against the accepted archive. No new CAD reconstruction or slicing is claimed; byte-identical CAD exports and equivalent geometry source provide the identity proof. Its receipt is outside the archive at `docs/V23_PACKAGE_CHECK.json`. Source scripts resolve their own package paths and work from an extracted kit with the pinned CAD environment.

Resolved trial findings: a direct corner-hook relocation collided with the boards. The narrowed hook, revised pivot/catch heights, board-edge relief and 90° parked position remove those collisions. A high tongue corner briefly touched the recess roof during release; narrowing that tongue resolved it without removing the catch-engagement check. The initial reverse-stop block intruded into the pivot disc; moving it under the thumb foot restored independent rotation and the reverse stop. Hinge relief corners were rounded after the actual-geometry review, then the affected build and slices were regenerated. Earlier V22 separate-object slicing was resolved by keeping the base pair grouped as one assembly; that placement is preserved.

The fresh reconstruction initially failed an unnecessarily strict volume-only tolerance on the right base (about 0.00084 mm³). Direct Boolean comparisons showed zero symmetric difference, with bounds matching within 0.000001 mm. The independent audit now requires valid single solids, the existing 0.01 mm³ STEP volume tolerance, symmetric difference below 0.00001 mm³ and bounds within 0.000001 mm for all eight parts. This checks shape identity as well as numerical integration.

Physical snag resistance, thumb/finger comfort, joint release, stiffness, wear, fit and loaded retention remain unchecked in [ACCEPTANCE.md](ACCEPTANCE.md). No printer job, paid generation or merge was performed.

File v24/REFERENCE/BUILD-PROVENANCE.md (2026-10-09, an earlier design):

# V24 build and retained print evidence

The folder organization changed after the accepted colour build. The seven files in FULL-PRINT and SMALL-TRIALS are byte-identical to the accepted sliced projects, preserving geometry, material assignments, settings and embedded toolpaths. [Organization proof](reports/organization.json) records the checks; [START-HERE](../START-HERE.md) is the printing guide. No geometry, motion or slicing reruns were needed for this organization change. The evidence below describes the retained colour-inlay validation.

The accepted celestial artwork now forms real, separate printable inlays on **V24** boards. The face is Z16.5, underside Z11.8; 0.6 mm flush inlays occupy Z15.9–16.5. The default board 3MF has two registered board assemblies, each with body, grid, stars and two accent parts. Slots are 1 black, 2 white grid/stars, 3 silk accent 1 and 4 silk accent 2. Gold and purple are examples. The generic silk placeholders are not actual spool profiles: select both actual profiles and reslice before printing.

The changed surfaces retain the full 180 mm 5×5 / 36 mm field and V24's wider hinge-corner reliefs, catches, rails and grips. Case mechanics, 102.5×200×35 mm envelope, two removable loaded trays, original flats and 8 mm flat capstones are unchanged. No exterior artwork is added: playing faces fold inward.

## Current checks

- [Board geometry receipt](board-inlays/reports/geometry.json): 207 checks covering valid CAD, STEP readback, welded watertight STL meshes, no material overlaps, flush inlays, exact filled-board envelope and unchanged geometry below the inlays, all 25 cell surfaces and white grid lines, exact original stored pieces, loaded slides at 2 mm samples through 106 mm, and folding against the opposite loaded half at 5° samples through 180°. Exported grouped geometry 3MFs are read back for named parts, mesh coordinates, bed placement, group separation and four material assignments.
- [Hardware interfaces](board-inlays/reports/hardware-interfaces.json): five additional checks cover paired folding and full released sliding past the retained hook pivot/collar, folding past the parked hook, closing the hook over the coloured boards and the unchanged complete closed envelope.
- [CC2 slicing receipt](board-inlays/reports/slicing.json): new board and small trial dry slices in ElegooSlicer 2.4.2; each sliced project's named meshes, triangle counts, world transforms, four assignments, profiles, bed containment and embedded G-code hashes are read back. Board maximum vertex error remains below 0.00004 mm.
- [Actual deposition receipt](board-inlays/reports/colour-layers.json): six checks confirm white, accent 1 and accent 2 deposit on the actual model in every one of the six inlay layers for both projects. The prime tower lies outside the inspected model regions. [Layer image](board-inlays/previews/05-sliced-colour-layer.png) is generated from embedded G-code.
- [Accepted unchanged-mechanics receipt](reports/unchanged-mechanics.json): the colour-inlay revision proved retained mechanical exports, profiles and unaffected projects matched its baseline. The current organization receipt preserves those artifacts and proves algorithm-source equivalence after repository-root path updates. Unaffected base/tray/hook tests are reused, not rerun.
- [Preview review](reports/inlay-preview-review.json): actual component STEP files supply all four surface colours in open/play and trays-beside-board views. The closed view correctly hides the inward-folded artwork. Large captions, clear white grid and decorative-only colour meaning are inspected. Existing storage/hinge/tray previews are preserved because their geometry is unchanged.

The slicer GUI was showing an unsaved base project and an active device print. Its New Window action did not expose a separate controllable review window, so the existing project was left intact. No GUI import/material-panel verification is claimed. The exported project metadata and actual sliced model deposition are independently checked. No print job was sent or altered.

## Historical evidence

Before-inlay V24 archive: `v24/REFERENCE/HISTORY/archive/tak-v24-before-board-inlays.zip`, SHA-256 `5d48e11d789e2d2e1de48067df9993958c19a91a95c3c81998b7d06d61d66a9d`. It is preserved in the repository, not nested inside the current kit. Baseline merge is `b766181`; original mechanical geometry source is `1078f0e`.

[Historical identity provenance](reports/historical-identity-provenance.json), [identity receipt](reports/identity.json), [validation origin](reports/validation-origin.json) and [earlier build notes](reports/validation-notes.md) describe the earlier V24/V23 R2 equivalence. Their whole-kit identity, 238-check totals, monochrome board slicing and groove-only field checks are **historical**, not current multipart-board validation. The [accepted inlay provenance](reports/accepted-inlay-provenance.json) separates the surface evidence from unchanged mechanics; [current provenance](reports/provenance.json) records the organization-only delivery. Original V23, V23 R2 and all earlier archives remain intact.

The `models/board-*.step` and original `models/assembly-*.step` are retained monolithic mechanical references. Active colour CAD lives in `board-inlays/models`; the default print project and current assembled previews use those real parts. Do not use the old monolithic references as a multicolour print project.

## Reproduce

Use the retained `.slicer-work/cad-venv/bin/python` environment: Python 3.12.13, CadQuery 2.7.0, OCP 7.8.1.1.post1; versions in requirements.txt and the receipts. Artwork is vendored locally from V16; the accepted V23 role split is adapted to V24 geometry. All dimensions are millimetres.

Run from the repository root with that Python executable:

```text
python v24/REFERENCE/board-inlays/source/build.py
python v24/REFERENCE/board-inlays/source/verify_hardware_interfaces.py
python v24/REFERENCE/board-inlays/source/slice.py
python v24/REFERENCE/board-inlays/source/inspect_layers.py
python v24/REFERENCE/board-inlays/source/install.py
python v24/REFERENCE/board-inlays/source/render.py
python v24/REFERENCE/source/render_revision.py --only 01-open
python v24/REFERENCE/source/render_revision.py --only 02-closed
python v24/REFERENCE/source/render_revision.py --only 03-table-setup
python v24/REFERENCE/source/package_release.py
```

Parent CAD captions are composed with a deterministic DejaVu Sans font after rendering because the macOS VTK glyph atlas intermittently dropped leading characters. Wait for renders before recording hashes. Original mechanical build/package scripts remain; `package_case.py` and `slice_case.py` now leave plate 02 to the multipart pipeline, preventing an accidental monochrome overwrite. Fresh mechanical rebuild instructions remain in the historical build notes and require their own checks if those sources change.

The current ZIP audit verifies one `v24` root, four FULL-PRINT projects, three SMALL-TRIALS projects, every manifest hash, JSON/Python syntax, nested 3MF integrity and local Markdown links. `REFERENCE/reports/PACKAGE-AUDIT.json` stays outside the ZIP to avoid a circular hash. Archive provenance does not claim a physical print.

## Estimates and remaining physical work

The four complete projects estimate **61,242 s / 326.85 g** (17 h 0 min 42 s), excluding 42 original flats. The board pair is **29,275 s / 121.16 g**; the colour trial **4,348 s / 19.45 g**. Existing hinge trial: 2,448 s / 9.41 g; tray trial: 3,404 s / 21.52 g. Estimates depend on actual filament/purge profiles. Boards use 0.10 mm layers (0.20 mm initial), four walls, 20% gyroid and a prime tower; unchanged mechanical plates retain 0.20 mm layers.

The build and slices passed without geometry or slicer failures. VTK captions dropped leading characters on two assembled renders; deterministic caption composition corrected them. Headless slicer thumbnail/OpenGL warnings are retained in logs; CAD and G-code previews provide the inspected views. Generic PLA temperature metadata warnings do not establish actual silk suitability.

Motion is sampled, catch flex is assumed and checks are not FEA/fatigue tests. Physical silk bonding, colour purity, full-board warping, catch friction, hinge durability, tray grip and loaded transport remain pending on the [acceptance sheet](ACCEPTANCE.md). No actual silk spool has been selected and no printer job or merge is performed by this integration.

## Repackage without reslicing

Run `python v24/REFERENCE/source/package_release.py`. This refreshes the seven clearly named projects and preview, checks preservation and generator paths, then creates and audits `v24/V24-PRINT-KIT.zip`. Internal build outputs remain under REFERENCE so their relative source/model/profile links stay together. Older ZIPs and user extractions remain under REFERENCE/HISTORY in the working folder and are excluded from the download. Geometry-only 3MFs are never copied into FULL-PRINT or SMALL-TRIALS.

[Extracted-kit rebuild check](reports/extracted-rebuild.json) runs the publishing/package command from a fresh extraction outside Git, without historical archives. All seven output projects remain byte-identical and the extracted package passes the same tree/link/hash audit.

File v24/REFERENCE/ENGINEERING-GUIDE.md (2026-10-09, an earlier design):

# V24 assembly and compatibility

For print files, use [START-HERE](../START-HERE.md) and the FULL-PRINT folder one level up. This reference explains the mechanics and assembly.

**V24 now includes the accepted four-colour playing surface in the actual printable boards and assembled previews.** The reinforced hinges, removable player trays and **102.5 × 200 × 35 mm** case remain unchanged.

Open [the four-colour board project](../FULL-PRINT/02-FULL-SIZE-FOUR-COLOUR-inlaid-boards-CC2-PLA.3mf). It has black in slot 1, white grid/stars in slot 2 and independent silk accents in slots 3 and 4. **Select your actual silk profiles and reslice before printing:** gold and purple are preview examples, and both supplied silk profiles are generic PLA placeholders. Keep the grouped parts and all four assignments.

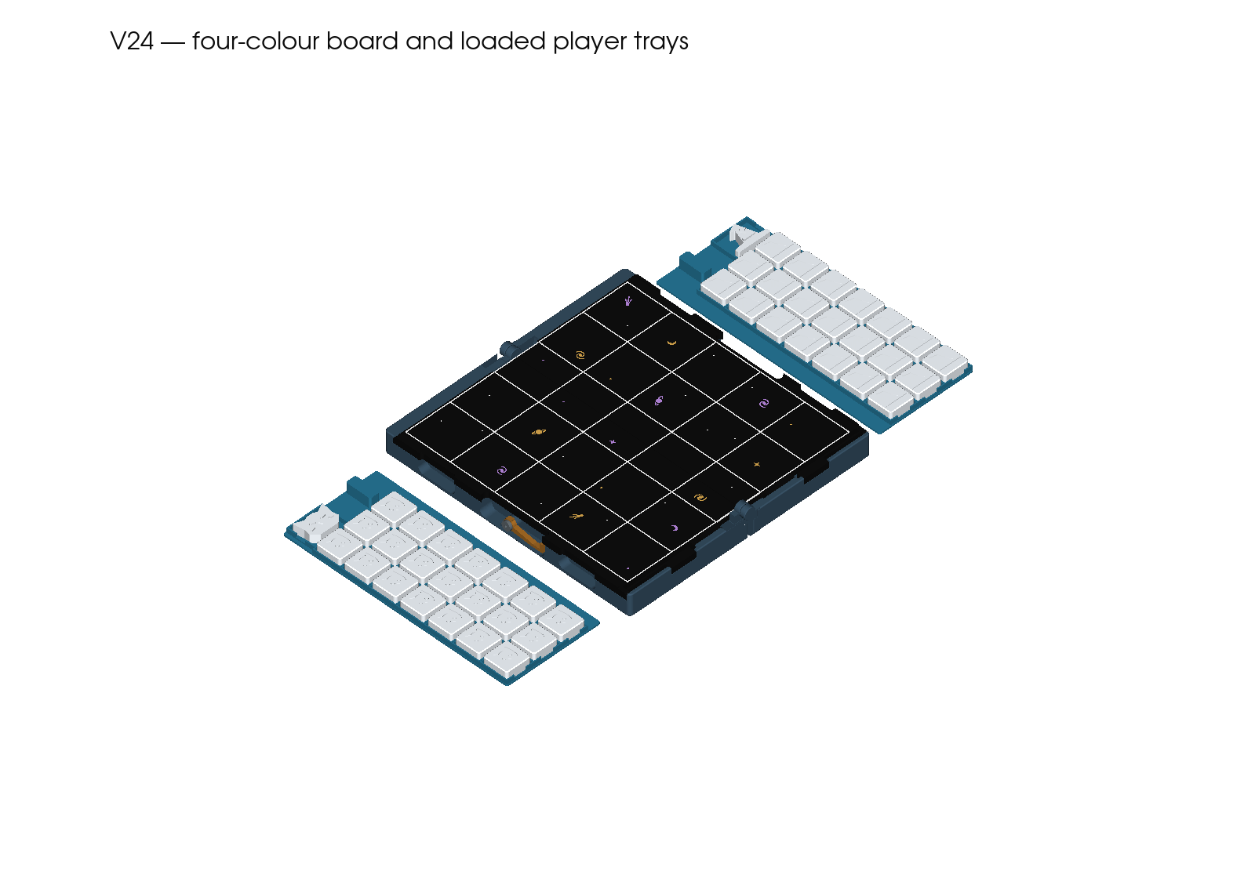
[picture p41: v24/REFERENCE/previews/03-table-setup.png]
V24 four-colour board with loaded trays beside it


The white grid carries the playing information; the accents are decoration. Inlays are flush, 0.6 mm deep, on the full 180 mm / 36 mm field. The playing faces fold inward, so the closed exterior does not show the artwork. [Four-colour details and material map](board-inlays/README.md).

This is the mechanical revision following the user's report that the thin bar carrying the V23 main hinge broke. The exact fracture location, whether a joint was fused and the action causing failure are unknown. Print the small trials first to evaluate this new support and tray design. Digital checks do not establish impact strength or physical fit.

## What changes

- Full-height **8 mm radial hinge supports**, **4 mm captive pivots** and **9 mm barrels** replace the old roughly 2.3 mm upper supports, 3 mm pivots and 6 mm barrels. Barrel rims have 0.4 mm rounding; nominal socket wall is 2.1 mm before rounding and blind outer cap is 1.3 mm. The bases still print together with captive main joints.
- Two separate **76.2 × 182.1 × 9.2 mm** player trays each hold 21 original 20 × 20 × 8 mm flats and one supplied 8 mm flat capstone. An 8 mm-wide, 20 mm-long pinch handle has room for the checked 14 mm fingertip probes on both sides. A broad 1.2 mm floor rests directly on the retained 2.2 mm case floor.
- Low seat stops provide 0.4 mm nominal planar clearance. Covers limit upward movement, with 0.4 mm nominal clearance over pieces and handles. Pocket rims contain the pieces during upright tray handling; open trays are not inversion-retaining.
- Closed envelope including hinge barrels: **102.5 × 200 × 35.0 mm**. Compared with V23, that is 1.5 mm wider at the stronger barrels and 2.4 mm thicker. The 180 × 180 mm, 5 × 5 playing field and 36 mm pitch remain. The boards keep their 4.7 mm body thickness; their corner reliefs widen to clear the stronger supports. The side hook is longer for the raised covers, and its recess clears the parked hook.

The 35 mm choice retains case and board thickness while making room for the independent tray floors. Keeping 32.6 mm would require removing 1.2 mm elsewhere per half, such as thinning the boards to 3.5 mm or case floors to 1.0 mm. Those alternatives were not qualified. Neither the proposed 1.2 mm tray floor nor hinge strength has physical acceptance yet.

Full-build dry-slicer estimate with placeholder silk profiles: **17 h 1 min / 326.85 g**, excluding the original 42 flats. The hinge trial is **40 min 48 s / 9.41 g**; the tray trial is **56 min 44 s / 21.52 g**.

## Small trials

1. Open [the hinge/support trial](../SMALL-TRIALS/01-SMALL-hinge-support-trial-CC2-PLA.3mf). Its front and rear sections come from the new exported bases, joined by fixture strips. Carefully remove external support, free both joints and cycle them through the whole range. Record whitening, cracks, binding or a fused joint before applying force. This checks local support/joint behaviour, not full-base warping or purse durability.
2. Open [the tray fit/access trial](../SMALL-TRIALS/02-SMALL-removable-tray-access-trial-CC2-PLA.3mf). It contains the actual rear section of the tray and its case seat, including three flat pockets, capstone bay and pinch handle. Load three original flats and a supplied flat capstone; check seating, pinch access and upright lifting. The open-ended fixture does not qualify full-case containment or full-tray bending.

3. Open [the four-colour inlay trial](../SMALL-TRIALS/03-SMALL-FOUR-COLOUR-inlay-trial-CC2-PLA.3mf). Choose actual silk profiles and reslice; check flushness, bonding, fine details and colour bleed. Estimate with placeholders: **1 h 12 min / 19.45 g**.

[Acceptance sheet](ACCEPTANCE.md) records the remaining physical work.

## Complete build

The four projects in FULL-PRINT are for the Centauri Carbon 2, 0.4 mm nozzle, PLA, four walls and 20% gyroid. Mechanical plates use 0.20 mm layers; the four-colour boards use 0.10 mm layers with a 0.20 mm first layer and prime tower:

1. Paired bases: print together open flat, preserving their assembly grouping and object-specific support/brim settings.
2. [Both four-colour sliding boards](../FULL-PRINT/02-FULL-SIZE-FOUR-COLOUR-inlaid-boards-CC2-PLA.3mf): flat undersides down, playing faces up. Two grouped board objects, each with five named parts across four material slots. About **8 h 8 min / 121.16 g** with placeholder profiles.
3. Both removable player trays: broad flat undersides down.
4. Flat capstones, longer side hook and collar.

The only added hardware is the hook's **8.6 mm length of straight 1.75 mm PLA filament**. Main hinges take no inserted pin or glue. Secure the hook pin at its stationary mount and collar, keeping adhesive out of moving parts; set light friction at the collar. No positive hook detent is claimed.

For play: park the side hook, unfold the case flat, press each front release button rearward 2.8 mm, then slide each board outward 106 mm and lift it away. Pinch the rear handle and lift each loaded tray vertically. Set trays upright beside the board and reinstall the boards for play. Repack with the case flat, seat each loaded tray within its stops, install both covers until caught, fold and close the hook. Do not tip an uncovered loaded tray.

## Compatibility

If you already have the previous V24 mechanical kit, **only board plate 02 changes**; reuse its bases, trays, hook, collar and pieces.

When upgrading from original V23, replace **both bases, both boards and the hook** together; add both trays. Do not mix old and revised halves. The larger supports interfere with the predecessor's board corner geometry. New loaded trays do not fit beneath old covers: the pieces would overlap the old roof by 0.8 mm. Original flats, the supplied V23 flat capstones, the hook collar and the 8.6 mm hook filament reference retain their geometry. Older sculpted/curled capstones and weighted flats remain unqualified.

The original V23 source and ZIP, all earlier kits and user-extracted folders remain intact. V24 now uses its own compatible four-colour boards; the old V23 inlay solids remain unsuitable for V24 hinge corners. The complete pre-inlay V24 kit is recoverable in the repository at `v24/REFERENCE/HISTORY/archive/tak-v24-before-board-inlays.zip`. See [build provenance](BUILD-PROVENANCE.md) for commands, dependencies, source hashes, checks and limitations.

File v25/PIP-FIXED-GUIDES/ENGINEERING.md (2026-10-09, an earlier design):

# Engineering and reproduction

Units: mm. Source parent `9eeef7bcd351c5c23f4851a763b39f779db867ea`; retained V24 reference `8085e9d79ffff3c69f07a1cca67595994237869e`. Current user clarification: remove the removable tray, retain **fixed guides**. This supersedes the earlier interpretation that removed all guides. Version remains V25; a V26 name was suggested but not selected.

The exact earlier tray guide shapes are `pocket_rims()` translated `(1,0,1.2)` and `capstone_rim()` translated `(1,-0.5,1.2)`, mirrored for the right. Each guide is fused individually into the floor with 0.01 mm overlap; exporting an overlapping compound as the fuse tool initially left multiple disconnected solids and was rejected by connectivity checks. The successful build must have exactly one solid per complete body. No tray floor or handles are added. Original nominal flat pockets have 0.35 mm clearance on each side. Guide top Z6.9 mm, floor Z3.4 mm, stone top Z11.4 mm. Grasp openings and rear fingertip access are retained. Physical fit is unverified.

Prior empty-well STEP bodies are included as hashed reference inputs under `reference/plain-bodies`; set-difference checks verify that all added body material is confined to the fixed guides, including unchanged PIP roots/pivots, outside dimensions and cover interfaces. Piece checks use the exact original flat-piece package: 42 Cat/Witch 20×20×8 mm flats and two supplied 8 mm V23 flat capstones. Straight removal is sampled at 1, 4, 8 and 12 mm; lateral restraint at four 3 mm shifts with 0.4 mm upward slack. These are rigid nominal checks, not loose packing or dump/transport simulations.

Use Python 3.12 and `../requirements.txt`. Run from the extracted kit or repository:

```sh
python v25/PIP-FIXED-GUIDES/source/build.py
python v25/PIP-FIXED-GUIDES/source/trial.py
python v25/PIP-FIXED-GUIDES/source/render.py
python v25/PIP-FIXED-GUIDES/source/slice.py
python v25/PIP-FIXED-GUIDES/source/slice.py --trial
python v25/PIP-FIXED-GUIDES/source/package.py
python v25/PIP-FIXED-GUIDES/source/reproduce.py
```

ElegooSlicer 2.4.2 is required at the recorded macOS application path. Reports record commands, dependency runtime and source/input/profile hashes. Geometry checks cover connected solids, guide material and seating/removal/restraint, fingertip access, cover sliding and sampled loaded folding, opposed axial capture, PIP clearance, roots, STEP/STL/3MF readback and bed bounds. Sliced readback verifies source meshes, profile settings and paired assembly grouping. The actual extrusion check samples radial gaps using conservative 0.50 mm beads and checks support centerline exclusion in each bearing cavity; continuous clearance and release force are unproven. Both projects retain build-plate-only supports, 0.8 mm support XY separation and no brim.

Fresh archive extraction rebuilds complete bodies and the hinge strip and compares all four meshes within 0.002 mm surface/size tolerance and 0.05 mm³ volume difference. Earlier kits and user-extracted folders remain untouched. Physical fit, grasping, dumping, hinge release/strength/fatigue, covered loaded retention and transport remain open. Material/profile changes require reslicing. No printer job is initiated.

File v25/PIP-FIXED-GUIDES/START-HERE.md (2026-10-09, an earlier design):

# V25: PIP hinges with fixed piece guides

**This is the latest fixed-guide body plate.** Each case half has **21 flat-stone positions and one capstone position**, permanently joined to the **3.4 mm case floor**. No removable tray or tray handle is printed. The older empty-well plate is preserved separately.

The guides use the earlier tray's layout and broad grasp openings. They stand **3.5 mm above the floor**, with tops at Z6.9 mm; an 8 mm stone projects **4.5 mm above them** for grasping. Nominal-piece CAD checks verify seating, straight upward removal, covered lateral restraint and rear fingertip access. Physical fit and dumping still need a print test.

The main hinge remains opposed captive **4 mm PIP pivots**, **0.4 mm radial/face clearance** and full-height **8 mm roots**. Both halves must print together as **one assembly**. Open each 3MF as a project in ElegooSlicer; do not auto-arrange or separate its components. No inserted axle is required for the main hinge; the retained side hook still uses its small filament pivot.

## Print projects

[Complete bodies with fixed guides](PRINT/01-V25-PIP-fixed-guides-CC2-PLA.3mf) estimates **9 hours 21 minutes / 163.69 g PLA** and prints two replacement bodies together, open flat. Both must be replaced as a pair. It prints no covers, hook, pieces or removable trays. The current V24 four-colour covers and side hook are reference/reuse candidates pending physical fit. Outside dimensions remain **102.5 × 200 × 35 mm**, with the same full 180 mm field and independent accent colours.

[Full-length PIP hinge trial](PRINT/02-V25-PIP-guided-hinge-trial-CC2-PLA.3mf) estimates **3 hours 7 minutes / 47.87 g PLA** and retains both opposed pivots, the continuous production-thickness spine and guide fragments from the actual bodies. It isolates hinge release and retention before the complete-body print; it does not test every stone pocket. Both components remain one assembly.

Let the print cool, remove accessible external supports and gently free the joint. Reject fusion, cracks or broken roots. Record play, both-direction axial pull and gentle twisting, then recheck after 20/100 cycles and overnight. Test each nominal stone position and capstone guide on the complete bodies. Do not force a tight fit. Cover fit, strength and loaded transport remain physical gates. No printer job has been started.

## Pack and empty

Use **42 original Cat/Witch 20 × 20 × 8 mm flats and two supplied 8 mm V23 flat capstones**, 21 flats and one capstone per side. Weighted/sculpted packages are unqualified. Place pieces individually in their guides in one layer, then slide the covers shut. Open on the table, slide off the covers and tip the pieces out. Keep a hand or the table ready to catch them. Dumping and repeated repacking remain untested physical actions.

The thin V24 cover catch, broad-lip change and selected rounded-cover underside still need complete-case integration. This revision adds fixed piece guides; its complete covers remain current V24 references. The remembered physically strong PIP version is unidentified; restored captive geometry and digital checks do not prove durability.

The PLA project retains the inherited bed-temperature warning (60°C textured bed / 45°C vitrification metadata). Match the actual spool/profile and reslice if settings change. [Engineering record](ENGINEERING.md).

[Guide close-up](previews/08-fixed-guide-detail.png) · [Empty fixed guides](previews/04-empty-fixed-guides.png) · [Loaded guides](previews/02-fixed-guides.png) · [Full game](previews/01-game-open.png) · [Closed](previews/03-closed.png).

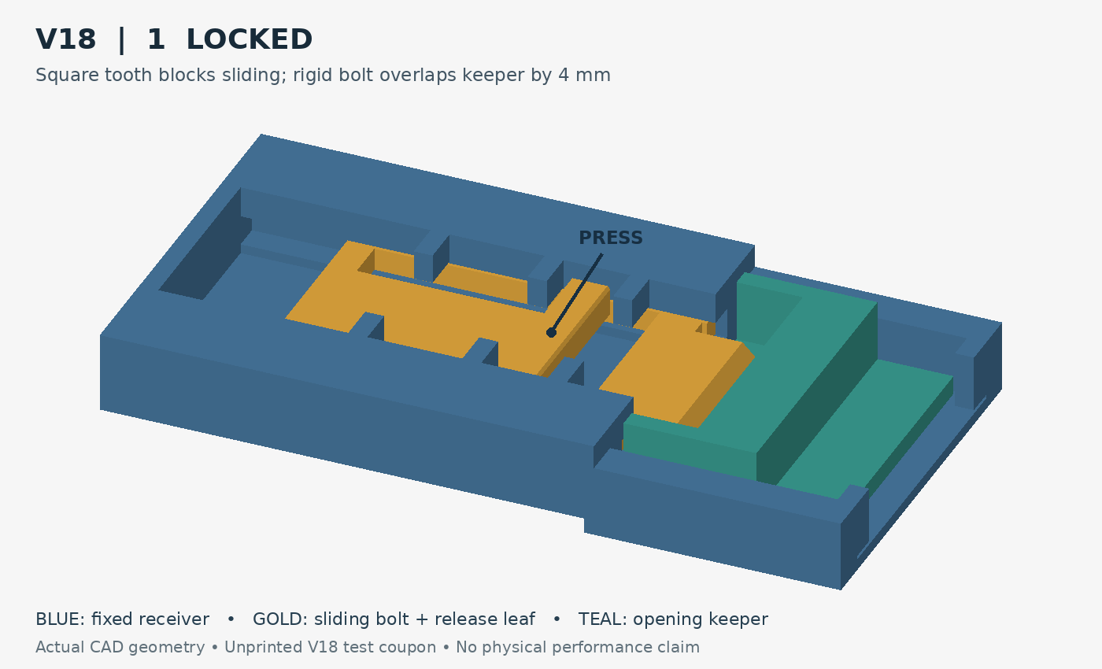
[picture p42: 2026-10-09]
v18-recessed-clasp/renders/1-assembled.png

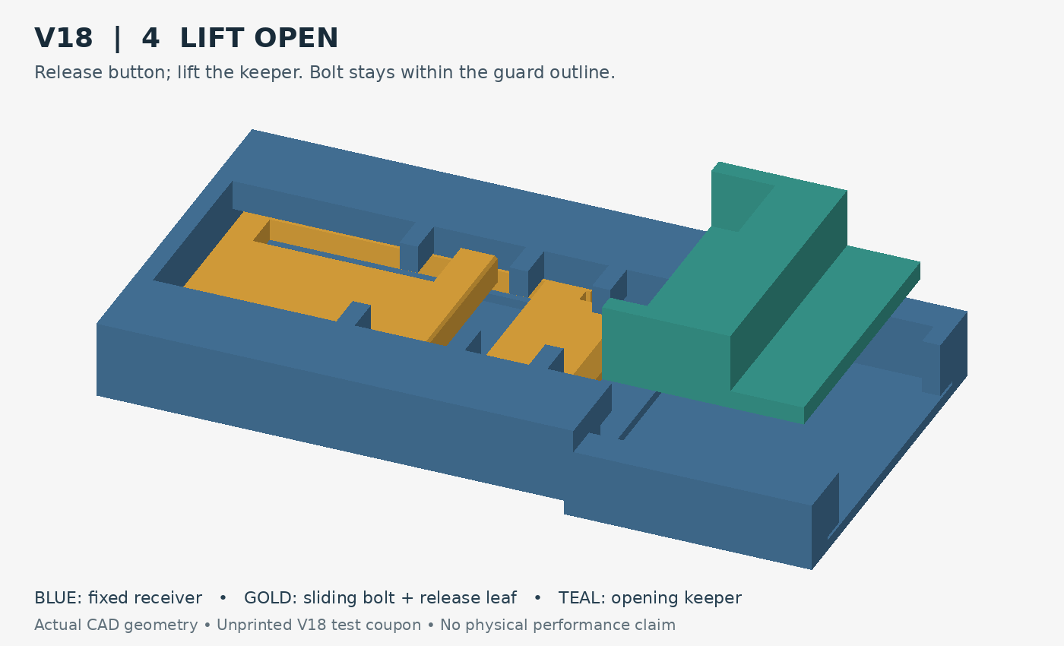
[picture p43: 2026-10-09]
v18-recessed-clasp/renders/4-assembled.png

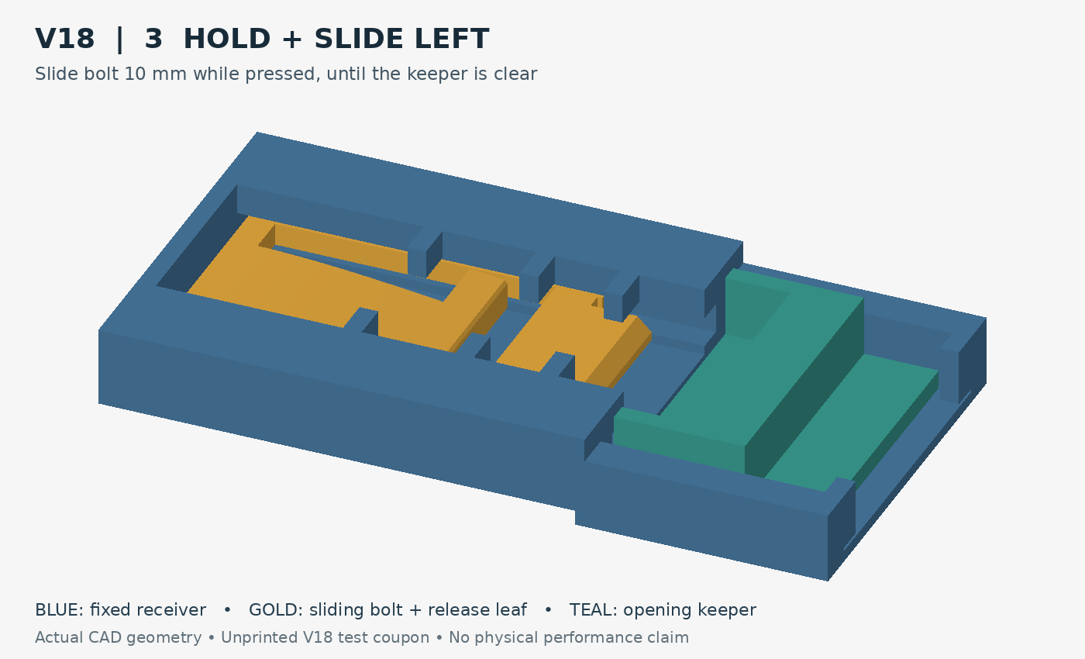
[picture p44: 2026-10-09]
v18-recessed-clasp/renders/3-assembled.png

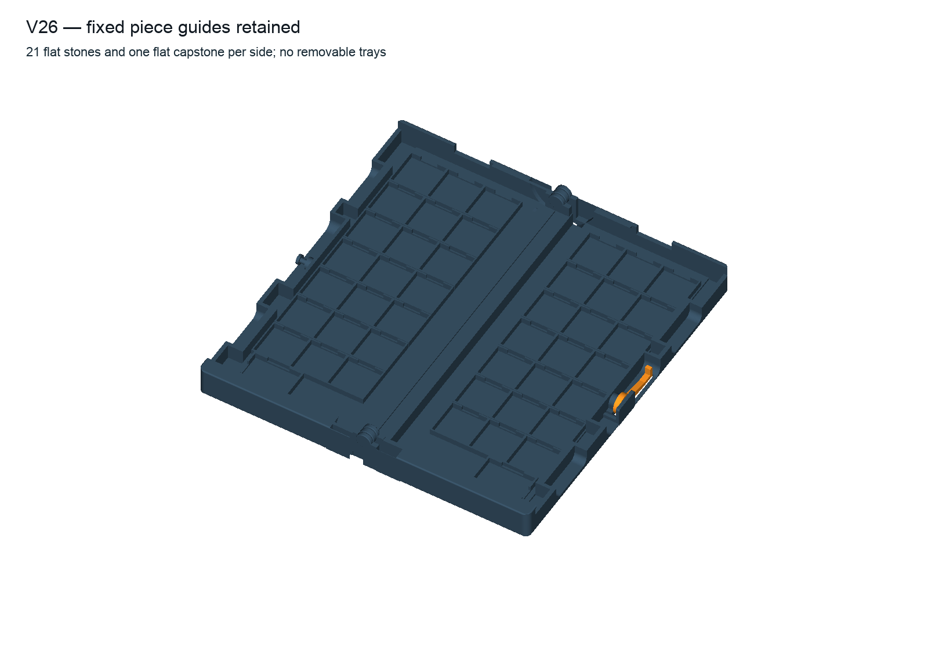
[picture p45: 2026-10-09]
v26/previews/06-fixed-guides.png

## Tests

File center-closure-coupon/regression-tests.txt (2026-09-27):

test_alternating_knuckles_keep_round_relief (test_center_leaf_fit.CenterLeafFitTest.test_alternating_knuckles_keep_round_relief) ... ok
test_closed_roof_fills_former_four_mm_gap (test_center_leaf_fit.CenterLeafFitTest.test_closed_roof_fills_former_four_mm_gap) ... ok
test_coupon_is_real_geometry_with_both_hinges (test_center_leaf_fit.CenterLeafFitTest.test_coupon_is_real_geometry_with_both_hinges) ... ok
test_end_skirts_fill_side_interfaces (test_center_leaf_fit.CenterLeafFitTest.test_end_skirts_fill_side_interfaces) ... ok
test_full_fold_and_skirt_clearance (test_center_leaf_fit.CenterLeafFitTest.test_full_fold_and_skirt_clearance) ... ok
test_round_skirt_profile_tracks_barrel_cutouts (test_center_leaf_fit.CenterLeafFitTest.test_round_skirt_profile_tracks_barrel_cutouts) ... ok
test_valid_solids_and_common_resting_plane (test_center_leaf_fit.CenterLeafFitTest.test_valid_solids_and_common_resting_plane) ... ok
test_validated_pin_axes_and_actual_bore_sizes (test_center_leaf_fit.CenterLeafFitTest.test_validated_pin_axes_and_actual_bore_sizes) ... <cadquery-env>/lib/python3.12/site-packages/cadquery/selectors.py:865: PyparsingDeprecationWarning: 'parseString' deprecated - use 'parse_string'
  parse_result = _expression_grammar.parseString(selectorString, parseAll=True)
<cadquery-env>/lib/python3.12/site-packages/pyparsing/util.py:466: PyparsingDeprecationWarning: 'parseAll' argument is deprecated, use 'parse_all'
  return fn(self, *args, **kwargs)
ok

----------------------------------------------------------------------
Ran 8 tests in 6.682s

OK

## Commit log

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2026-09-25 Redesign border cats as round faces with soft ears
    [black-grid-a-print.stl, tak-open-wells-v5-access.step, tak-open-wells-v5-cc2-00-fit-coupon.3mf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]
2026-09-25 Give border cats black faces with white outline and eyes
    Overlay-only change; white shells and lids are unchanged.
    [black-grid-a-print.stl, tak-open-wells-v5-access.step, tak-open-wells-v5-cc2-04-black-raised-grid.3mf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]
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2026-09-26 Turn the team capstones into pawns and add solid CC2 plates
    The slab capstones become revolved chess pawns (foot, waist, collar, head)
    that fit the round D19.8 x 25.4 keystone envelope in any roll: a cat head
    with conical ears and an engraved sleepy face, and a witch hat whose brim
    flares out of the waist, with a bent tip and an engraved band and star.
    Every overhang is 45 degrees or steeper, so they print upright without
    supports. The old slab capstones stay as *_slab for reference.
    Adds one Centauri Carbon 2 3MF per team (21 flats + pawn, one object per
    piece, orange and purple PETG, 4 walls, 100% infill, no supports), sliced
    clean at about 80 g and 3 h per plate. meshy_output/ (Meshy ref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
    [cat-capstone.step, cat-capstone.stl, cat-flat.step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]
2026-09-26 Add hinge experiments, a reworked case model and print coupons
    The v5 hinge bores are walled shut at both ends, so a filament pin can
    never be fed in. This explores replacements and keeps the case changes
    that are independent of the hinge type.
    - tak_hinges.py: 59 mm print-in-place cone-pin and snap-on hinge strips,
    plus a tuning plate (clearance 0.3/0.4/0.5 mm, snap mouth 2.3/2.5/2.7).
    - tak_case_pip.py: v5 case with pin-free hinges, a tile well cut to about
    half its volume (three 20.6 mm lanes split by dividers, so roofs bridge),
    a round-bottomed keystone pocket for the pawn, an open underside pan,
    and Ø4.2 x 2.2 magnet pockets for the 4 x 2 mm magnets (lid latches and
    fold ret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
    [case-hinge-coupon-plate.stl, frame-slice.stl, half-A.stl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]
2026-09-26 Sketch v6 case refinements: corner radius, lid lip, scoop, stone stop
    Layers four deferred improvements onto the v5 shell/lid geometry as an
    additive module (tak_case_v6.py), keeping the hinge mechanism untouched.
    A fifth idea, a center-row stiffening rib, was tried and reverted: it
    collides with the folded wings from 80-90 deg in the main fold sweep,
    since that space is reserved for the wings' own thickness when closed.
    Digital checks only (export_validate_v6.py): valid solids, lid and fold
    sweeps collision-free, pieces still clear of the new well features. Not
    sliced or printed.
    Claude-Session: https://claude.ai/code/session_01HvXm6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
    [tak-v6-sketch-access.step]
2026-09-26 Add full-board filament-pin case and CC2 print plates
    Rebuild the v5 case for 1.75 mm filament hinge pins as separate parts:
    center row, two wings, two lids. Pins sit snug in the fixed part
    (Ø1.90) and turn freely in the moving part (Ø2.20), and a press-in
    plug (Ø1.70 hole) goes at each end. These sizes come from the printed
    pin-fit coupon. Wings print bottom down so the wells need no supports,
    and supports start only from the bed so none grow inside a bore.
    Adds four CC2 3MF plates (80-83): center row with plugs, each wing with
    its lid, and the black grid.
    [black-grid-a.stl, black-grid-b.stl, black-grid-center.stl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]
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2026-09-28 Add Tak v13 book: board folds inside, two slide-out piece trays
    Two-leaf book with the board face inside when closed, a removable tray under
    each half sliding out of the front, print-in-place spine hinge, and an M3
    screw clasp. CAD source, fit trials and digital verification. Not printed.
    [assembly-closed.step, assembly-open.step, assembly-trays-out.step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]
2026-09-28 v13: raise the grid 0.4 mm, keep it as a second colour
    Grid lines sit 0.6 mm in the plate and 0.4 mm proud. The fold axis moves to
    the top of the lines so the raised grids meet when closed. Plates now print
    face up.
    [assembly-closed.step, assembly-open.step, assembly-trays-out.step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]
2026-09-28 v13: snap-in trays with push-button release
    A flexible arm in each tray's outer wall carries a button that locks in a
    window in the fore wall. A ramp snaps it in; pressing the recessed button
    releases it. Replaces the passive friction detent.
    [assembly-closed.step, assembly-open.step, assembly-trays-out.step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]
2026-09-28 Add Tak v14 field book: hidden snaps, no hardware
    Builds on v13. Replaces the M3 clasp with two hidden snap closures (posts on
    leaf A, in-layer spring arms in leaf B's back wall), thickens the floor skin,
    rounds corners and edges, adds a thumb groove and debossed TAK cover.
    [assembly-closed.step, assembly-open.step, assembly-trays-out.step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]
2026-09-28 v14: far-edge buckle with press-to-open side panel
    Replaces the back-border snap posts. A tab on leaf A pushes into a slot in
    leaf B's far corner and clicks under a catch; the catch hangs on a spring
    panel cut into B's side wall, so squeezing the side releases it.
    [assembly-closed.step, assembly-open.step, assembly-trays-out.step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]
2026-09-28 v14 README: fix stale snap-arm mention
2026-09-28 v14: sliced CC2 print plates
    Five one-colour 3MF projects plus G-code: fit trials, hinged bases, trays,
    white board plates, black grid inlays. No supports. Widens the panel and
    tray-arm slits, opens space under the catch ring for support-free printing,
    and adds 0.1 mm groove clearance for the separately printed grid.
    [assembly-closed.step, assembly-open.step, assembly-trays-out.step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]
2026-09-28 v14: black board, white grid, galaxy and swirl inlays, 4-colour plates
    Board plates now print black with a fused raised white grid, sparse white
    stars and small orange/purple galaxies in the cells, and orange (cat) and
    purple (witch) swirl vines in the borders. Tray fronts get matching low
    vines. Plates are 4-colour CC2 projects built from per-colour STLs.
    [assembly-closed.step, assembly-open.step, assembly-trays-out.step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]
2026-09-29 v14: bold cosmic tray art, protective lip for paint
    Tray floors get a bold leafy vine with tendrils, a crescent moon and white
    sparkles in the player colour; fronts get a smaller vine. Border vines gain
    leaves or berries. Adds a 1 mm raised lip on each board half's outer edges
    and moves the fold axis to its top, so closed painted faces stay 2 mm apart.
    Knuckles are rooted into the base below the raised axis.
    [assembly-closed.step, assembly-open.step, assembly-trays-out.step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]
2026-09-29 v14: drop the vines to save orange and purple filament
    Removes border, tray-floor and tray-front vines. Keeps the small board
    galaxies and a player-colour crescent moon per tray floor, with scattered
    white sparkles. Orange and purple use drops to about 2 g each.
    [assembly-closed.step, assembly-open.step, assembly-trays-out.step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]
2026-09-29 v14 README: correct total print time
2026-09-29 Tidy repo: current v14 at top, pieces self-contained, older work archived
    Moves the loose v5-v7 scripts, CAD, coupons, profiles and plates into
    archive/v5-v7 (flat, so their relative imports still work) and v13 into
    archive/v13-book. Gathers the piece CAD, scripts, plates and profiles into
    pieces/ with paths fixed. Removes a stray slicer log, adds a short index
    README.
    [assembly-closed.step, assembly-open.step, assembly-trays-out.step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]
2026-09-29 v14: pepper the board with planets, moons, sparkles, comets and coloured stars
    Each board half keeps its two spiral galaxies and gains a ringed planet, a
    crescent moon, a four-point sparkle and a comet, two orange and two purple,
    each in a cell the galaxies leave empty. Three star dots per half turn orange
    or purple, a little larger so they read on black.
    Rebuilt STEP/STL, previews, reports and the four sliced plates. All
    verify_book and verify_meshes checks pass. Plate 03 is now 1 h 46 min.
    [assembly-closed.step, assembly-open.step, assembly-trays-out.step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]
2026-09-29 Add v15 field book: 28 mm cells, self-locating board plates
    A paper play test showed v14's 24 mm cells were too cramped, so v15 grows
    them to 28 mm (140 mm field). The book is now 81 x 162 x 48 mm closed.
    Art, buckle, spring panel and glue wells are tied to the board edges, so
    the cell size is one constant.
    The board plates now locate themselves for gluing: two pegs on each base
    (round on the back wall, small on the fore wall in a slot) and eight
    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
    [assembly-closed.step, assembly-open.step, assembly-trays-out.step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]
2026-09-29 v15: taller, wider board-plate pegs; logged one-command build
    The 1 mm pegs were too small to see or feel at dry fit. They are now 1.4 mm
    tall, 3.0 mm (back) and 2.0 mm (fore wall) across. The plate is only 2 mm
    thick, so the 1.6 mm sockets leave 0.4 mm (two layers) of roof;
    verify_book.py now checks that roof is solid, with no grid or art cut into
    it. Still no supports: pegs print upward, sockets open onto the bed.
    Adds source/build_all.py, which runs every build step in order, timestamps
    each line, writes logs/build-<time>.log and stops at the first failure.
    render_book.py and package_plates.py now report what they are working on.
    Models, STLs, plates, gcode and reports regenerated.
    Co-A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
    [assembly-closed.step, assembly-open.step, assembly-trays-out.step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]
2026-09-29 v16: 36 mm cells, inlaid white grid, capstone cradle
    v15 was too small to play on: with 8.5 mm between stones a stack couldn't be
    grabbed once the board filled up.
    - Cell pitch 28 -> 36 mm (16 mm between stones); trays respaced so stacks
    stand at least 12 mm apart and shortened to 132 mm
    - White grid inlaid flush instead of raised
    - Real pieces: 20 mm flats and the 19.4 mm pawn capstone, which did not fit
    v15's trays; each tray gets a 0.4 mm cradle and is 1.4 mm taller (closed
    book 51 mm). verify_book now fits the real STEP pieces
    - Glue wells, buckle catch, plate positions and renders rescaled
    - v15 moved to archive/
    [assembly-closed.step, assembly-open.step, assembly-trays-out.step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]
2026-09-29 v16: cross ribs behind each tray
    The 132 mm trays leave ~60 mm of empty chamber at the back of each base,
    where the 2 mm floor and 2 mm board plate span 92 mm unsupported.
    - Two 1.2 mm cross ribs per base (y = 152 and 170 mm), floor to plate seat,
    so the plate rests on them and the back section becomes ~20 mm bays
    - Ribs stay 19.4 mm clear of the tray and 3.6 mm clear of leaf B's buckle
    panel slit; verify_book gains a cross-ribs check for this
    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
    [assembly-closed.step, assembly-open.step, assembly-trays-out.step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]
2026-09-30 v16: add drop-in tray inserts (20.0 mm pockets for 19.5 mm flats, pawn stop)
    Separate part for the already-printed trays; tray, bases and plates unchanged.
    Plate 04 prints one of each mirrored insert. verify_book checks fit against the
    tray, pressed latch arm, plate and real pawn.
    [plate04-tray-inserts-black.3mf, tray-insert-a.stl, tray-insert-b.stl]
2026-09-30 v16 tray insert: three drop-in channels instead of 11 pockets
    Stacks drop in anywhere along a column and slide together, so nothing has to be
    lined up in two axes. Channels are sized to their stacks (+0.5 mm) so a full
    tray doesn't rattle; the pawn stop doubles as the pawn-side channel's end wall.
    [plate04-tray-inserts-black.3mf, tray-insert-a.stl, tray-insert-b.stl]
2026-09-30 v16 base: tray-end bulkhead and spine rib for stiffness
    Base only; trays, plates, pegs, wells and seat height untouched (their STLs are
    byte-identical). Plate 01 re-sliced: 5 h 20 min, 178 g.
    [bases-hinged-print-in-place.stl, plate01-hinged-bases-black.3mf]
2026-09-30 v16 tray insert: four flat-flat lanes, 21st-flat pocket and pawn saddle
    The flats are loaded lying flat in one layer (4 across, 5 deep), not as standing
    stacks. Lanes are 20.0 mm for the 19.5 mm printed flats; the pawn gets a stop and
    side walls (left wall starts past the pressed latch arm). Checked against the
    real pawn and 21 flats packed to both ends of every lane.
    [plate04-tray-inserts-black.3mf, tray-insert-a.stl, tray-insert-b.stl]
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2026-09-30 v16 base: cut the debossed TAK on the cover
    Its 0.7 mm text caused print problems. Base B only; plate 01 re-sliced
    (5 h 18 min, 178 g). Trays, plates and inserts are unchanged.
    [bases-hinged-print-in-place.stl, plate01-hinged-bases-black.3mf]
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2026-10-04 Replace confusing draw-latch trial with labeled two-part squeeze buckle
    [01-boards-cap-compartment-and-latch-trial.3mf, 02-drawer-housings.3mf, 03-piece-drawers.3mf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]
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2026-10-05 Design V20 flat-printing fixed storage and sliding lids
    [machine.json]
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2026-10-05 Build V21 with sliding playing boards over fixed storage
    [machine.json]
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2026-10-06 Reinforce V23 hinges and add removable loaded player trays
    [machine.json]
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2026-10-06 Name reinforced hinge and removable tray revision V24
    [machine.json]
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2026-10-06 piece-generator-v1: verify clearance-fit assembly as compound
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2026-10-08 Replace V25 removable trays with fixed wells and reinforce B trial
    [01-V25-fixed-storage-bodies-CC2-PLA.3mf, 01-V25-fixed-storage-bodies.3mf, 01-V25-reinforced-B-CC2-PLA.3mf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]
2026-10-08 V25: restore captive PIP hinges in fixed storage bodies
    [01-V25-PIP-fixed-storage-CC2-PLA.3mf, 01-V25-PIP-fixed-storage.3mf, 02-V25-PIP-hinge-trial-CC2-PLA.3mf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]
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2026-10-08 V25: restore fixed piece guides in PIP case bodies
    [01-V25-PIP-fixed-guides-CC2-PLA.3mf, 01-V25-PIP-fixed-guides.3mf, 02-V25-PIP-guided-hinge-trial-CC2-PLA.3mf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]
2026-10-08 Add V26 reinforced board clip and captive hook trials
    [01-V26-PIP-guides-and-hook.3mf, 01-V26-captive-hook-trial-CC2-PLA.3mf, 01-V26-captive-hook-trial.3mf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]
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2026-10-08 docs: flag V26 main hinge mismatch pending correction
2026-10-08 Fix V26 captive main hinges and round outer corners
    [01-V26-PIP-guides-and-hook-CC2-PLA.3mf, 01-V26-PIP-guides-and-hook.3mf, 02-V26-FULL-SIZE-FOUR-COLOUR-tab-free-boards-CC2-PLA.3mf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]
2026-10-08 Add weighted snap-floor Cat and Witch sample fitted to V26
    [Tak-SAMPLE-WEIGHTED-Cat-Witch-slots-3-4.3mf, Tak-SAMPLE-WEIGHTED-geometry.3mf, cat-capstone-assembled.step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]
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
